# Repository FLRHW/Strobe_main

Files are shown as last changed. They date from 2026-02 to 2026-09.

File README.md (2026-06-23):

<h1 align="center">Main board</h1>

<p align="center" width="100%">
  <a href="https://github.com/FLRHW/Strobe_main/actions/workflows/ci.yaml">
    
  </a>
</p>

<p align="center" width="100%">
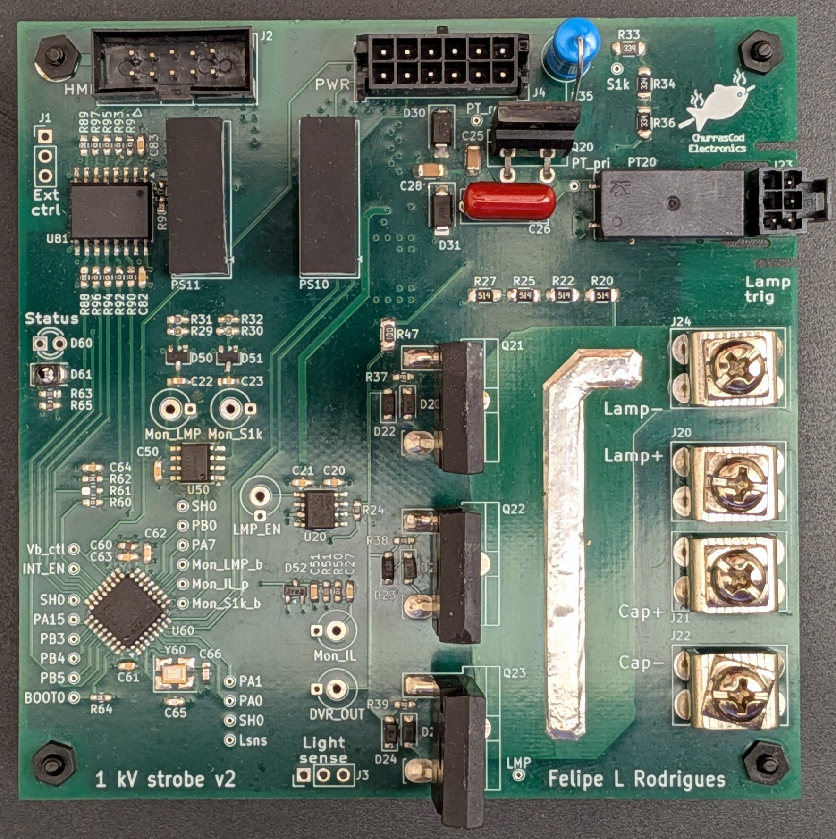
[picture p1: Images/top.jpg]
    
</p>

***

<p align="center">
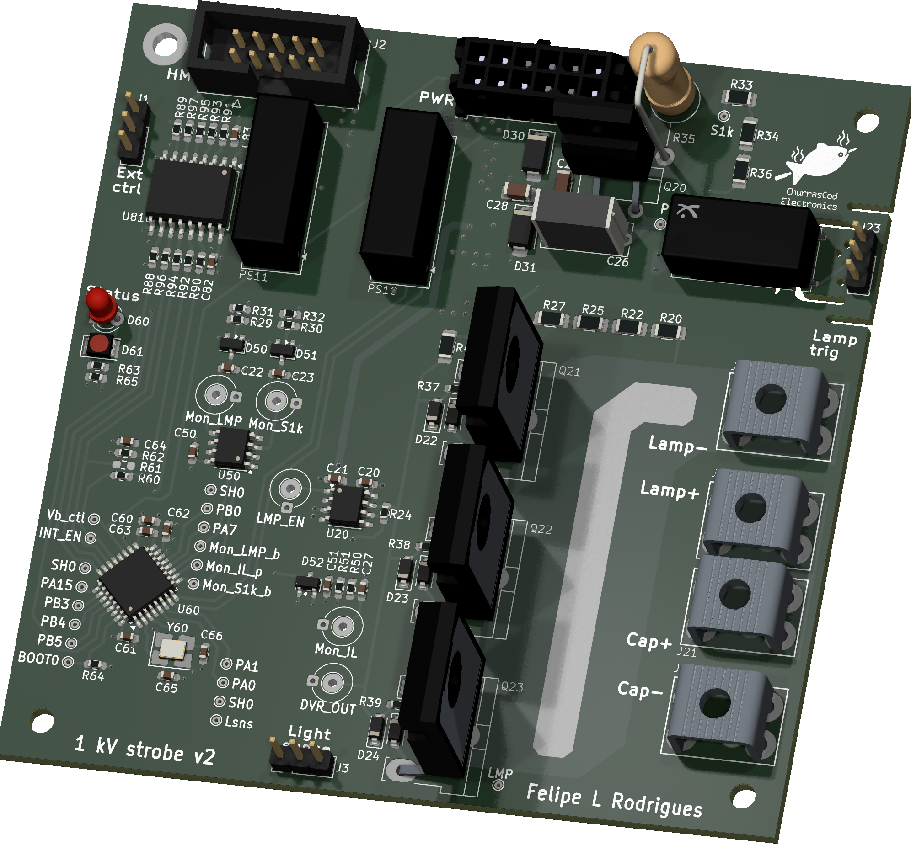
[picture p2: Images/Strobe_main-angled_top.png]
3D Top Angled
  
&nbsp; &nbsp; &nbsp; &nbsp;
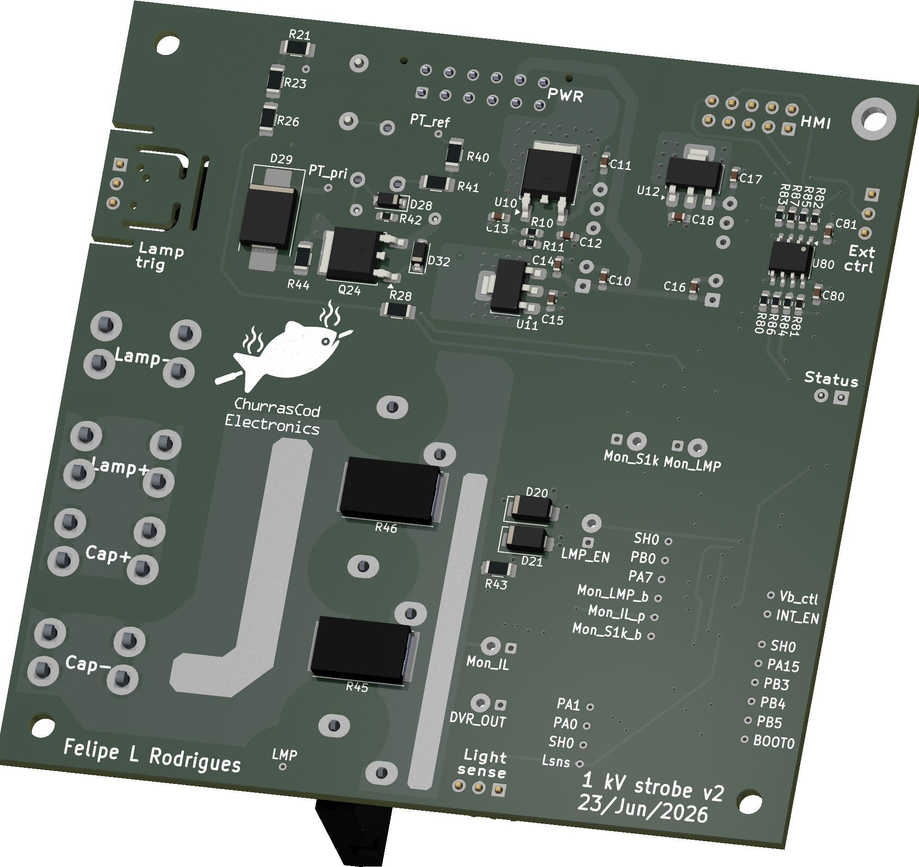
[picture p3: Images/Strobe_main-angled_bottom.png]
3D Bottom Angled
  
</p>

***

# **1 kV strobe - Intro**
Since my teenage years I spend a great chunk of my spare time on hobby electronics. Back then, much of that time was to build FM transmitters, audio amplifiers and strobe lights. I was always pushing my builds as much as I could, (i.e., extracting pressurised smoke from capacitors!) as an attempt to make the flashes ever brighter. It was somewhat challenging given the limited experience and resources I had at the time, but a lot of fun nonetheless.
Life went on, priorities changed and for a long time I did not "play" with strobe lights... until recently, after I saw a large XOP-15 bulb for sale and, well, nostalgy happened.

While defining the project scope, I had to decide if I'd use the good old Xenon bulb or move to LEDs, as these have greatly evolved and are ubiquitous nowadays, making their way to commercial strobes (https://www.martin.com/en/products/atomic-3000-led). I have decided to stick to vintage tech, as in my mind this would bring more interesting power electronics challenges due to high voltages and high peak currents required when the lamp is ionised.

So that's what this repo contains: a Xenon-based strobe light, aiming to drive a XOP-15 bulb with up to 1 kV, while controlling the duration and frequency of pulses.

## Project overview
This repository contains KiCad v9 design files for the main board of a Xenon-based strobe light system.
The system is divided into three separate modules:

- Main board. This board drives the Xenon bulb, generating the trigger pulse and actively interrupting the discharge according to the required pulse width. The latest STM32 source code is kept on a separate repository:  
https://github.com/FLRHW/Strobe_main_source  

- HMI board. This is the user interface, to capture desired operating conditions (bus voltage, pulse width and pulse frequency). That board is covered on a separate repository:  
https://github.com/FLRHW/Strobe_HMI  

- Power supply. This is to produce an adjustable DC supply and to realise that I intend to eventually design an AC-mains powered converter, including a PFC circuit. As an interim solution, off-the-shelf boost converter modules are used: two such modules are connected in series, each providing up to 450 V output while supplied by 12 V batteries. As a side project, the boost modules have been reverse engineered with the aim to modify them from non-isolated to isolated. This work is covered under the following repos:
https://github.com/FLRHW/StepUp_module_12to450V  
https://github.com/FLRHW/Isolated_12to450V.

## Design targets
DC bus voltage: 400 V to 1000 V  
Flash rate: 0.1 Hz to 200 Hz  
Pulse duration: 20 μs to 10 ms  

Please note that the above parameters are only the limits encoded in the software. This design relies on storing energy on a capacitor bank to then discharge it into the bulb, so, even though the limit in software for the pulse duration is 50 % of the period, long durations might be unachievable. The duration strongly depends on the lamp, capacitor bank and bus voltage. As an example, with the XOP-15 and a 400 uF bank charged to 700 V, the discharge current reaches 450 A and the bank voltage collapses in less than 1 ms. Additionally, the HV power supply will determine how fast the capacitor bank is recharged, limiting the flash rate and/or pulse duration.

## Intended use
This repository is intended for:
* Educational use and study of the circuit;
* Integration into hobby or research projects.

## License
The design files and documentation in this repository are released under the CERN Open Hardware Licence v2 – Permissive (CERN‑OHL‑P‑2.0). SPDX identifier: CERN-OHL-P-2.0 See the LICENSE file for the full legal text and conditions.
In short and non‑legal terms, you are free to use, modify, manufacture, and distribute hardware based on these files, provided you respect attribution requirements and the terms in the license.

## Trademarks and third‑party rights
All product names, logos, and brands eventually mentioned are the property of their respective owners and are not included or licensed here.
Any reference to third‑party marks is purely descriptive and does not imply endorsement or affiliation.

## Safety and disclaimer
* The author takes no responsibility for any injury, death or damage arising from the use, direct or indirect, of the design or otherwise any information from this repository
* You shall not build this or any prototype based on this design unless you are absolutely sure of your abilities dealing with this type of circuit
* High voltage can cause injury, death, or damage to equipment. Ensure appropriate protections and testing procedures are followed
* The design is provided as is, with no warranty of any kind
* Users are responsible for checking any patent, copyright, or regulatory constraints that may apply to their own use

## Known issues / improvement potentials
- To be updated once prototype is tested

***

## DIRECTORY STRUCTURE
    │
    ├─ Computations       # Misc calculations
    ├─ HTML               # HTML files for generated webpage
    ├─ Images             # Pictures and renders
    │
    ├─ kibot_resources    # External resources for KiBot
    │  ├─ colors          # Color theme for KiCad
    │  ├─ fonts           # Fonts used in the project
    │  ├─ scripts         # External scripts used with KiBot
    │  └─ templates       # Templates for KiBot generated reports
    │
    ├─ kibot_yaml         # KiBot YAML config files
    ├─ KiRI               # KiRI (PCB diff viewer) files
    │
    ├─ lib                # KiCad footprint and symbol libraries
    │  ├─ 3d_models       # Component 3D models
    │  ├─ lib_fp          # Footprint libraries
    │  └─ lib_sym         # Symbol libraries
    │
    ├─ Logos              # Logos
    │
    ├─ Manufacturing      # Assembly and fabrication documents
    │  ├─ Assembly        # Assembly documents (BoM, pos, notes)
    │  │
    │  └─ Fabrication     # Fabrication documents (ZIP, notes)
    │     ├─ Drill Tables # CSV drill tables
    │     └─ Gerbers      # Gerbers
    │
    ├─ Report             # Reports for ERC/DRC
    ├─ Schematic          # PDF of schematic
    ├─ Templates          # Title block templates
    ├─ Testing
    │  └─ Testpoints      # Testpoints tables      
    │
    └─ Variants           # Outputs for assembly variants

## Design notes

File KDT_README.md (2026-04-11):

<h1 align="center">KiCad 8/9 Template for CI/CD with KiBot</h1>

<p align="center">
  <a href=https://www.kicad.org/>
    Light
  </a>
&nbsp; &nbsp; &nbsp; &nbsp;
  <a href=https://kibot.readthedocs.io/en/latest/>
    Dark
  </a>
</p>

A **KiCad 8/9** template for **automated**, professional documentation generation with **Continuous Integration and Continuous Development** (CI/CD) using [KiBot](https://github.com/INTI-CMNB/KiBot/tree/master).

A video tutorial for setting up this template is available [here](https://www.youtube.com/watch?v=63R6Wnx44uY).

An example project using this template can be found [here](https://github.com/nguyen-v/amulet_controller_kibot/tree/master).

> [!NOTE]
> This file will be overridden by a KiBot run.

## TABLE OF CONTENTS

- [TABLE OF CONTENTS](#table-of-contents)
- [FEATURES](#features)
- [GETTING STARTED](#getting-started)
- [USAGE](#usage)
  - [CI/CD Workflow and Semantic Versioning](#cicd-workflow-and-semantic-versioning)
  - [Running Locally](#running-locally)
  - [Calculating Board Costs (KiCost)](#calculating-board-costs-kicost)
  - [Visualizing Outputs in a Webpage](#visualizing-outputs-in-a-webpage)
- [PROJECT CONVERSION GUIDE](#project-conversion-guide)
  - [Folders](#folders)
  - [Schematic](#schematic)
  - [PCB](#pcb)
  - [Summary in table format](#summary-in-table-format)
- [DIRECTORY STRUCTURE](#directory-structure)
- [CREDITS](#credits)
- [RESOURCES](#resources)
- [CONTRIBUTING](#contributing)

## FEATURES

- **Automated fabrication document**: [Example](https://github.com/nguyen-v/amulet_controller_kibot/blob/master/Manufacturing/Fabrication/amulet_controller-fabrication.pdf). The stackup table, fabrication notes, drill drawings/tables, testpoint tables/highlighting are all automated.
  
- **Automated assembly document**: [Example](https://github.com/nguyen-v/amulet_controller_kibot/blob/master/Manufacturing/Assembly/amulet_controller-assembly.pdf). The images, tables, DNP crosses, texts are all automated.

- **Automated table of contents** in schematic

- **Automated 3D images** of the PCB in various documents

- **Synchronised `CHANGELOG.md`** with Revision History page of the schematic

- **Automated README.md**: images and other board information

- **Various outputs** such as gerbers, 3D renders, ERC/DRC reports, BoM, Diff visualizer

- **Modern webpage** for visualizing the generated files and documents

- **Robust workflow** with two branches and semantic versioning

- **Releases with changelog** and assets

- **Can be run locally** with Docker

## GETTING STARTED

1. Go to your KiCad templates folder
   
    **Windows**:

    ```
    cd "C:\Program Files\KiCad\8.0\share\kicad\template"
    ```

    **Linux**:
    ```
    cd /usr/share/kicad/template
    sudo chmod 777 ./
    ```

2. Clone the repository

    ```
    git clone git@github.com:nguyen-v/KDT_Hierarchical_KiBot.git
    ```

3. Install the fonts inside of [`kibot_resources/fonts`](kibot_resources/fonts) if not already installed on the system.

4. A custom color theme ([`Altium_Theme.json`](kibot_resources/colors/Altium_Theme.json)) is also provided in [`kibot_resources/colors`](kibot_resources/colors).
You should move this file to your KiCad Themes folder.

    **Windows**:

    `C:\Users\<USER_NAME>\AppData\Roaming\kicad\8.0\colors`

    **Linux**:

    `~/.config/kicad/8.0/colors`

> [!NOTE]
> In the steps above, replace ```8.0``` with ```9.0``` for KiCad 9

5. Create a new project with:

    **File → New Project From Template** and select `KDT_Hierarchical_KiBot`

> [!CAUTION]
> Under Linux, the ```.github``` folder from the template needs to be copied at the root of the project directory, as it is not copied when creating a project from a template in KiCad.

6. Create a new `dev` branch. This will be the working branch. 
   
   ```
   git checkout -b dev
   ```
   
7. Modify the following fields in [`kibot_main.yaml`](kibot_yaml/kibot_main.yaml#L556) according to your project:
    ```
      # Metadata ===================================================================

      PROJECT_NAME: Project Name
      BOARD_NAME: Board Name

      COMPANY: Company Name
      DESIGNER: Author

      LOGO: 'Logos/dummy_logo.png'
      GIT_URL: 'https://github.com/nguyen-v/KDT_Hierarchical_KiBot'

      # Preflight ==================================================================

      CHECK_ZONE_FILLS: false
      STACKUP_TABLE_NOTE: external layer thicknesses are specified after plating

      # BoM ========================================================================

      MPN_FIELD: 'Manufacturer Part Number'
      MAN_FIELD: 'Manufacturer'

      # Drill table and drill map parameters =======================================

      GROUP_ROUND_SLOTS: true  # whether or not to group round holes and slots
      GROUP_PTH_NPTH: 'no'  # for drill tables (CSV, PCB Print)
      GROUP_PTH_NPTH_DRL: false  # for .drl files

      # Gerber parameters ==========================================================

      PLOT_REFS: true # reference designators

      # Schematic parameters =======================================================

      COLOR_THEME: Altium_Theme
      SHEET_WKS: ${KIPRJMOD}/Templates/KDT_Template_PCB_GIT_A4.kicad_wks
      FAB_SCALING: 1
      ASSEMBLY_SCALING: 1

      # References to exclude from testpoint highlighting ==========================
      
      EXCLUDE_REFS: '[MB*]' # for components on the PCB but not on the schematic

      # 3D Viewer rotations (in steps) =============================================

      3D_VIEWER_ROT_X: 2
      3D_VIEWER_ROT_Y: -1
      3D_VIEWER_ROT_Z: 1
      3D_VIEWER_ZOOM: -1
      KEY_COLOR: '#00FF00' # background color to remove
    ```

8. The files inside of [`kibot_resources/templates`](kibot_resources/templates) should also be modified according to your project. These include Assembly and Fabrication notes, Impedance table and README file templates.

9. Edit the [`*.kicad_dru`](KDT_Hierarchical_KiBot.kicad_dru) if necessary according to your design rules. Right now, it has been set for PCBWay 6-layer PCBs with 2oz outer 1oz inner, focusing on lowest cost.

10.  Edit the [`kibot_out_csv_bom.yaml`](kibot_yaml/kibot_out_csv_bom.yaml), [`kibot_out_html_bom.yaml`](kibot_yaml/kibot_out_html_bom.yaml) and [`kibot_out_xlsx_bom.yaml`](kibot_yaml/kibot_out_xlsx_bom.yaml) files according to the component fields that you use. You can refer to the [KiCost Documentation](https://hildogjr.github.io/KiCost/docs/_build/singlehtml/index.html) for the field names.

## USAGE

### CI/CD Workflow and Semantic Versioning

This template is meant to be used in a CI/CD environment on GitHub. The workflow is as follows:

- Any custom font used in the project must be added to the [`kibot_resources/fonts`](kibot_resources/fonts) folder.

> [!NOTE]
> KiCad 9 allows for fonts to be embedded in the schematic. However, it is still good practice to add the fonts in the folder mentioned.

- There are two branches, a `main` and a `dev` branch. The `dev` branch is the working branch. The `main` should only be used for pull requests and releases.

- Changes should be recorded in the [`CHANGELOG.md`](CHANGELOG.md) file, and should respect [semantic versioning guidelines](https://semver.org/) for [hardware](https://www.maskset.net/blog/2023/02/26/semantic-versioning-for-hardware/). The changes of the current version should be added under the `[Unreleased]` section.

- The `variant` variable in [.github/workflows/ci.yaml](.github/workflows/ci.yaml#L21) should be selected according to the project progress.

  ```
    # Used variant. We assume:
    # DRAFT: only schematic in progress, will only generate schematic PDF, netlist and BoM
    # PRELIMINARY: will generate both schematic and PCB documents, but no ERC/DRC
    # CHECKED: will generate both schematic and PCB documents, with ERC/DRC
    # RELEASED: similar to CHECKED, automatically selected when pushing a tag to master

    kibot_variant: CHECKED  
  ```

- The `kicad_version` variable in [.github/workflows/ci.yaml](.github/workflows/ci.yaml#L24) should be selected according to the desired KiCad version. Supported versions are 8 and 9.

- You should work locally on the `dev` branch. When a change is made, the changes should be pushed to GitHub which will trigger the KiBot workflow. The generated files will be committed and pushed back to the repository.

- After a successful KiBot run on the remote repository, you should pull back the changes into your local repository.

- To avoid conflicts, you should avoid modifying the `.kicad_pro` file locally before pulling from the remote (after the completion of a KiBot run). Otherwise, you will need to solve merge conflicts when pulling the file.

- To synchronise the Revision History of the schematic with the `CHANGELOG.md` file, you should create new text variables in [kibot_pre_set_text_variables.yaml](kibot_yaml/kibot_pre_set_text_variables.yaml#L39). The text variables should then be added in the text boxes of the Revision History sheet.

  ```
  - variable: '@RELEASE_TITLE_VAR@x.x.x'
    command: '@GET_TITLE_CMD@ x.x.x'
  - variable: '@RELEASE_BODY_VAR@x.x.x'
    command: '@GET_BODY_CMD@ x.x.x'
  ```

- When ready for a release, you should open a pull request and merge the changes into main. Currently the workflow is set **not to trigger on pull requests**, as we assume the changes coming from `dev` are up-to-date.

- To create a release, push a tag on the `main` branch with the version number (for example `x.x.x = 1.1.1`):

  ```
  git checkout main
  git pull
  git tag x.x.x
  git push origin x.x.x
  ```

  This will start a KiBot run with the variant set as `RELEASED`. When the run completes, it also creates a release with assets and updates the `CHANGELOG.md` file (renames the `[Unreleased]` section with the pushed tag and creates a new `[Unreleased]` section).

- After a release, you will need to update your `main` branch to be up-to-date with the remote:

  ```
  git pull
  ```

  And you will also need to rebase your `dev` branch to the `main` branch:

  ```
  git checkout dev
  git rebase main
  ```

> [!NOTE]
> You are free to modify the [.github/workflows/ci.yaml](.github/workflows/ci.yaml) file to suit your workflow needs.

***

### Running Locally

KiBot can be installed if you want to run some of the scripts locally. If you only plan to use it in a CI/CD workflow, this step can be skipped.
Installation steps can be found on the [official documentation](https://kibot.readthedocs.io/en/master/installation.html). 
The easiest way to install KiBot if custom development is not required is with dockers.

1.  Install **and run** [Docker Desktop](https://docs.docker.com/desktop/)
  
2.  Run the script `docker_kibot_windows.bat` or `docker_kibot_linux.sh` depending on your platform in [`kibot_resources/scripts`](kibot_resources/scripts). Currently tested on Windows and WSL2. This should pull and start a docker running the `dev` branch of KiBot. You should have access to your local files.

***
**KiCad 8**

  Windows:

  ```
  .\docker_kibot_windows.bat
  ```

  Linux:

  ```
  ./docker_kibot_linux.sh
  ```

***
**KiCad 9**

  Windows:

  ```
  .\docker_kibot_windows.bat -v 9
  ```

  Linux:

  ```
  ./docker_kibot_linux.sh -v 9
  ```
  ***

Once in the docker, you can use the [`kibot_launch.sh`](kibot_launch.sh) script to generate and visualize outputs.

```
./kibot_launch.sh
```

You can get more information about the usage with

```
./kibot_launch.sh --help
```

When running the script with no arguments, it will default to the `CHECKED` variant and generate all outputs. A variant can be set with the `-v` flag. If a custom variant is used (i.e. other than the default variants `DRAFT`, `PRELIMINARY`, `CHECKED`, `RELEASED`), the outputs will be generated in the `Variants` folder.

Each default variant will have different KiBot flags, which is useful for different phases of the project:

1. **DRAFT**
  
   Only schematic in progress, will only generate schematic PDF, netlist and BoM

2. **PRELIMINARY**
   
   Will generate both schematic and PCB documents, but no ERC/DRC

3. **CHECKED**
   
   Will generate both schematic and PCB documents, with ERC/DRC

4. **RELEASED**
   
   Similar to CHECKED, automatically selected when pushing a tag to main (CI/CD)

> [!WARNING]
> When generating outputs locally, it could conflict with the outputs generated by the remote CI/CD workflow. In this case, you should decide how to resolve the conflicts.

***

### Calculating Board Costs (KiCost)

[KiCost](https://github.com/hildogjr/KiCost) is used to estimate costs and get a nice XLSX spreadsheet with part specs. In this project, we run KiCost locally to avoid too many API calls. Also, DigiKey's API [doesn't seem to work](https://github.com/set-soft/kicost_ci_test) in a CI/CD environment.
To run KiCost, you will need to create a file `kicost_config_local.yaml` in [`kicost_yaml`](kicost_yaml). You can use the [`kicost_config_local_template.yaml`](kicost_yaml/kicost_config_local.yaml) file as a base. Once you have filled in the API keys for the desired manufacturers, KiCost can be run with:

```
./kibot_launch.sh --costs
```
This will create a spreadsheet in [`Manufacturing/Assembly`](Manufacturing/Assembly/) folder.

You can also specify a variant if desired:

```
./kibot_launch.sh -v <VARIANT> --costs
```

For more information, please have a look at the official [documentation](https://hildogjr.github.io/KiCost/docs/_build/singlehtml/index.html)

> [!CAUTION]
> KiCost expects the **MPN (Manufacturer Part Number)** and **Manufacturer** fields to be named in a certain way. To cater for different naming conventions, we rename user-defined fields to KiCost-compatible fields in the KiBot run. You can set your user-defined field for **MPN** and **Manufacturer** in the [`kibot_yaml/kibot_main.yaml`](kibot_yaml/kibot_main.yaml#L576) by editing the `MPN_FIELD` and `MAN_FIELD` definitions.

<p align="center">
  XLSX BoM
</p>

<p align="center">
  XLSX Costs
</p>

<p align="center">
  XLSX Specs
</p>

***

### Visualizing Outputs in a Webpage

The outputs of KiBot can be visualized in a webpage (excepted for the `DRAFT` variant). This can be done by running:

```
./kibot_launch.sh --server
```
And opening `http://localhost:8000` in your favorite browser. The server can be shut down with:
```
./kibot_launch.sh --stop-server
```

> [!TIP]
> You can also give the port as an argument if you want to use another port.

<p align="center">
  Web Page
</p>

## PROJECT CONVERSION GUIDE

This section will describe the necessary steps to convert an existing project to work with this template. This will also give more insights into how the template works in general. For more information, you should refer to the template.

***

### Folders

You should keep the folder structure as defined in [DIRECTORY STRUCTURE](#directory-structure). The folders marked as optional are not mandatory for the project to work, as long as the relevant file paths are correct (e.g. logos). You should then go through the same steps as in [GETTING STARTED](#getting-started) and [USAGE](#usage).

### Schematic

You should select [`Templates/KDT_Template_GIT.kicad_wks`](Templates/KDT_Template_GIT.kicad_wks) as your Drawing Sheet in:

**File → Page Settings → Drawing Sheet**

On the same page, The `Revision` and `Company` fields should be set to `${REVISION}` and `${COMPANY}` and exported to all sheets.

<p align="center">
  Drawing Sheet
</p>

For an automated table of contents, you should copy the root page of the template into your project, or use the `${SHEET_NAME_X}` text variables. These variables will be replaced by the sheet name (page `X`) when running KiBot. Currently the maximum number of pages is set to 40. You are free to add new text variables in [`kibot_yaml/kibot_pre_set_text_variables`](kibot_yaml/kibot_pre_set_text_variables.yaml#L160).

The `${VARIANT}` text variable is replaced by the current variant name (e.g. DRAFT or RELEASED). 

The `${RELEASE_DATE}` and `${RELEASE_DATE_NUM}` will be replaced by the tag release date and are just the same date in different formats (for example, `${RELEASE_DATE} = 17-Dec-2024` and `${RELEASE_DATE_NUM} = 2024-12-17`).

To get 3D pictures of the PCB in the schematic, you can create text boxes with the desired size, with the following names: `kibot_image_png_3d_viewer_angled_top` and `kibot_image_png_3d_viewer_angled_bottom`.

<p align="center">
  kibot_image_png_3d_viewer_angled_top, kibot_image_png_3d_viewer_angled_bottom
</p>

> You can add any image generated by a KiBot output using by changing the name to `kibot_image_<output_name>`.

To synchronise the Revision History of the schematic with the `CHANGELOG.md` file, you should create new text variables in [kibot_pre_set_text_variables.yaml](kibot_yaml/kibot_pre_set_text_variables.yaml#L39). The text variables (`${RELEASE_TITLE_VAR<VERSION>}` and `${RELEASE_BODY_VAR<VERSION>`) should then be added in the text boxes of the Revision History sheet.

  ```
  - variable: '@RELEASE_TITLE_VAR@x.x.x'
    command: '@GET_TITLE_CMD@ x.x.x'
  - variable: '@RELEASE_BODY_VAR@x.x.x'
    command: '@GET_BODY_CMD@ x.x.x'
  ```

***

### PCB

The layer names of the PCB should follow the ones defined in [kibot_main.yaml](kibot_yaml/kibot_main.yaml#L631). 

```
  LAYER_TITLE_PAGE: TitlePage
  LAYER_DNP_TOP: F.DNP
  LAYER_DNP_BOTTOM: B.DNP
  LAYER_DRILL_MAP: DrillMap
  LAYER_TP_LIST_TOP: F.TestPointList
  LAYER_TP_LIST_BOTTOM: B.TestPointList
  LAYER_ASSEMBLY_TEXT_TOP: F.AssemblyText
  LAYER_ASSEMBLY_TEXT_BOTTOM: B.AssemblyText
  LAYER_DNP_CROSS_TOP: F.DNP
  LAYER_DNP_CROSS_BOTTOM: B.DNP
```

<p align="center">
  PCB Layer Names
</p>

The layer names can be set in 

**File → Board Setup → Board Stackup → Board Editor Layers**

Each layer has a specific function, and must be setup in a particular way.

In the following explanation, when a group must be created, this can be done using KiCad's **Draw Rectangle** tool, and then a group can be created with:

**Right-Click → Grouping → Group Items**

Pressing **E** then allows you to rename the group. The size and position of the group usually determines the size and location of the element to be drawn. To change the font inside a group, you can create a textbox with the desired font in the group. You can set the border width to 0.

<p align="center">
  Textbox Group
</p>

***

**TitlePage**

This is used for the first page of the assembly document. Here, you should add **Top View** and **Bottom View** texts and under these text, you can create two named groups with the location and size that you desire. The groups should be named `kibot_image_png_3d_viewer_angled_top` and `kibot_image_png_3d_viewer_angled_bottom`.

> [!TIP]
> You can add any image generated by a KiBot output using by changing the name to `kibot_image_<output_name>`.

<p align="center">
  TitlePage
</p>

<p align="center">
  kibot_image_png_3d_viewer_angled_top
&nbsp; &nbsp; &nbsp; &nbsp;
  kibot_image_png_3d_viewer_angled_bottom
</p>

***

**User.Comments**

Currently not used, you can use it for your project.

***

**F.DNP** and **B.DNP**

These are used to hold the red crosses for components marked as *Do Not Populate*. The layers for those should be kept empty.

***

**DrillMap**

This layer is used to draw drill map drawings and drill tables in the fabrication document. You should create a named group called `kibot_table_csv_drill_table` and place it where the drill tables should be drawn for each drill layer pair. The drill drawing is by default aligned with the PCB.

<p align="center">
  DrillMap
  kibot_table_csv_drill_table
</p>

***

**F.TestPoint** and **B.TestPoint**

These layers are used to highlight testpoint locations in the fabrication document. They should be left as empty.

***

**F.AssemblyText**

This layer is used to hold information about the number of components, assembly notes, assembly drawing and 3D render of the top of the PCB. For the number of components, you should create a group named `kibot_table_csv_comp_count`. Assembly notes should be added using the text variable `${ASSEMBLY_NOTES}`. The 3D render can be added by creating a group named `kibot_image_png_3d_viewer_top`.

<p align="center">
  F.AssemblyText
  kibot_image_png_3d_viewer_top
</p>

<p align="center">
  kibot_table_csv_comp_count
&nbsp; &nbsp; &nbsp; &nbsp;
  ${ASSEMBLY_NOTES}
</p>

**B.AssemblyText**

This layer hold the assembly drawing and 3D render for the backside of the PCB. For the 3D render, you should add a group named `kibot_image_png_3d_viewer_bottom`.

***

**F.Dimensions**

This layer holds information about the PCB stackup and dimensions, impedance table and fabrication notes. The PCB stackup can be added by creating a group named `kibot_fancy_stackup`. The impedance table with a group named `kibot_table_csv_impedance_table` and the fabrication notes are included with the text variable `${FABRICATION_NOTES}`.

> [!NOTE]
> The text variable ${FABRICATION_NOTE} is dependent on the [`kibot_resources/templates/fabrication_notes.txt`](kibot_resources/templates/fabrication_notes.txt) file. Modify it to your needs.

<p align="center">
  F.Dimensions
  kibot_fancy_stackup
</p>

<p align="center">
  kibot_table_csv_impedance_table
  ${FABRICATION_NOTES}
</p>

**B.Dimensions**

This layer contains information about the dimensions of the PCB, seen from the backside. Similarly to the front side, you can use KiCad's **Dimensions** tool to add some dimensions.

<p align="center">
  B.Dimensions
</p>

***

**F.TestPointList**

This layer is used to hold information about the testpoints locations and nets. You can add testpoint tables by creating a group named `kibot_table_csv_testpoints_top`. It is also possible to use python slicing to separate the table into multiple tables, by using slice operators in the name. For example: `kibot_table_csv_testpoints_top[:32]` and `kibot_table_csv_testpoints_top[32:]` in two different groups would create two tables with the first one including the first 32 testpoints and the second one every testpoint after that.

Test point locations are computed from the drill origin, which can be set with:

**Place → Drill/Place File Origin**.

> [!TIP]
> It is usually good practice to set the origin at the bottom left of the board.

<p align="center">
  F.TestPointList
</p>

<p align="center">
  kibot_table_csv_testpoints_top[:32]
&nbsp; &nbsp; &nbsp; &nbsp;
  kibot_table_csv_testpoints_top[32:]
</p>

**B.TestPointList**

Similar to the front testpoint layer. The group should be named `kibot_table_csv_testpoints_bottom`. Note that because PCB is inverted for this layer during print, if the group is placed on the left side it will be printed on the right side.

<p align="center">
  B.TestPointList
</p>

<p align="center">
  kibot_table_csv_testpoints_bottom
</p>

***

### Summary in table format

| **Layer** | **Description** | **Changes/Included Items** |
|---|---|---|
| **TitlePage** | First page of the assembly document. | Add groups: `kibot_image_png_3d_viewer_angled_top` and `kibot_image_png_3d_viewer_angled_bottom`. |
| **User.Comments** | Reserved for project-specific comments. | Not used by default; customize as needed. |
| **F.DNP / B.DNP** | Holds red crosses for components marked as *Do Not Populate*. | Keep these layers empty. |
| **DrillMap** | Draws drill map drawings and tables in the fabrication document, aligned by default with the PCB.  | Add group: `kibot_table_csv_drill_table`. |
| **F.TestPoint / B.TestPoint** | Highlights testpoint locations in the fabrication document. | Keep these layers empty. |
| **F.AssemblyText** | Contains component count, assembly notes, drawings, and 3D renders for the top side of the PCB. | Add group: `kibot_table_csv_comp_count` (table) and `kibot_image_png_3d_viewer_top` (image). Include `${ASSEMBLY_NOTES}` text.|
| **B.AssemblyText** | Holds assembly drawings and 3D render for the bottom side of the PCB. | Add group: `kibot_image_png_3d_viewer_bottom` for the 3D render. |
| **F.Dimensions** | Holds PCB stackup, dimensions, impedance table, and fabrication notes. | Add groups: `kibot_fancy_stackup` (stackup), `kibot_table_csv_impedance_table` (impedance table), and `${FABRICATION_NOTES}`. |
| **B.Dimensions** | Holds dimensions of the PCB, seen from the backside. | Use KiCad **Dimensions** tool to add details. |
| **F.TestPointList** | Lists testpoint locations and nets for the top layer. | Add group: `kibot_table_csv_testpoints_top`. Use slicing (e.g., `[:32]`) for multiple tables. |
| **B.TestPointList** | Lists testpoint locations and nets for the bottom layer. | Add group: `kibot_table_csv_testpoints_bottom`. Adjust left-side placements for inverted print alignment. |

## DIRECTORY STRUCTURE
The following directory structure is used in the template. Folders marked as 'optional' are not crucial for KiBot to work. Other folders will be generated automatically during a KiBot run.

```
├─ Computations       # Misc calculations (optional)
├─ HTML               # HTML files for generated webpage
├─ Images             # Pictures and renders
│
├─ kibot_resources
│  ├─ colors          # Color theme for KiCad
│  ├─ fonts           # Fonts used in the project
│  ├─ scripts         # External scripts used with KiBot
│  └─ templates       # Templates for KiBot generated reports
│
├─ kibot_yaml         # KiBot YAML config files
├─ KiRI               # KiRI (PCB diff viewer) files
│
├─ lib                # Footprint and symbol libraries (optional)
│  ├─ 3d_models       # Component 3D models
│  ├─ lib_fp          # Footprint libraries
│  └─ lib_sym         # Symbol libraries
│
├─ Logos              # Logos (optional)
│
├─ Manufacturing
│  ├─ Assembly        # Assembly documents (BoM, pos, notes)
│  │
│  └─ Fabrication     # Fabrication documents (ZIP, notes)
│     ├─ Drill Tables # CSV drill tables
│     └─ Gerbers      # Gerbers
│
├─ Report             # Reports for ERC/DRC
├─ Schematic          # PDF of schematic
├─ Templates          # Title block templates
├─ Testing
│  └─ Testpoints      # Testpoints tables      
│
└─ Variants           # Outputs for assembly variants (optional)
```

## CREDITS

[@set-soft](https://github.com/set-soft) for his amazing work on [KiBot](https://github.com/INTI-CMNB/KiBot/tree/master). Check out the [documentation](https://kibot.readthedocs.io/en/latest/) for more!

## RESOURCES

- [Video Tutorial for this template](https://www.youtube.com/watch?v=63R6Wnx44uY)

- [Example project (from the video tutorial)](https://github.com/nguyen-v/KiBot_Project_Test)

- [Example project (Amulet)](https://github.com/nguyen-v/amulet_controller_kibot/tree/master)

- [(Outdated) Best practices and tips for good schematics](https://www.youtube.com/watch?v=_ZjyeltLMAg)

- [GitHub Actions Documentation](https://docs.github.com/en/actions)

- [KiBot Documentation](https://kibot.readthedocs.io/en/latest/)

- [KiBot Repository](https://github.com/INTI-CMNB/KiBot)

- [KiCost Documentation](https://hildogjr.github.io/KiCost/docs/_build/singlehtml/index.html)

- [KiCost Repository](https://github.com/hildogjr/KiCost)

- [KiRI Repository](https://github.com/leoheck/kiri)

## CONTRIBUTING

Feel free to open a pull request if you have any cool features to add!

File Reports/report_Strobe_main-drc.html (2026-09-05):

Logo

(https://github.com/INTI-CMNB/KiBot/) | DRC report for Strobe_main
| PCB: Strobe_main Revision: 2.0.1 Date: 2026-09-05T13:06:58+0000 KiCad Version: 9.0.7 | Errors: 0 Warnings: 23 Total: 23

Violations

Type | Description | Details
lib_footprint_issues | The current configuration does not include the footprint library 'Personal'. | @(180.77 mm, 100.0 mm): Footprint TP22
lib_footprint_issues | The current configuration does not include the footprint library 'Personal'. | @(199.5 mm, 136.0 mm): Footprint TP20
lib_footprint_issues | The current configuration does not include the footprint library 'Personal'. | @(251.0 mm, 135.5 mm): Footprint J22
lib_footprint_issues | The current configuration does not include the footprint library 'Personal'. | @(199.5 mm, 128.5 mm): Footprint TP28
lib_footprint_issues | The current configuration does not include the footprint library 'Personal'. | @(254.5 mm, 72.73 mm): Footprint H22
lib_footprint_issues | The current configuration does not include the footprint library 'Personal'. | @(251.0 mm, 121.0 mm): Footprint J21
lib_footprint_issues | The current configuration does not include the footprint library 'Personal'. | @(255.5 mm, 71.5 mm): Footprint H20
lib_footprint_issues | The current configuration does not include the footprint library 'Personal'. | @(243.0 mm, 74.0 mm): Footprint PT20
lib_footprint_issues | The current configuration does not include the footprint library 'Personal'. | @(251.0 mm, 109.5 mm): Footprint J20
lib_footprint_issues | The current configuration does not include the footprint library 'Personal'. | @(191.0 mm, 112.5 mm): Footprint TP21
lib_footprint_issues | The current configuration does not include the footprint library 'Personal'. | @(251.0 mm, 95.0 mm): Footprint J24
lib_footprint_issues | The current configuration does not include the footprint library 'Personal'. | @(218.5 mm, 99.0 mm): Footprint Q21
lib_footprint_issues | The current configuration does not include the footprint library 'Personal'. | @(200.04 mm, 73.04 mm): Footprint PS10
lib_footprint_issues | The current configuration does not include the footprint library 'Personal'. | @(225.5 mm, 66.5 mm): Footprint Q20
lib_footprint_issues | The current configuration does not include the footprint library 'Personal'. | @(183.54 mm, 73.04 mm): Footprint PS11
lib_footprint_issues | The current configuration does not include the footprint library 'Personal'. | @(188.5 mm, 100.0 mm): Footprint TP23
lib_footprint_issues | The current configuration does not include the footprint library 'Personal'. | @(255.5 mm, 76.5 mm): Footprint H21
lib_footprint_issues | The current configuration does not include the footprint library 'Personal'. | @(218.5 mm, 141.0 mm): Footprint Q23
lib_footprint_issues | The current configuration does not include the footprint library 'Personal'. | @(218.5 mm, 120.0 mm): Footprint Q22
lib_footprint_issues | The current configuration does not include the footprint library 'Personal'. | @(216.5 mm, 131.0 mm): Footprint R45
lib_footprint_issues | The current configuration does not include the footprint library 'Personal'. | @(216.5 mm, 110.0 mm): Footprint R46

Schematic parity

Type | Description | Details
footprint_symbol_mismatch | Value (C22) doesn't match symbol value (100n). | @(180.5 mm, 96.5 mm): Footprint C22
footprint_symbol_mismatch | Value (C23) doesn't match symbol value (100n). | @(187.0 mm, 96.5 mm): Footprint C23

Generated by KiBot (https://github.com/INTI-CMNB/KiBot/) v1.9.2

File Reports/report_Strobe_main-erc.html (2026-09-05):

Logo

(https://github.com/INTI-CMNB/KiBot/) | ERC report for Strobe_main
| Schematic: Strobe_main Revision: 2.0.1 Date: 2026-09-05T13:06:51+0000 KiCad Version: 9.0.7 | Errors: 0 Warnings: 239 Total: 239

Sheet / (Strobe_main.kicad_sch)

Type | Description | Details
lib_symbol_issues | The current configuration does not include the symbol library 'personal' | @(0.4826 mm, 0.9144 mm): Symbol P1 [Cosmetic_PWR]
lib_symbol_issues | The current configuration does not include the symbol library 'personal' | @(0.4826 mm, 0.9906 mm): Symbol P10 [Cosmetic_PWR_SRC]
lib_symbol_issues | The current configuration does not include the symbol library 'personal' | @(0.4826 mm, 1.1049 mm): Symbol P15 [Cosmetic_GND2]
lib_symbol_issues | The current configuration does not include the symbol library 'personal' | @(0.9144 mm, 0.9144 mm): Symbol P2 [Cosmetic_PWR_SRC]
lib_symbol_issues | The current configuration does not include the symbol library 'personal' | @(0.9144 mm, 0.9906 mm): Symbol P11 [Cosmetic_PWR_SRC]
lib_symbol_issues | The current configuration does not include the symbol library 'personal' | @(0.9144 mm, 1.1049 mm): Symbol P16 [Cosmetic_GND]
lib_symbol_issues | The current configuration does not include the symbol library 'personal' | @(1.1176 mm, 0.9144 mm): Symbol P4 [Cosmetic_PWR]
lib_symbol_issues | The current configuration does not include the symbol library 'personal' | @(1.1176 mm, 0.9906 mm): Symbol P12 [Cosmetic_PWR]
lib_symbol_issues | The current configuration does not include the symbol library 'personal' | @(1.1176 mm, 1.2573 mm): Symbol P18 [Cosmetic_GND]
lib_symbol_issues | The current configuration does not include the symbol library 'personal' | @(1.6256 mm, 1.0668 mm): Symbol P14 [Cosmetic_PWR]
lib_symbol_issues | The current configuration does not include the symbol library 'personal' | @(1.6256 mm, 1.2573 mm): Symbol P19 [Cosmetic_GND]
lib_symbol_issues | The current configuration does not include the symbol library 'personal' | @(1.3589 mm, 1.8796 mm): Symbol P28 [Cosmetic_GND]
lib_symbol_issues | The current configuration does not include the symbol library 'personal' | @(2.1336 mm, 0.9144 mm): Symbol P5 [Cosmetic_PWR]
lib_symbol_issues | The current configuration does not include the symbol library 'personal' | @(1.6891 mm, 1.6637 mm): Symbol P23 [Cosmetic_IN]
lib_symbol_issues | The current configuration does not include the symbol library 'personal' | @(1.7272 mm, 1.778 mm): Symbol P25 [Cosmetic_PWR_SRC]
lib_symbol_issues | The current configuration does not include the symbol library 'personal' | @(1.7272 mm, 1.8796 mm): Symbol P29 [Cosmetic_GND]
lib_symbol_issues | The current configuration does not include the symbol library 'personal' | @(1.8796 mm, 1.8796 mm): Symbol P31 [Cosmetic_PWR_SRC]
lib_symbol_issues | The current configuration does not include the symbol library 'personal' | @(2.6416 mm, 0.9144 mm): Symbol P6 [Cosmetic_PWR]
lib_symbol_issues | The current configuration does not include the symbol library 'personal' | @(2.1336 mm, 1.905 mm): Symbol P30 [Cosmetic_GND]
lib_symbol_issues | The current configuration does not include the symbol library 'personal' | @(2.6416 mm, 1.5875 mm): Symbol P21 [Cosmetic_GND]
lib_symbol_issues | The current configuration does not include the symbol library 'personal' | @(3.0734 mm, 0.9144 mm): Symbol P7 [Cosmetic_PWR]
lib_symbol_issues | The current configuration does not include the symbol library 'personal' | @(3.2766 mm, 0.9652 mm): Symbol P9 [Cosmetic_OUT]
lib_symbol_issues | The current configuration does not include the symbol library 'personal' | @(3.0734 mm, 1.5875 mm): Symbol P22 [Cosmetic_GND2]
lib_symbol_issues | The current configuration does not include the symbol library 'personal' | @(3.3401 mm, 1.2192 mm): Symbol P17 [Cosmetic_PWR]
lib_symbol_issues | The current configuration does not include the symbol library 'personal' | @(3.4544 mm, 0.9271 mm): Symbol P8 [Cosmetic_PWR]
lib_symbol_issues | The current configuration does not include the symbol library 'personal' | @(3.4544 mm, 1.016 mm): Symbol P13 [Cosmetic_GND2]
lib_symbol_issues | The current configuration does not include the symbol library 'personal' | @(3.3401 mm, 1.5367 mm): Symbol P20 [Cosmetic_GND2]
lib_symbol_issues | The current configuration does not include the symbol library 'personal' | @(3.2512 mm, 1.778 mm): Symbol P26 [Cosmetic_OUT]
lib_symbol_issues | The current configuration does not include the symbol library 'personal' | @(3.4544 mm, 1.7399 mm): Symbol P24 [Cosmetic_PWR]
lib_symbol_issues | The current configuration does not include the symbol library 'personal' | @(3.4544 mm, 1.8288 mm): Symbol P27 [Cosmetic_GND]
lib_symbol_issues | The current configuration does not include the symbol library 'personal' | @(0.3302 mm, 0.2413 mm): Symbol P32 [Cosmetic_PWR_SRC]
lib_symbol_issues | The current configuration does not include the symbol library 'personal' | @(0.3302 mm, 0.3175 mm): Symbol P33 [Cosmetic_PWR]
lib_symbol_issues | The current configuration does not include the symbol library 'personal' | @(0.3302 mm, 0.3937 mm): Symbol P37 [Cosmetic_PWR]
lib_symbol_issues | The current configuration does not include the symbol library 'personal' | @(0.3302 mm, 0.4572 mm): Symbol P38 [Cosmetic_GND]
lib_symbol_issues | The current configuration does not include the symbol library 'personal' | @(0.3302 mm, 0.5461 mm): Symbol P39 [Cosmetic_PWR]
lib_symbol_issues | The current configuration does not include the symbol library 'personal' | @(0.3302 mm, 0.6096 mm): Symbol P47 [Cosmetic_GND2]
lib_symbol_issues | The current configuration does not include the symbol library 'personal' | @(1.016 mm, 0.3683 mm): Symbol P34 [Cosmetic_PWR]
lib_symbol_issues | The current configuration does not include the symbol library 'personal' | @(1.0414 mm, 0.5969 mm): Symbol P40 [Cosmetic_GND]
lib_symbol_issues | The current configuration does not include the symbol library 'personal' | @(1.016 mm, 0.7493 mm): Symbol P48 [Cosmetic_PWR]
lib_symbol_issues | The current configuration does not include the symbol library 'personal' | @(1.1684 mm, 0.5969 mm): Symbol P41 [Cosmetic_GND]
lib_symbol_issues | The current configuration does not include the symbol library 'personal' | @(1.2827 mm, 0.4064 mm): Symbol PS10 [B0524S-2W]
lib_symbol_issues | The current configuration does not include the symbol library 'personal' | @(1.0414 mm, 0.889 mm): Symbol P50 [Cosmetic_GND]
lib_symbol_issues | The current configuration does not include the symbol library 'personal' | @(1.1938 mm, 0.889 mm): Symbol P51 [Cosmetic_GND]
lib_symbol_issues | The current configuration does not include the symbol library 'personal' | @(1.016 mm, 1.1303 mm): Symbol P53 [Cosmetic_PWR]
lib_symbol_issues | The current configuration does not include the symbol library 'personal' | @(1.4097 mm, 0.5969 mm): Symbol P42 [Cosmetic_GND]
lib_symbol_issues | The current configuration does not include the symbol library 'personal' | @(1.4986 mm, 0.3683 mm): Symbol P35 [Cosmetic_PWR_SRC]
lib_symbol_issues | The current configuration does not include the symbol library 'personal' | @(1.3589 mm, 0.7493 mm): Symbol P49 [Cosmetic_PWR_SRC]
lib_symbol_issues | The current configuration does not include the symbol library 'personal' | @(1.3081 mm, 0.889 mm): Symbol P52 [Cosmetic_GND]
lib_symbol_issues | The current configuration does not include the symbol library 'personal' | @(1.524 mm, 0.5969 mm): Symbol P43 [Cosmetic_GND]
lib_symbol_issues | The current configuration does not include the symbol library 'personal' | @(1.0414 mm, 1.27 mm): Symbol P56 [Cosmetic_GND]
lib_symbol_issues | The current configuration does not include the symbol library 'personal' | @(1.1684 mm, 1.27 mm): Symbol P57 [Cosmetic_GND]
lib_symbol_issues | The current configuration does not include the symbol library 'personal' | @(1.2827 mm, 1.1684 mm): Symbol PS11 [B0505S-2W]
lib_symbol_issues | The current configuration does not include the symbol library 'personal' | @(1.6637 mm, 0.5969 mm): Symbol P44 [Cosmetic_GND]
lib_symbol_issues | The current configuration does not include the symbol library 'personal' | @(1.4986 mm, 1.1303 mm): Symbol P54 [Cosmetic_PWR_SRC]
lib_symbol_issues | The current configuration does not include the symbol library 'personal' | @(1.4097 mm, 1.27 mm): Symbol P58 [Cosmetic_GND2]
lib_symbol_issues | The current configuration does not include the symbol library 'personal' | @(1.524 mm, 1.27 mm): Symbol P59 [Cosmetic_GND2]
lib_symbol_issues | The current configuration does not include the symbol library 'personal' | @(1.8923 mm, 0.5969 mm): Symbol P45 [Cosmetic_GND]
lib_symbol_issues | The current configuration does not include the symbol library 'personal' | @(2.0574 mm, 0.3683 mm): Symbol P36 [Cosmetic_PWR_SRC]
lib_symbol_issues | The current configuration does not include the symbol library 'personal' | @(2.0066 mm, 0.5969 mm): Symbol P46 [Cosmetic_GND]
lib_symbol_issues | The current configuration does not include the symbol library 'personal' | @(1.6764 mm, 1.27 mm): Symbol P60 [Cosmetic_GND2]
lib_symbol_issues | The current configuration does not include the symbol library 'personal' | @(1.8415 mm, 1.1303 mm): Symbol P55 [Cosmetic_PWR_SRC]
lib_symbol_issues | The current configuration does not include the symbol library 'personal' | @(1.7907 mm, 1.27 mm): Symbol P61 [Cosmetic_GND2]
lib_symbol_issues | The current configuration does not include the symbol library 'personal' | @(0.3302 mm, 0.2413 mm): Symbol P62 [Cosmetic_PWR_SRC]
lib_symbol_issues | The current configuration does not include the symbol library 'personal' | @(0.3302 mm, 0.3175 mm): Symbol P66 [Cosmetic_PWR_SRC]
lib_symbol_issues | The current configuration does not include the symbol library 'personal' | @(0.3302 mm, 0.4826 mm): Symbol P73 [Cosmetic_GND]
lib_symbol_issues | The current configuration does not include the symbol library 'personal' | @(0.4826 mm, 0.3556 mm): Symbol P67 [Cosmetic_OUT]
lib_symbol_issues | The current configuration does not include the symbol library 'personal' | @(0.4826 mm, 0.381 mm): Symbol P68 [Cosmetic_IN]
lib_symbol_issues | The current configuration does not include the symbol library 'personal' | @(0.4826 mm, 0.4064 mm): Symbol P69 [Cosmetic_IN]
lib_symbol_issues | The current configuration does not include the symbol library 'personal' | @(0.4826 mm, 0.4318 mm): Symbol P71 [Cosmetic_IN]
lib_symbol_issues | The current configuration does not include the symbol library 'personal' | @(0.7874 mm, 0.2667 mm): Symbol P64 [Cosmetic_PWR]
lib_symbol_issues | The current configuration does not include the symbol library 'personal' | @(0.8382 mm, 0.4699 mm): Symbol P72 [Cosmetic_IN]
lib_symbol_issues | The current configuration does not include the symbol library 'personal' | @(0.7874 mm, 0.635 mm): Symbol P75 [Cosmetic_GND]
lib_symbol_issues | The current configuration does not include the symbol library 'personal' | @(0.9652 mm, 0.5461 mm): Symbol TP21 [OscTestpoint]
lib_symbol_issues | The current configuration does not include the symbol library 'personal' | @(0.9652 mm, 0.635 mm): Symbol P76 [Cosmetic_GND]
lib_symbol_issues | The current configuration does not include the symbol library 'personal' | @(1.1176 mm, 0.635 mm): Symbol P77 [Cosmetic_GND]
lib_symbol_issues | The current configuration does not include the symbol library 'personal' | @(0.889 mm, 1.0414 mm): Symbol P88 [Cosmetic_PWR]
lib_symbol_issues | The current configuration does not include the symbol library 'personal' | @(1.2827 mm, 0.635 mm): Symbol P78 [Cosmetic_GND]
lib_symbol_issues | The current configuration does not include the symbol library 'personal' | @(1.4859 mm, 0.4699 mm): Symbol TP20 [OscTestpoint]
lib_symbol_issues | The current configuration does not include the symbol library 'personal' | @(1.4859 mm, 0.635 mm): Symbol P79 [Cosmetic_GND]
lib_symbol_issues | The current configuration does not include the symbol library 'personal' | @(0.2286 mm, 1.6383 mm): Symbol P93 [Cosmetic_IN]
lib_symbol_issues | The current configuration does not include the symbol library 'personal' | @(1.6002 mm, 0.5207 mm): Symbol P74 [Cosmetic_OUT]
lib_symbol_issues | The current configuration does not include the symbol library 'personal' | @(0.889 mm, 1.4478 mm): Symbol P91 [Cosmetic_GND]
lib_symbol_issues | The current configuration does not include the symbol library 'personal' | @(1.143 mm, 1.3589 mm): Symbol P90 [Cosmetic_IN]
lib_symbol_issues | The current configuration does not include the symbol library 'personal' | @(0.2286 mm, 1.9177 mm): Symbol P96 [Cosmetic_IN]
lib_symbol_issues | The current configuration does not include the symbol library 'personal' | @(2.0701 mm, 0.2667 mm): Symbol P65 [Cosmetic_IN]
lib_symbol_issues | The current configuration does not include the symbol library 'personal' | @(1.6637 mm, 1.651 mm): Symbol P94 [Cosmetic_OUT]
lib_symbol_issues | The current configuration does not include the symbol library 'personal' | @(1.016 mm, 2.1209 mm): Symbol P99 [Cosmetic_GND]
lib_symbol_issues | The current configuration does not include the symbol library 'personal' | @(1.9431 mm, 1.3335 mm): Symbol P89 [Cosmetic_PWR]
lib_symbol_issues | The current configuration does not include the symbol library 'personal' | @(2.159 mm, 0.9652 mm): Symbol P82 [Cosmetic_GND]
lib_symbol_issues | The current configuration does not include the symbol library 'personal' | @(1.2065 mm, 2.1209 mm): Symbol P100 [Cosmetic_GND]
lib_symbol_issues | The current configuration does not include the symbol library 'personal' | @(1.3843 mm, 2.0447 mm): Symbol TP28 [OscTestpoint]
lib_symbol_issues | The current configuration does not include the symbol library 'personal' | @(2.286 mm, 0.9652 mm): Symbol P83 [Cosmetic_GND]
lib_symbol_issues | The current configuration does not include the symbol library 'personal' | @(1.3843 mm, 2.1209 mm): Symbol P101 [Cosmetic_GND]
lib_symbol_issues | The current configuration does not include the symbol library 'personal' | @(2.413 mm, 0.8763 mm): Symbol TP22 [OscTestpoint]
lib_symbol_issues | The current configuration does not include the symbol library 'personal' | @(1.6637 mm, 1.9685 mm): Symbol P97 [Cosmetic_OUT]
lib_symbol_issues | The current configuration does not include the symbol library 'personal' | @(2.413 mm, 0.9652 mm): Symbol P84 [Cosmetic_GND]
lib_symbol_issues | The current configuration does not include the symbol library 'personal' | @(2.4892 mm, 0.7493 mm): Symbol P80 [Cosmetic_OUT]
lib_symbol_issues | The current configuration does not include the symbol library 'personal' | @(1.5494 mm, 2.1209 mm): Symbol P102 [Cosmetic_GND]
lib_symbol_issues | The current configuration does not include the symbol library 'personal' | @(2.794 mm, 0.254 mm): Symbol P63 [Cosmetic_PWR]
lib_symbol_issues | The current configuration does not include the symbol library 'personal' | @(1.9431 mm, 2.1717 mm): Symbol P103 [Cosmetic_GND]
lib_symbol_issues | The current configuration does not include the symbol library 'personal' | @(2.794 mm, 0.9652 mm): Symbol P85 [Cosmetic_GND]
lib_symbol_issues | The current configuration does not include the symbol library 'personal' | @(2.6416 mm, 1.5367 mm): Symbol P92 [Cosmetic_PWR]
lib_symbol_issues | The current configuration does not include the symbol library 'personal' | @(2.1717 mm, 2.1717 mm): Symbol P104 [Cosmetic_GND]
lib_symbol_issues | The current configuration does not include the symbol library 'personal' | @(2.921 mm, 0.9652 mm): Symbol P86 [Cosmetic_GND]
lib_symbol_issues | The current configuration does not include the symbol library 'personal' | @(3.048 mm, 0.8763 mm): Symbol TP23 [OscTestpoint]
lib_symbol_issues | The current configuration does not include the symbol library 'personal' | @(3.048 mm, 0.9652 mm): Symbol P87 [Cosmetic_GND]
lib_symbol_issues | The current configuration does not include the symbol library 'personal' | @(3.1369 mm, 0.7493 mm): Symbol P81 [Cosmetic_OUT]
lib_symbol_issues | The current configuration does not include the symbol library 'personal' | @(2.6416 mm, 2.1717 mm): Symbol P105 [Cosmetic_GND]
lib_symbol_issues | The current configuration does not include the symbol library 'personal' | @(2.7432 mm, 2.0574 mm): Symbol P98 [Cosmetic_IN]
lib_symbol_issues | The current configuration does not include the symbol library 'personal' | @(3.2512 mm, 1.8669 mm): Symbol PT20 [ZS1052-S_HT]
lib_symbol_issues | The current configuration does not include the symbol library 'personal' | @(3.0607 mm, 2.1717 mm): Symbol P106 [Cosmetic_GND]
lib_symbol_issues | The current configuration does not include the symbol library 'personal' | @(3.429 mm, 1.8288 mm): Symbol P95 [Cosmetic_OUT]
lib_symbol_issues | The current configuration does not include the symbol library 'personal' | @(3.2512 mm, 2.1717 mm): Symbol P107 [Cosmetic_GND]
lib_symbol_issues | The current configuration does not include the symbol library 'personal' | @(0.3302 mm, 0.2413 mm): Symbol P109 [Cosmetic_PWR_SRC]
lib_symbol_issues | The current configuration does not include the symbol library 'personal' | @(0.4826 mm, 0.2794 mm): Symbol P112 [Cosmetic_OUT]
lib_symbol_issues | The current configuration does not include the symbol library 'personal' | @(0.3302 mm, 0.4572 mm): Symbol P122 [Cosmetic_GND]
lib_symbol_issues | The current configuration does not include the symbol library 'personal' | @(0.4826 mm, 0.3048 mm): Symbol P113 [Cosmetic_OUT]
lib_symbol_issues | The current configuration does not include the symbol library 'personal' | @(0.4826 mm, 0.3302 mm): Symbol P114 [Cosmetic_OUT]
lib_symbol_issues | The current configuration does not include the symbol library 'personal' | @(0.4826 mm, 0.3556 mm): Symbol P117 [Cosmetic_IN]
lib_symbol_issues | The current configuration does not include the symbol library 'personal' | @(0.4826 mm, 0.381 mm): Symbol P120 [Cosmetic_IN]
lib_symbol_issues | The current configuration does not include the symbol library 'personal' | @(0.4826 mm, 0.4064 mm): Symbol P121 [Cosmetic_IN]
lib_symbol_issues | The current configuration does not include the symbol library 'personal' | @(0.6477 mm, 0.3429 mm): Symbol P115 [Cosmetic_IN]
lib_symbol_issues | The current configuration does not include the symbol library 'personal' | @(0.7874 mm, 0.254 mm): Symbol P110 [Cosmetic_PWR]
lib_symbol_issues | The current configuration does not include the symbol library 'personal' | @(0.7874 mm, 0.4572 mm): Symbol P123 [Cosmetic_GND]
lib_symbol_issues | The current configuration does not include the symbol library 'personal' | @(0.7874 mm, 0.5715 mm): Symbol P125 [Cosmetic_PWR]
lib_symbol_issues | The current configuration does not include the symbol library 'personal' | @(0.7874 mm, 0.7874 mm): Symbol P129 [Cosmetic_GND]
lib_symbol_issues | The current configuration does not include the symbol library 'personal' | @(1.1811 mm, 0.3683 mm): Symbol P118 [Cosmetic_OUT]
lib_symbol_issues | The current configuration does not include the symbol library 'personal' | @(1.3081 mm, 0.3429 mm): Symbol P116 [Cosmetic_IN]
lib_symbol_issues | The current configuration does not include the symbol library 'personal' | @(1.2192 mm, 0.6731 mm): Symbol P127 [Cosmetic_IN]
lib_symbol_issues | The current configuration does not include the symbol library 'personal' | @(1.4478 mm, 0.254 mm): Symbol P111 [Cosmetic_PWR]
lib_symbol_issues | The current configuration does not include the symbol library 'personal' | @(1.4478 mm, 0.4572 mm): Symbol P124 [Cosmetic_GND]
lib_symbol_issues | The current configuration does not include the symbol library 'personal' | @(1.4097 mm, 0.7874 mm): Symbol P130 [Cosmetic_GND]
lib_symbol_issues | The current configuration does not include the symbol library 'personal' | @(1.5113 mm, 0.7874 mm): Symbol P137 [Cosmetic_GND]
lib_symbol_issues | The current configuration does not include the symbol library 'personal' | @(1.6256 mm, 0.5842 mm): Symbol P126 [Cosmetic_PWR]
lib_symbol_issues | The current configuration does not include the symbol library 'personal' | @(1.6256 mm, 0.7874 mm): Symbol P138 [Cosmetic_GND]
lib_symbol_issues | The current configuration does not include the symbol library 'personal' | @(1.8415 mm, 0.3683 mm): Symbol P119 [Cosmetic_OUT]
lib_symbol_issues | The current configuration does not include the symbol library 'personal' | @(1.8288 mm, 0.6731 mm): Symbol P128 [Cosmetic_OUT]
lib_symbol_issues | The current configuration does not include the symbol library 'personal' | @(0.3556 mm, 0.2413 mm): Symbol P108 [Cosmetic_PWR_SRC]
lib_symbol_issues | The current configuration does not include the symbol library 'personal' | @(0.508 mm, 0.2794 mm): Symbol P133 [Cosmetic_OUT]
lib_symbol_issues | The current configuration does not include the symbol library 'personal' | @(0.508 mm, 0.3048 mm): Symbol P134 [Cosmetic_IN]
lib_symbol_issues | The current configuration does not include the symbol library 'personal' | @(0.508 mm, 0.3302 mm): Symbol P136 [Cosmetic_OUT]
lib_symbol_issues | The current configuration does not include the symbol library 'personal' | @(0.508 mm, 0.3556 mm): Symbol P139 [Cosmetic_IO]
lib_symbol_issues | The current configuration does not include the symbol library 'personal' | @(0.508 mm, 0.381 mm): Symbol P140 [Cosmetic_OUT]
lib_symbol_issues | The current configuration does not include the symbol library 'personal' | @(0.508 mm, 0.4064 mm): Symbol P141 [Cosmetic_OUT]
lib_symbol_issues | The current configuration does not include the symbol library 'personal' | @(0.508 mm, 0.4318 mm): Symbol P142 [Cosmetic_OUT]
lib_symbol_issues | The current configuration does not include the symbol library 'personal' | @(0.508 mm, 0.4572 mm): Symbol P143 [Cosmetic_OUT]
lib_symbol_issues | The current configuration does not include the symbol library 'personal' | @(0.508 mm, 0.4826 mm): Symbol P144 [Cosmetic_OUT]
lib_symbol_issues | The current configuration does not include the symbol library 'personal' | @(0.508 mm, 0.508 mm): Symbol P145 [Cosmetic_IN]
lib_symbol_issues | The current configuration does not include the symbol library 'personal' | @(0.6731 mm, 0.2667 mm): Symbol P131 [Cosmetic_IN]
lib_symbol_issues | The current configuration does not include the symbol library 'personal' | @(0.508 mm, 0.5334 mm): Symbol P146 [Cosmetic_OUT]
lib_symbol_issues | The current configuration does not include the symbol library 'personal' | @(0.6731 mm, 0.3048 mm): Symbol P135 [Cosmetic_IN]
lib_symbol_issues | The current configuration does not include the symbol library 'personal' | @(0.3556 mm, 0.6604 mm): Symbol P151 [Cosmetic_GND]
lib_symbol_issues | The current configuration does not include the symbol library 'personal' | @(0.508 mm, 0.5588 mm): Symbol P147 [Cosmetic_IN]
lib_symbol_issues | The current configuration does not include the symbol library 'personal' | @(0.508 mm, 0.5842 mm): Symbol P148 [Cosmetic_OUT]
lib_symbol_issues | The current configuration does not include the symbol library 'personal' | @(0.508 mm, 0.6096 mm): Symbol P149 [Cosmetic_IN]
lib_symbol_issues | The current configuration does not include the symbol library 'personal' | @(0.6985 mm, 0.6223 mm): Symbol P150 [Cosmetic_PWR]
lib_symbol_issues | The current configuration does not include the symbol library 'personal' | @(0.7239 mm, 0.7493 mm): Symbol P152 [Cosmetic_GND]
lib_symbol_issues | The current configuration does not include the symbol library 'personal' | @(0.8509 mm, 0.7493 mm): Symbol P153 [Cosmetic_GND]
lib_symbol_issues | The current configuration does not include the symbol library 'personal' | @(1.1049 mm, 0.2667 mm): Symbol P132 [Cosmetic_OUT]
lib_symbol_issues | The current configuration does not include the symbol library 'personal' | @(0.9779 mm, 0.7493 mm): Symbol P154 [Cosmetic_GND]
lib_symbol_issues | The current configuration does not include the symbol library 'personal' | @(0.9398 mm, 0.8255 mm): Symbol P156 [Cosmetic_IN]
lib_symbol_issues | The current configuration does not include the symbol library 'personal' | @(1.1049 mm, 0.7493 mm): Symbol P155 [Cosmetic_GND]
lib_symbol_issues | The current configuration does not include the symbol library 'personal' | @(0.6731 mm, 1.2319 mm): Symbol P169 [Cosmetic_GND]
lib_symbol_issues | The current configuration does not include the symbol library 'personal' | @(1.1049 mm, 0.9398 mm): Symbol P157 [Cosmetic_GND]
lib_symbol_issues | The current configuration does not include the symbol library 'personal' | @(0.7874 mm, 1.2319 mm): Symbol P170 [Cosmetic_GND]
lib_symbol_issues | The current configuration does not include the symbol library 'personal' | @(0.9017 mm, 1.2319 mm): Symbol P171 [Cosmetic_GND]
lib_symbol_issues | The current configuration does not include the symbol library 'personal' | @(1.0541 mm, 1.1938 mm): Symbol P165 [Cosmetic_OUT]
lib_symbol_issues | The current configuration does not include the symbol library 'personal' | @(1.0541 mm, 1.2192 mm): Symbol P167 [Cosmetic_IN]
lib_symbol_issues | The current configuration does not include the symbol library 'personal' | @(1.1938 mm, 1.3716 mm): Symbol P177 [Cosmetic_GND]
lib_symbol_issues | The current configuration does not include the symbol library 'personal' | @(1.4097 mm, 1.4732 mm): Symbol P179 [Cosmetic_GND]
lib_symbol_issues | The current configuration does not include the symbol library 'personal' | @(1.8415 mm, 1.016 mm): Symbol P158 [Cosmetic_IN]
lib_symbol_issues | The current configuration does not include the symbol library 'personal' | @(1.8415 mm, 1.0414 mm): Symbol P159 [Cosmetic_IN]
lib_symbol_issues | The current configuration does not include the symbol library 'personal' | @(1.8415 mm, 1.0668 mm): Symbol P160 [Cosmetic_IN]
lib_symbol_issues | The current configuration does not include the symbol library 'personal' | @(1.8415 mm, 1.0922 mm): Symbol P162 [Cosmetic_IN]
lib_symbol_issues | The current configuration does not include the symbol library 'personal' | @(1.8415 mm, 1.1176 mm): Symbol P163 [Cosmetic_IN]
lib_symbol_issues | The current configuration does not include the symbol library 'personal' | @(1.8415 mm, 1.1684 mm): Symbol P164 [Cosmetic_OUT]
lib_symbol_issues | The current configuration does not include the symbol library 'personal' | @(1.6129 mm, 1.4732 mm): Symbol P180 [Cosmetic_GND]
lib_symbol_issues | The current configuration does not include the symbol library 'personal' | @(1.8415 mm, 1.1938 mm): Symbol P166 [Cosmetic_OUT]
lib_symbol_issues | The current configuration does not include the symbol library 'personal' | @(1.8415 mm, 1.2192 mm): Symbol P168 [Cosmetic_IN]
lib_symbol_issues | The current configuration does not include the symbol library 'personal' | @(1.8415 mm, 1.2446 mm): Symbol P172 [Cosmetic_OUT]
lib_symbol_issues | The current configuration does not include the symbol library 'personal' | @(1.8415 mm, 1.27 mm): Symbol P173 [Cosmetic_IN]
lib_symbol_issues | The current configuration does not include the symbol library 'personal' | @(1.7018 mm, 1.4732 mm): Symbol P181 [Cosmetic_GND]
lib_symbol_issues | The current configuration does not include the symbol library 'personal' | @(1.8415 mm, 1.2954 mm): Symbol P174 [Cosmetic_IO]
lib_symbol_issues | The current configuration does not include the symbol library 'personal' | @(1.8415 mm, 1.3208 mm): Symbol P176 [Cosmetic_IN]
lib_symbol_issues | The current configuration does not include the symbol library 'personal' | @(1.7907 mm, 1.4732 mm): Symbol P182 [Cosmetic_GND]
lib_symbol_issues | The current configuration does not include the symbol library 'personal' | @(2.0828 mm, 1.3081 mm): Symbol P175 [Cosmetic_IN]
lib_symbol_issues | The current configuration does not include the symbol library 'personal' | @(2.2225 mm, 1.0668 mm): Symbol P161 [Cosmetic_PWR]
lib_symbol_issues | The current configuration does not include the symbol library 'personal' | @(2.2225 mm, 1.4224 mm): Symbol P178 [Cosmetic_GND]
lib_symbol_issues | The current configuration does not include the symbol library 'personal' | @(0.3556 mm, 0.2413 mm): Symbol P183 [Cosmetic_PWR_SRC]
lib_symbol_issues | The current configuration does not include the symbol library 'personal' | @(0.3556 mm, 0.3175 mm): Symbol P186 [Cosmetic_PWR_SRC]
lib_symbol_issues | The current configuration does not include the symbol library 'personal' | @(0.508 mm, 0.3556 mm): Symbol P187 [Cosmetic_IO]
lib_symbol_issues | The current configuration does not include the symbol library 'personal' | @(0.508 mm, 0.381 mm): Symbol P194 [Cosmetic_IN]
lib_symbol_issues | The current configuration does not include the symbol library 'personal' | @(0.508 mm, 0.4064 mm): Symbol P195 [Cosmetic_IN]
lib_symbol_issues | The current configuration does not include the symbol library 'personal' | @(0.508 mm, 0.4318 mm): Symbol P198 [Cosmetic_OUT]
lib_symbol_issues | The current configuration does not include the symbol library 'personal' | @(0.508 mm, 0.4572 mm): Symbol P199 [Cosmetic_IN]
lib_symbol_issues | The current configuration does not include the symbol library 'personal' | @(0.508 mm, 0.4826 mm): Symbol P200 [Cosmetic_OUT]
lib_symbol_issues | The current configuration does not include the symbol library 'personal' | @(0.508 mm, 0.508 mm): Symbol P203 [Cosmetic_IO]
lib_symbol_issues | The current configuration does not include the symbol library 'personal' | @(0.6731 mm, 0.2921 mm): Symbol P184 [Cosmetic_PWR]
lib_symbol_issues | The current configuration does not include the symbol library 'personal' | @(0.508 mm, 0.5334 mm): Symbol P206 [Cosmetic_OUT]
lib_symbol_issues | The current configuration does not include the symbol library 'personal' | @(0.508 mm, 0.5588 mm): Symbol P207 [Cosmetic_OUT]
lib_symbol_issues | The current configuration does not include the symbol library 'personal' | @(0.3556 mm, 0.6858 mm): Symbol P213 [Cosmetic_GND2]
lib_symbol_issues | The current configuration does not include the symbol library 'personal' | @(0.508 mm, 0.5842 mm): Symbol P210 [Cosmetic_IN]
lib_symbol_issues | The current configuration does not include the symbol library 'personal' | @(0.6731 mm, 0.4064 mm): Symbol P196 [Cosmetic_GND]
lib_symbol_issues | The current configuration does not include the symbol library 'personal' | @(0.508 mm, 0.6096 mm): Symbol P211 [Cosmetic_OUT]
lib_symbol_issues | The current configuration does not include the symbol library 'personal' | @(0.6477 mm, 0.4826 mm): Symbol P201 [Cosmetic_IO]
lib_symbol_issues | The current configuration does not include the symbol library 'personal' | @(0.508 mm, 0.635 mm): Symbol P212 [Cosmetic_IN]
lib_symbol_issues | The current configuration does not include the symbol library 'personal' | @(0.6477 mm, 0.508 mm): Symbol P204 [Cosmetic_OUT]
lib_symbol_issues | The current configuration does not include the symbol library 'personal' | @(0.3556 mm, 0.762 mm): Symbol P214 [Cosmetic_GND]
lib_symbol_issues | The current configuration does not include the symbol library 'personal' | @(0.9398 mm, 0.3556 mm): Symbol P188 [Cosmetic_PWR]
lib_symbol_issues | The current configuration does not include the symbol library 'personal' | @(0.6731 mm, 0.8255 mm): Symbol P215 [Cosmetic_PWR]
lib_symbol_issues | The current configuration does not include the symbol library 'personal' | @(1.0414 mm, 0.3556 mm): Symbol P189 [Cosmetic_PWR]
lib_symbol_issues | The current configuration does not include the symbol library 'personal' | @(0.6731 mm, 0.9398 mm): Symbol P221 [Cosmetic_GND]
lib_symbol_issues | The current configuration does not include the symbol library 'personal' | @(1.1176 mm, 0.3556 mm): Symbol P190 [Cosmetic_PWR]
lib_symbol_issues | The current configuration does not include the symbol library 'personal' | @(0.6477 mm, 1.0287 mm): Symbol P223 [Cosmetic_OUT]
lib_symbol_issues | The current configuration does not include the symbol library 'personal' | @(0.6477 mm, 1.0541 mm): Symbol P225 [Cosmetic_OUT]
lib_symbol_issues | The current configuration does not include the symbol library 'personal' | @(1.1176 mm, 0.5588 mm): Symbol P208 [Cosmetic_GND]
lib_symbol_issues | The current configuration does not include the symbol library 'personal' | @(0.6477 mm, 1.0795 mm): Symbol P227 [Cosmetic_OUT]
lib_symbol_issues | The current configuration does not include the symbol library 'personal' | @(0.6477 mm, 1.1049 mm): Symbol P229 [Cosmetic_IN]
lib_symbol_issues | The current configuration does not include the symbol library 'personal' | @(1.3462 mm, 0.3556 mm): Symbol P191 [Cosmetic_PWR]
lib_symbol_issues | The current configuration does not include the symbol library 'personal' | @(1.0668 mm, 0.9144 mm): Symbol P217 [Cosmetic_PWR]
lib_symbol_issues | The current configuration does not include the symbol library 'personal' | @(1.4097 mm, 0.3556 mm): Symbol P192 [Cosmetic_PWR]
lib_symbol_issues | The current configuration does not include the symbol library 'personal' | @(1.3462 mm, 0.5588 mm): Symbol P209 [Cosmetic_GND2]
lib_symbol_issues | The current configuration does not include the symbol library 'personal' | @(1.1811 mm, 0.9144 mm): Symbol P218 [Cosmetic_PWR]
lib_symbol_issues | The current configuration does not include the symbol library 'personal' | @(1.5113 mm, 0.3556 mm): Symbol P193 [Cosmetic_PWR]
lib_symbol_issues | The current configuration does not include the symbol library 'personal' | @(1.2827 mm, 0.9144 mm): Symbol P219 [Cosmetic_PWR]
lib_symbol_issues | The current configuration does not include the symbol library 'personal' | @(1.3843 mm, 0.9144 mm): Symbol P220 [Cosmetic_PWR]
lib_symbol_issues | The current configuration does not include the symbol library 'personal' | @(1.1811 mm, 1.2954 mm): Symbol P231 [Cosmetic_GND]
lib_symbol_issues | The current configuration does not include the symbol library 'personal' | @(1.7653 mm, 0.2921 mm): Symbol P185 [Cosmetic_PWR]
lib_symbol_issues | The current configuration does not include the symbol library 'personal' | @(1.7653 mm, 0.4064 mm): Symbol P197 [Cosmetic_GND2]
lib_symbol_issues | The current configuration does not include the symbol library 'personal' | @(1.2827 mm, 1.2954 mm): Symbol P232 [Cosmetic_GND2]
lib_symbol_issues | The current configuration does not include the symbol library 'personal' | @(1.8161 mm, 0.4826 mm): Symbol P202 [Cosmetic_IO]
lib_symbol_issues | The current configuration does not include the symbol library 'personal' | @(1.8161 mm, 0.508 mm): Symbol P205 [Cosmetic_IN]
lib_symbol_issues | The current configuration does not include the symbol library 'personal' | @(1.4478 mm, 1.2954 mm): Symbol P233 [Cosmetic_GND2]
lib_symbol_issues | The current configuration does not include the symbol library 'personal' | @(1.7653 mm, 0.8255 mm): Symbol P216 [Cosmetic_PWR]
lib_symbol_issues | The current configuration does not include the symbol library 'personal' | @(1.7653 mm, 0.9398 mm): Symbol P222 [Cosmetic_GND2]
lib_symbol_issues | The current configuration does not include the symbol library 'personal' | @(1.8161 mm, 1.0287 mm): Symbol P224 [Cosmetic_IN]
lib_symbol_issues | The current configuration does not include the symbol library 'personal' | @(1.8161 mm, 1.0541 mm): Symbol P226 [Cosmetic_IN]
lib_symbol_issues | The current configuration does not include the symbol library 'personal' | @(1.8161 mm, 1.0795 mm): Symbol P228 [Cosmetic_IN]
lib_symbol_issues | The current configuration does not include the symbol library 'personal' | @(1.8161 mm, 1.1049 mm): Symbol P230 [Cosmetic_OUT]

Generated by KiBot (https://github.com/INTI-CMNB/KiBot/) v1.9.2

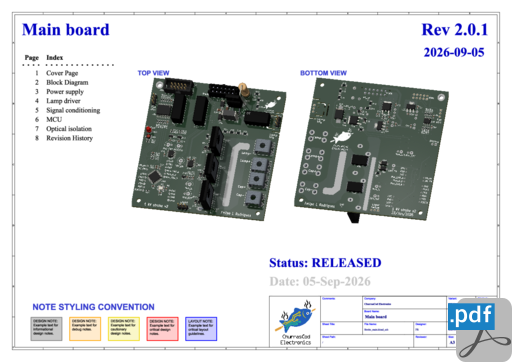
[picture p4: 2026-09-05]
HTML/images/cat_pdf_schematic_Strobe_main-schematic.png

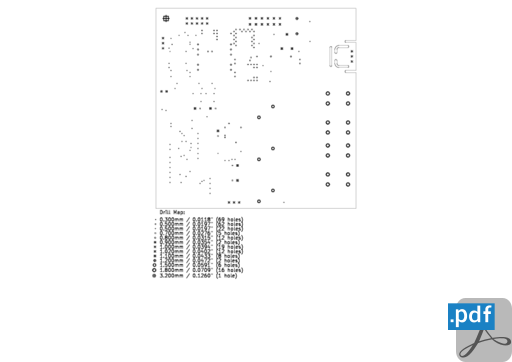
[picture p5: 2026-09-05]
HTML/images/cat_pdf_drill_map_Strobe_main-PTH_drill_map.png

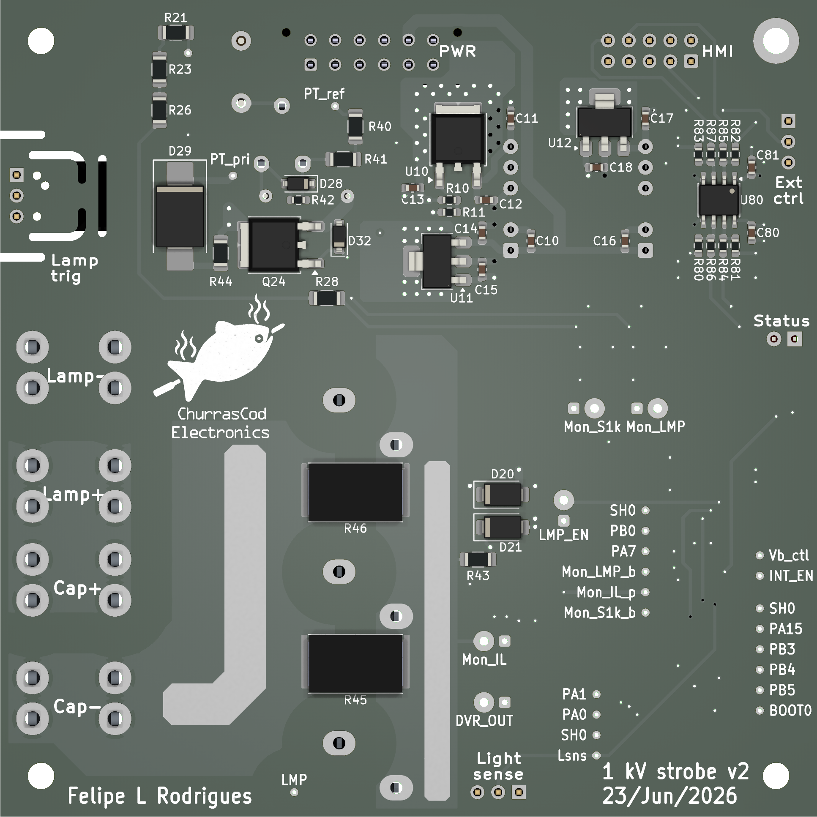
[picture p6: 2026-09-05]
Images/Strobe_main-bottom.png

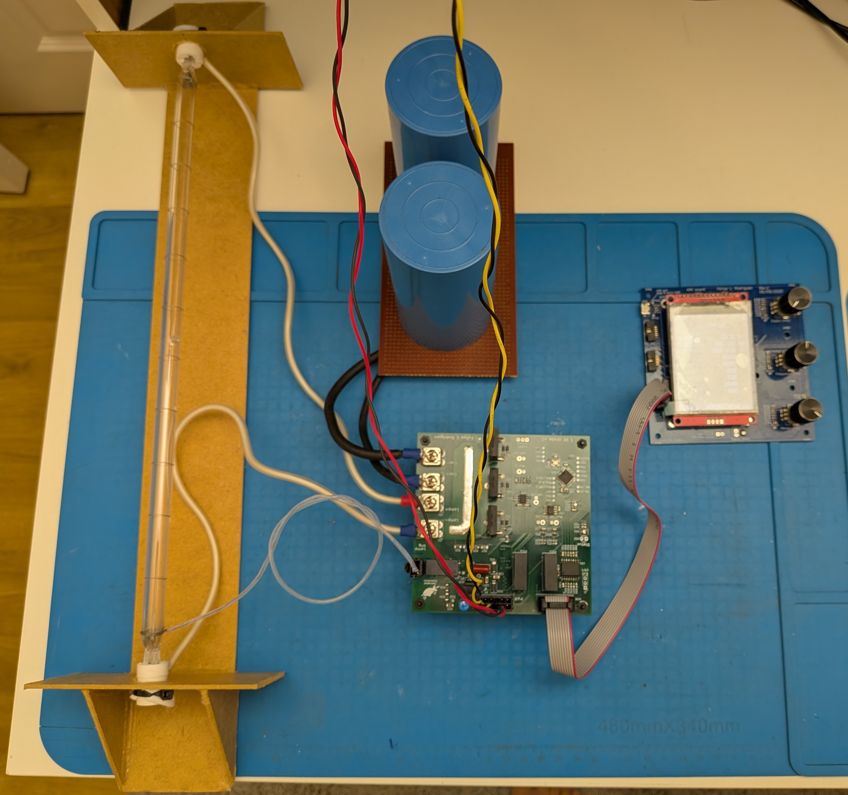
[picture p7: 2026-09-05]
Images/system.jpg

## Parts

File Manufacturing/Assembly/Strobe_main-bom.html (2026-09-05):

 | Bill of Materials
 | Schematic: Strobe_main Variant: RELEASED Revision: 2.0.1 Date: 2025-07-04 KiCad Version: 9.0.7+1 | Component Groups: 49 Component Count: 133 (per PCB) Fitted Components: 130 (per PCB) Number of PCBs: 1 Total Components: 130 (for 1 PCBs)
Row | Quantity Per PCB | References | Value | Datasheet | Footprint | Description | Manufacturer | Manufacturer Part Number | Supplier Part Number
1 | 2 | C65 C66 | 22p | ~ | C_0603_1608Metric_Pad1.08x0.95mm_HandSolder | Unpolarized capacitor | Generic
2 | 2 | C22 C23 | 1n | ~ | C_0603_1608Metric_Pad1.08x0.95mm_HandSolder | Unpolarized capacitor | Generic
3 | 1 | C51 | 4n7 | ~ | C_0603_1608Metric_Pad1.08x0.95mm_HandSolder | Unpolarized capacitor | Generic
4 | 1 | C26 | 47n | ~ | C_Rect_L11.0mm_W4.2mm_P10.00mm_MKT | Unpolarized capacitor | Generic
5 | 17 | C12 C15 C18 C20 C21 C25 C27 C28 C50 C61 C62 C63 C64 C80 C81 C82 C83 | 100n | ~ | C_0603_1608Metric_Pad1.08x0.95mm_HandSolder | Unpolarized capacitor | Generic
6 | 7 | C10 C11 C13 C14 C16 C17 C60 | 1u | ~ | C_0603_1608Metric_Pad1.08x0.95mm_HandSolder | Unpolarized capacitor | Generic
7 | 3 | D22 D23 D24 | 1N4148 | ~ | D_SOD-123 | Diode | DIODES | 1N4148W-7-F
8 | 2 | D30 D31 | 1SMA5953B | https://diotec.com/tl_files/diotec/files/pdf/datasheets/z1sma1.pdf | D_SMA | 1000mW Zener Diode, SMA(DO-214AC) | Jingdao Microelectronics | 1SMA5953B
9 | 5 | D25 D26 D27 D28 D32 | 20 V | ~ | D_SOD-123 | Zener diode | HXY MOSFET | BZT52C20
10 | 2 | D20 D21 | B360 | ~ | D_SMA | Schottky diode | DIODES | B360A-13-F
11 | 3 | D50 D51 D52 | BAV199 | https://assets.nexperia.com/documents/data-sheet/BAV99_SER.pdf | SOT-23 | BAV99 High-speed switching diodes, SOT-23 | onsemi | BAV199LT1G
12 | 2 | D60 D61 | LED | ~ | LED_D3.0mm | Light emitting diode | Generic
13 | 1 | D29 | S15M | ~ | D_SMC_Handsoldering | Diode | LGE | S15M
14 | 9 | J1 J2 J3 J4 J20 J21 J22 J23 J24 | Header | ~ | PinHeader_1x03_P2.54mm_Vertical | Generic connector, single row, 01x03, script generated Generic connector, double row, 02x05, odd/even pin numbering scheme (row 1 odd numbers, row 2 even numbers), script generated (kicad-library-utils/schlib/autogen/connector/) Generic connector, double row, 02x06, top/bottom pin numbering scheme (row 1: 1...pins_per_row, row2: pins_per_row+1 ... num_pins), script generated (kicad-library-utils/schlib/autogen/connector/) Generic screw terminal, single row, 01x01, script generated (kicad-library-utils/schlib/autogen/connector/) | Generic ZHOURI Molex XFCN | DC3-2.54-10PAS 430451227 T44007
15 | 1 | PS11 | B0505S-2W | https://www.lcsc.com/datasheet/C5198437.pdf | DCDC_converter_THT_BxxxxS-2W |  | Evisun | B0505S-2W
16 | 1 | PS10 | B0524S-2W | https://www.lcsc.com/datasheet/C5198437.pdf | DCDC_converter_THT_BxxxxS-2W |  | Evisun | B0524S-2W
17 | 1 | PT20 | ZS1052-S_HT |  | ZS1052-S_HT |  | Excelitas Technologies | ZS1052-S_HT
18 | 3 | Q21 Q22 Q23 | IXYH55N120 | ~ | TO-247_mixed_pads_vert | N-IGBT transistor, gate/collector/emitter | IXYS | IXYH55N120
19 | 1 | Q24 | MDT7N65 |  | TO-252-2 |  | Minos | MDT7N65
20 | 1 | Q20 | MPF3N150 | https://media.digikey.com/pdf/Data%20Sheets/Fairchild%20PDFs/BUZ11.pdf | To-220_staggered_3 | 30A Id, 50V Vds, N-Channel Power MOSFET, TO-220 | Minos | MPF3N150
21 | 13 | R60 R84 R85 R86 R87 R90 R91 R92 R93 R94 R95 R96 R97 | 0R | ~ | R_0603_1608Metric_Pad0.98x0.95mm_HandSolder | Resistor | Generic
22 | 2 | R45 R46 | 20m | ~ | R_Shunt_Vishay_WSR2_WSR3_KelvinConnection | Resistor | Vishay Intertech | WSR3R0200FEA
23 | 1 | R44 | 1R | ~ | R_1206_3216Metric_Pad1.30x1.75mm_HandSolder | Resistor | Generic
24 | 1 | R47 | 10R | ~ | R_1206_3216Metric_Pad1.30x1.75mm_HandSolder | Resistor | Generic
25 | 1 | R43 | 22R | ~ | R_1206_3216Metric_Pad1.30x1.75mm_HandSolder | Resistor | Generic
26 | 3 | R37 R38 R39 | 91R | ~ | R_0603_1608Metric_Pad0.98x0.95mm_HandSolder | Resistor | Generic
27 | 2 | R50 R51 | 220 | ~ | R_0603_1608Metric_Pad0.98x0.95mm_HandSolder | Resistor | Generic
28 | 1 | R10 | 470 | ~ | R_0603_1608Metric_Pad0.98x0.95mm_HandSolder | Resistor | Generic
29 | 1 | R63 | 1k | ~ | R_0603_1608Metric_Pad0.98x0.95mm_HandSolder | Resistor | Generic
30 | 4 | R29 R30 R31 R32 | 3k3 | ~ | R_0603_1608Metric_Pad0.98x0.95mm_HandSolder | Resistor | Generic
31 | 4 | R80 R81 R82 R83 | 4k7 | ~ | R_0603_1608Metric_Pad0.98x0.95mm_HandSolder | Resistor | Generic
32 | 1 | R11 | 6k8 | ~ | R_0603_1608Metric_Pad0.98x0.95mm_HandSolder | Resistor | Generic
33 | 6 | R62 R64 R65 R88 R89 R98 | 10k | ~ | R_0603_1608Metric_Pad0.98x0.95mm_HandSolder | Resistor | Generic
34 | 1 | R24 | 15k | ~ | R_0603_1608Metric_Pad0.98x0.95mm_HandSolder | Resistor | Generic
35 | 2 | R35 R42 | 100k | ~ | R_Axial_DIN0617_L17.0mm_D6.0mm_P7.62mm_Vertical | Resistor | Generic
36 | 2 | R40 R41 | 110k | ~ | R_1206_3216Metric_Pad1.30x1.75mm_HandSolder | Resistor | Generic
37 | 3 | R33 R34 R36 | 330k | ~ | R_1206_3216Metric_Pad1.30x1.75mm_HandSolder | Resistor | Generic
38 | 8 | R20 R21 R22 R23 R25 R26 R27 R28 | 510k | ~ | R_1206_3216Metric_Pad1.30x1.75mm_HandSolder | Resistor | Generic
39 | 1 | U20 | IRS2184 | https://www.infineon.com/dgdl/irs2184.pdf?fileId=5546d462533600a401535676d8da27db | SOIC-8_3.9x4.9mm_P1.27mm | Half-Bridge Driver, 600V, 1.4/1.8A, PDIP-8/SOIC-8 | Infineon | IRS2184
40 | 1 | U80 | ISO1541 | http://www.ti.com/lit/ds/symlink/iso1541.pdf | SOIC-8_3.9x4.9mm_P1.27mm | I2C Isolator, 2.5 kVrms, Unidirectional Clock, Bidirectional data, SOIC-8 | Texas Instruments | ISO1541DR
41 | 1 | U81 | ISO6741 | https://www.ti.com/lit/ds/symlink/iso6741.pdf | SOIC-16W_7.5x10.3mm_P1.27mm | General-purpose, quad-channel, 3/1 digital isolator | Texas Instruments | ISO6741DWR
42 | 1 | U10 | LM217MDT | http://www.ti.com/lit/ds/snvs774n/snvs774n.pdf | TO-252-2 | 1.5A 35V Adjustable Linear Regulator, TO-252 | ST | LM217MDT
43 | 2 | U11 U12 | NCP1117IST33T3G | https://www.lcsc.com/datasheet/C114733.pdf | SOT-223-3_TabPin2 | 1A Low Dropout regulator, positive, 3.3V fixed output, SOT-223 | Onsemi | NCP1117IST33T3G
44 | 1 | U60 | STM32G431K8Tx | https://www.st.com/resource/en/datasheet/stm32g431k8.pdf | LQFP-32_7x7mm_P0.8mm | STMicroelectronics Arm Cortex-M4 MCU, 64KB flash, 32KB RAM, 170 MHz, 1.71-3.6V, 26 GPIO, LQFP32 | STMicroelectronics | STM32G431K8T6
45 | 1 | U50 | TSV912IDT | www.st.com/resource/en/datasheet/tsv911.pdf | SOIC-8_3.9x4.9mm_P1.27mm | Dual rail-to-rail input/output 8 MHz operational amplifiers, SOIC-8 | ST | TSV912IDT
46 | 1 | Y60 | 20 MHz | ~ | Crystal_SMD_3225-4Pin_3.2x2.5mm_HandSoldering | Four pin crystal, GND on pins 2 and 4, small symbol | Generic
Row | Quantity Per PCB | References | Value | Datasheet | Footprint | Description | Manufacturer | Manufacturer Part Number | Supplier Part Number
1 | 1 | C24 | 200u | ~ | C_EPCOS_B32320l | Unpolarized capacitor
2 | 1 | LA20 | XOP15 | ~ |  | Flash lamp tube
3 | 1 | R61 | 0R | ~ | R_0603_1608Metric_Pad0.98x0.95mm_HandSolder | Resistor
Color reference for columns:
KiCad Fields (default)
Generated Fields
User Fields
Empty Fields

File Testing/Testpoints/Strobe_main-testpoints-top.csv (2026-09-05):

Ref. | Net | X [mm] | Y [mm]
TP20 | DRV_OUT | 44.50 | 19.00
TP21 | LMP_EN | 36.00 | 42.50
TP22 | SH0 | 25.77 | 55.00
TP23 | SH0 | 33.50 | 55.00
TP24 | S1k | 82.00 | 98.50
TP25 | LMP | 69.00 | 8.00
TP26 | TP_REF | 64.00 | 92.00
TP27 | TP_PRI | 76.50 | 83.50
TP28 | Mon_IL | 44.50 | 26.50
TP60 | Net-(U60-PA0) | 32.00 | 17.50
TP61 | Net-(U60-PA1) | 32.00 | 20.00
TP62 | Mon_S1k_buf | 26.00 | 30.00
TP63 | Net-(U60-PB0) | 26.00 | 40.00
TP64 | Mon_IL_prot | 26.00 | 32.50
TP65 | Net-(U60-PB3) | 12.00 | 25.50
TP66 | Mon_LMP_buf | 26.00 | 35.00
TP67 | Net-(U60-PB4) | 12.00 | 23.00
TP68 | Net-(U60-PA7) | 26.00 | 37.50
TP69 | Net-(U60-PB5) | 12.00 | 20.50
TP70 | Vbus_ctrl | 12.00 | 37.00
TP71 | Light_sns | 32.00 | 12.50
TP72 | INT_EN | 12.00 | 34.50
TP73 | BOOT0 | 12.00 | 18.00
TP74 | Net-(U60-PA15) | 12.00 | 28.00
TP75 | SH0 | 12.00 | 30.50
TP76 | SH0 | 32.00 | 15.00
TP77 | SH0 | 26.00 | 42.50

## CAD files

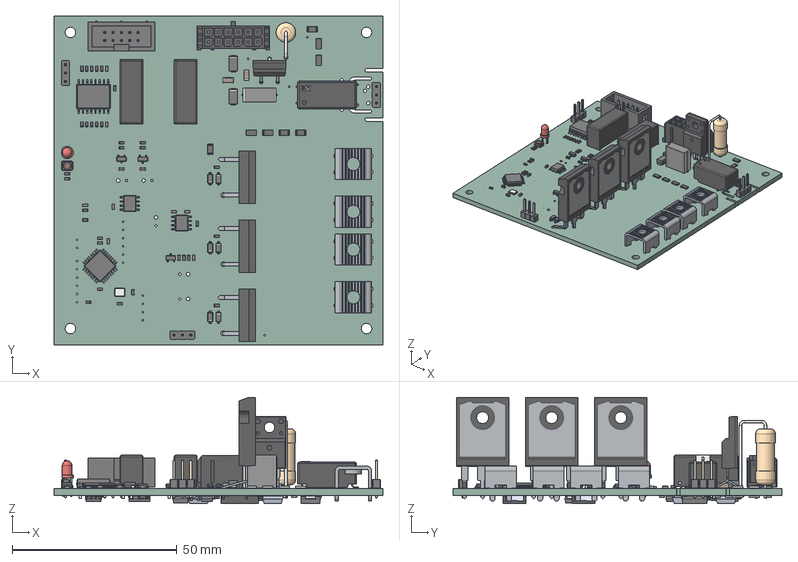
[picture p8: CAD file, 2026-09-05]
3D/Strobe_main.step
100.0 x 100.0 x 32.3 mm
R_1206_3216Metric x 16
R_0603_1608Metric x 37
D_SOD-123 x 8
PinHeader_1x03_P2.54mm_Vertical x 3
T44007_base x 4
C_1206_3216Metric x 2
C_0603_1608Metric x 27
SOT-23 x 3
SOIC-8_3.9x4.9mm_P1.27mm x 3
Crystal_SMD_3225-4Pin_3.2x2.5mm
ZS1052_SHT
LQFP-32_7x7mm_P0.8mm
Document
Document001
Document002
Document003
D_SMA x 4
SOIC-16W_7.5x10.3mm_P1.27mm
TO-247-3_mixed_vert x 3
IDC-Header_2x05_P2.54mm_Vertical
DCDC_module_B0505S-2W x 2
R_Axial_DIN0617_L17.0mm_D6.0mm_P7.62mm_Vertical
TO-220-3-Vert_staggered_3
C_Rect_L11.0mm_W4.2mm_P10.00mm_MKT
LED_D3.0mm
SOT-223 x 2
Strobe_main 1.100.1 x 2
Vishay_WSR3_union x 2
D_SMC
kibot_6cz_5_ph_PCB

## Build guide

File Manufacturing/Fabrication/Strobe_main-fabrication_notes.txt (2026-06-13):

FABRICATION NOTES (UNLESS OTHERWISE SPECIFIED)

1)	FABRICATE PER IPC-6012A CLASS 2.

2)	OUTLINE DEFINED IN SEPARATE GERBER FILE WITH
	"Edge_Cuts.GBR" SUFFIX.

	DIMENSIONS OF CIRCUMSIZED RECTANGLE SHOWN ON THIS
	DRAWING ARE FOR REFERENCE ONLY.

3)	SEE SEPARATE DRILL FILES WITH ".DRL" SUFFIX 
	FOR HOLE LOCATIONS.

	SELECTED HOLE LOCATIONS SHOWN ON THIS DRAWING 
	ARE FOR REFERENCE ONLY.

4)	SURFACE FINISH: HAL SNPB

5)	SOLDERMASK ON BOTH SIDES OF THE BOARD SHALL 
	BE LPI, COLOR GREEN.

6)	SILK SCREEN LEGEND TO BE APPLIED PER LAYER 
	STACKUP USING WHITE NON-CONDUCTIVE EPOXY INK.

7)	ALL VIAS ARE TENTED ON BOTH SIDES UNLESS 
	SOLDERMASK OPENED IN GERBER.

8)	VENDOR SHOULD FOLLOW ROHS COMPLIANT PROCESS 
	AND Pb FREE FOR MANUFACTURING

9)	PCB MATERIAL REQUIREMENTS:

	A.	FLAMMABILITY RATING MUST MEET OR EXCEED 
		UL94V-0 REQUIREMENTS.
	B.	Tg 170 C OR EQUIVALENT.
	C.	EQUIVALENT MATERIAL SHALL BE RoHS COMPLIANT, 
		HALOGEN FREE AND APPROVED BY CHURRASCOD ELECTRONICS.

10)	DESIGN GEOMETRY MINIMUM FEATURE SIZES:

	BOARD SIZE				100.000 × 100.000 mm
	BOARD THICKNESS		2.278 mm
	TRACE WIDTH			0.200 mm
	TRACE TO TRACE		-0.000 mm
	MIN. HOLE (PTH)			0.300 mm
	MIN. HOLE (NPTH)		1.000 mm
	ANNULAR RING			0.150 mm
	COPPER TO HOLE		0.300 mm
	COPPER TO EDGE		0.500 mm
	HOLE TO HOLE			0.250 mm

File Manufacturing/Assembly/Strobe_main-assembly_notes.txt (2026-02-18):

ASSEMBLY NOTES (UNLESS OTHERWISE SPECIFIED)

1)	DO NOT POPULATE PARTS MARKED WITH A RED CROSS.

2)	IF CONFLICTING INFORMATION IS FOUND BETWEEN THE ASSEMBLY
	FILE AND BOM, BOM SHOULD BE USED AS THE MAIN SOURCE.

3)	DOT IDENTIFIES PIN #1 LOCATION AND DEVICE ORIENTATION
	WHEN VIEWED FROM THE TOP.

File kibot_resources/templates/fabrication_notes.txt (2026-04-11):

FABRICATION NOTES (UNLESS OTHERWISE SPECIFIED)

1)	FABRICATE PER IPC-6012A CLASS 2.

2)	OUTLINE DEFINED IN SEPARATE GERBER FILE WITH
	"Edge_Cuts.GBR" SUFFIX.

	DIMENSIONS OF CIRCUMSIZED RECTANGLE SHOWN ON THIS
	DRAWING ARE FOR REFERENCE ONLY.

3)	SEE SEPARATE DRILL FILES WITH ".DRL" SUFFIX 
	FOR HOLE LOCATIONS.

	SELECTED HOLE LOCATIONS SHOWN ON THIS DRAWING 
	ARE FOR REFERENCE ONLY.

4)	SURFACE FINISH: ${pcb_finish_cap}

5)	SOLDERMASK ON BOTH SIDES OF THE BOARD SHALL 
	BE LPI, COLOR ${solder_mask_color_text_cap}.

6)	SILK SCREEN LEGEND TO BE APPLIED PER LAYER 
	STACKUP USING ${silk_screen_color_text_cap} NON-CONDUCTIVE EPOXY INK.

7)	ALL VIAS ARE TENTED ON BOTH SIDES UNLESS 
	SOLDERMASK OPENED IN GERBER.

8)	VENDOR SHOULD FOLLOW ROHS COMPLIANT PROCESS 
	AND Pb FREE FOR MANUFACTURING

9)	PCB MATERIAL REQUIREMENTS:

	A.	FLAMMABILITY RATING MUST MEET OR EXCEED 
		UL94V-0 REQUIREMENTS.
	B.	Tg 170 C OR EQUIVALENT.
	C.	EQUIVALENT MATERIAL SHALL BE RoHS COMPLIANT, 
		HALOGEN FREE AND APPROVED BY ${COMPANY_cap}.

10)	DESIGN GEOMETRY MINIMUM FEATURE SIZES:

	BOARD SIZE				${bb_w_mm} × ${bb_h_mm} mm
	BOARD THICKNESS		${thickness_mm} mm
	TRACE WIDTH			${track_mm} mm
	TRACE TO TRACE		${clearance_mm} mm
	MIN. HOLE (PTH)			${drill_pth_real_mm} mm
	MIN. HOLE (NPTH)		${drill_npth_real_mm} mm
	ANNULAR RING			${oar_mm} mm
	COPPER TO HOLE		${c2h_mm} mm
	COPPER TO EDGE		${c2e_mm} mm
	HOLE TO HOLE			${h2h_mm} mm
#?stackup and impedance_controlled

#?stackup and impedance_controlled
11)	REFER TO IMPEDANCE TABLE FOR IMPEDANCE CONTROL REQUIREMENTS.
#?stackup and impedance_controlled

#?stackup and impedance_controlled
12)	CONFIRM SPACE WIDTHS AND SPACINGS.

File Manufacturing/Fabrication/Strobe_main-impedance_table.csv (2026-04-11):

Transmission Line | Impedance [ohms] | Tolerance [ohms] | Layer | Trace Width [mm] | Gap [mm] | Ref. Layers
Edge-Coupled Coated Microstrip | 100 | ±10 % | L1 | 0.2032 | 0.28 | L2

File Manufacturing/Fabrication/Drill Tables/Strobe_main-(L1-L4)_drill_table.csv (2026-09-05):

Count | Hole Size | Plated | Hole Shape | Drill Layer Pair | Hole Type
69 | 0.30mm (11.81mils) | PTH | Round | F.Cu (Sig, PWR) - B.Cu (Sig, PWR) | Via
22 | 0.50mm (19.69mils) | PTH | Round | F.Cu (Sig, PWR) - B.Cu (Sig, PWR) | Pad
62 | 0.50mm (19.69mils) | PTH | Round | F.Cu (Sig, PWR) - B.Cu (Sig, PWR) | Via
5 | 0.70mm (27.56mils) | PTH | Round | F.Cu (Sig, PWR) - B.Cu (Sig, PWR) | Pad
12 | 0.80mm (31.50mils) | PTH | Round | F.Cu (Sig, PWR) - B.Cu (Sig, PWR) | Pad
2 | 0.90mm (35.43mils) | PTH | Round | F.Cu (Sig, PWR) - B.Cu (Sig, PWR) | Pad
19 | 1.00mm (39.37mils) | PTH | Round | F.Cu (Sig, PWR) - B.Cu (Sig, PWR) | Pad
12 | 1.02mm (40.16mils) | PTH | Round | F.Cu (Sig, PWR) - B.Cu (Sig, PWR) | Pad
8 | 1.10mm (43.31mils) | PTH | Round | F.Cu (Sig, PWR) - B.Cu (Sig, PWR) | Pad
2 | 1.20mm (47.24mils) | PTH | Round | F.Cu (Sig, PWR) - B.Cu (Sig, PWR) | Pad
6 | 1.50mm (59.06mils) | PTH | Round | F.Cu (Sig, PWR) - B.Cu (Sig, PWR) | Pad
16 | 1.80mm (70.87mils) | PTH | Round | F.Cu (Sig, PWR) - B.Cu (Sig, PWR) | Pad
1 | 3.20mm (125.98mils) | PTH | Round | F.Cu (Sig, PWR) - B.Cu (Sig, PWR) | Pad
Total 236

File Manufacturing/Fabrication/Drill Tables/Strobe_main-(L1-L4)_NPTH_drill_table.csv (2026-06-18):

Count | Hole Size | Plated | Hole Shape | Drill Layer Pair | Hole Type
3 | 1.00mm (39.37mils) | NPTH | Round | F.Cu (Sig, PWR) - B.Cu (Sig, PWR) | Mechanical
2 | 1.02mm (40.16mils) | NPTH | Round | F.Cu (Sig, PWR) - B.Cu (Sig, PWR) | Mechanical
3 | 3.20mm (125.98mils) | NPTH | Round | F.Cu (Sig, PWR) - B.Cu (Sig, PWR) | Mechanical
Total 8

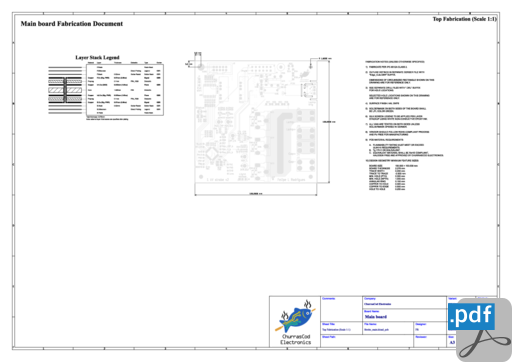
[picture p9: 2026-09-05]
HTML/images/cat_pdf_fabrication_Strobe_main-fabrication.png

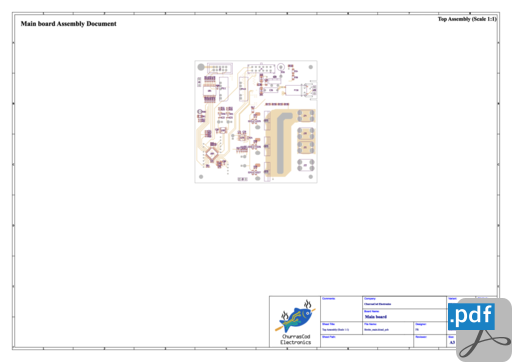
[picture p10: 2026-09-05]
HTML/images/cat_pdf_assembly_Strobe_main-assembly.png

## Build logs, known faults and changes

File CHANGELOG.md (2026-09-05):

# Changelog

## [Unreleased]

## [2.0.1] - 2026-09-05

-   Changed C22 and C23 to 1 nF

## [2.0.0] - 2026-06-23

-   decreased impedance of Ipeak measurement divider, removed buffer and fed signal directly to MCU
-   reworked gate drive resistors
-   reworked power input
-   modified some of the testpoints and added extra "GND testpoints"
-   reworked test pulse circuit to achive higher frequency
-   added mlcc to MCU rst line

## [1.0.0] - 2026-04-11

### Migrated existing project to template (KDT)

[Unreleased]: https://github.com/FLRHW/Strobe_main/compare/2.0.1...HEAD

[2.0.1]: https://github.com/FLRHW/Strobe_main/compare/2.0.0...2.0.1

[2.0.0]: https://github.com/FLRHW/Strobe_main/compare/1.0.0...2.0.0

[1.0.0]: https://github.com/FLRHW/Strobe_main/compare/7dbe69f50b9ce31433772c6b542f035e6a8d0f9c...1.0.0

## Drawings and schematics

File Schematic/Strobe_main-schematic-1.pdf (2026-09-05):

1

# Powersupply

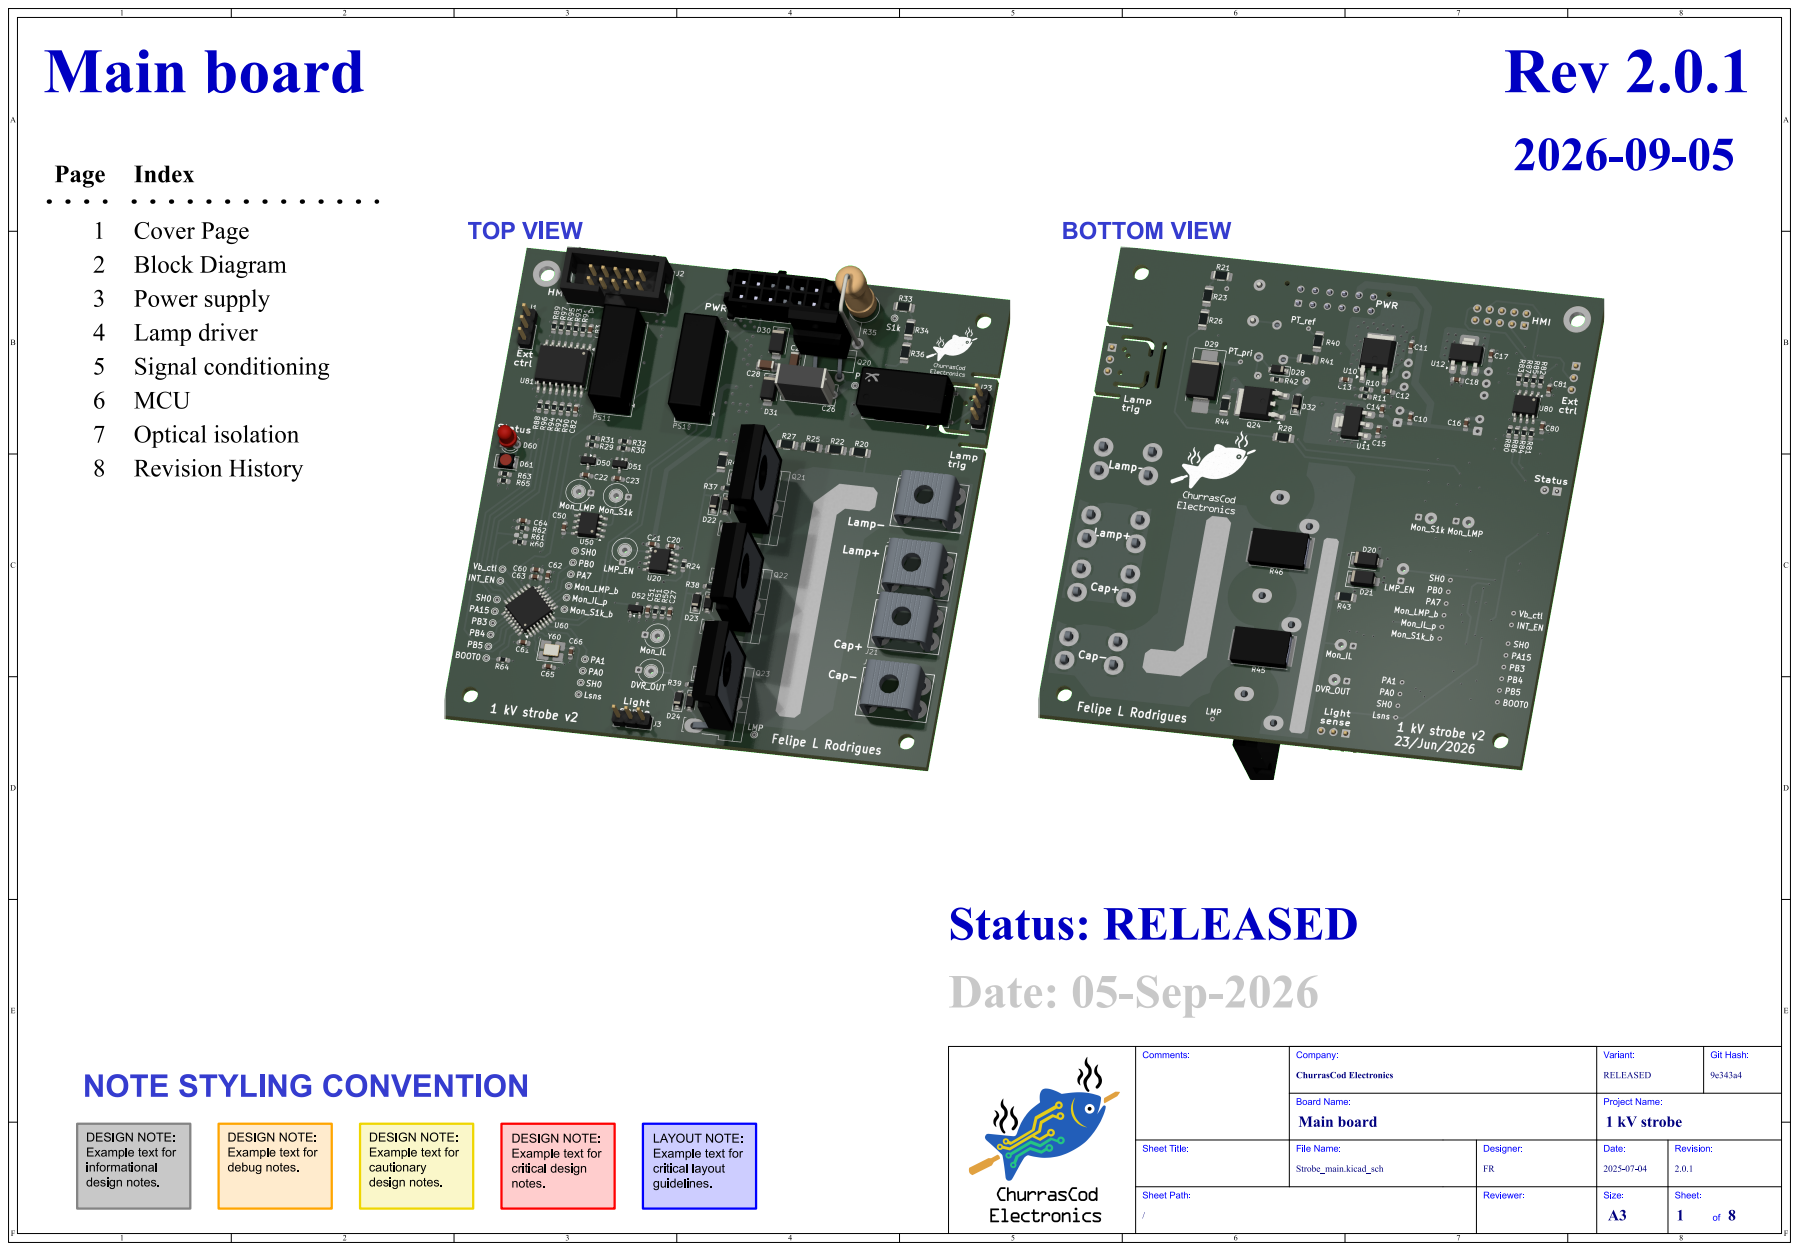
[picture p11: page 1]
Sheet: of 8; Size: A3; Strobe_main.kicad_sch; Board Name:; Variant: RELEASED; Company: ChurrasCodElectronics Main board; 1 kV strobe; Sheet Title:; File Name:; /Sheet Path: Comments:; Git Hash: 9e343a4 RevisionHistory; kibot_image_png_3d_viewer_angled_bottom DESIGN NOTE:; kibot_image_png_3d_viewer_angled_top Opticalisolation; RevisionHistory; MCU; Lampdriver; Date:05-Sep-2026; Status:RELEASED; Rev2.0.1; CoverPage; BOTTOM VIEW; Index; Main board; Page; Block Diagram; Signalconditioning; TOP VIEW

NOTE STYLING CONVENTION

Revision: 2.0.1 Date: Project Name: 2025-07-04 Reviewer: Designer:

DESIGN NOTE:
Example text for
informational
design notes.

cautionary

critical design
notes.

LAYOUT NOTE:
critical layout
guidelines.

debug notes.

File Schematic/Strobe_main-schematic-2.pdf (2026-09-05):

# Ext_EN BlockDiagram

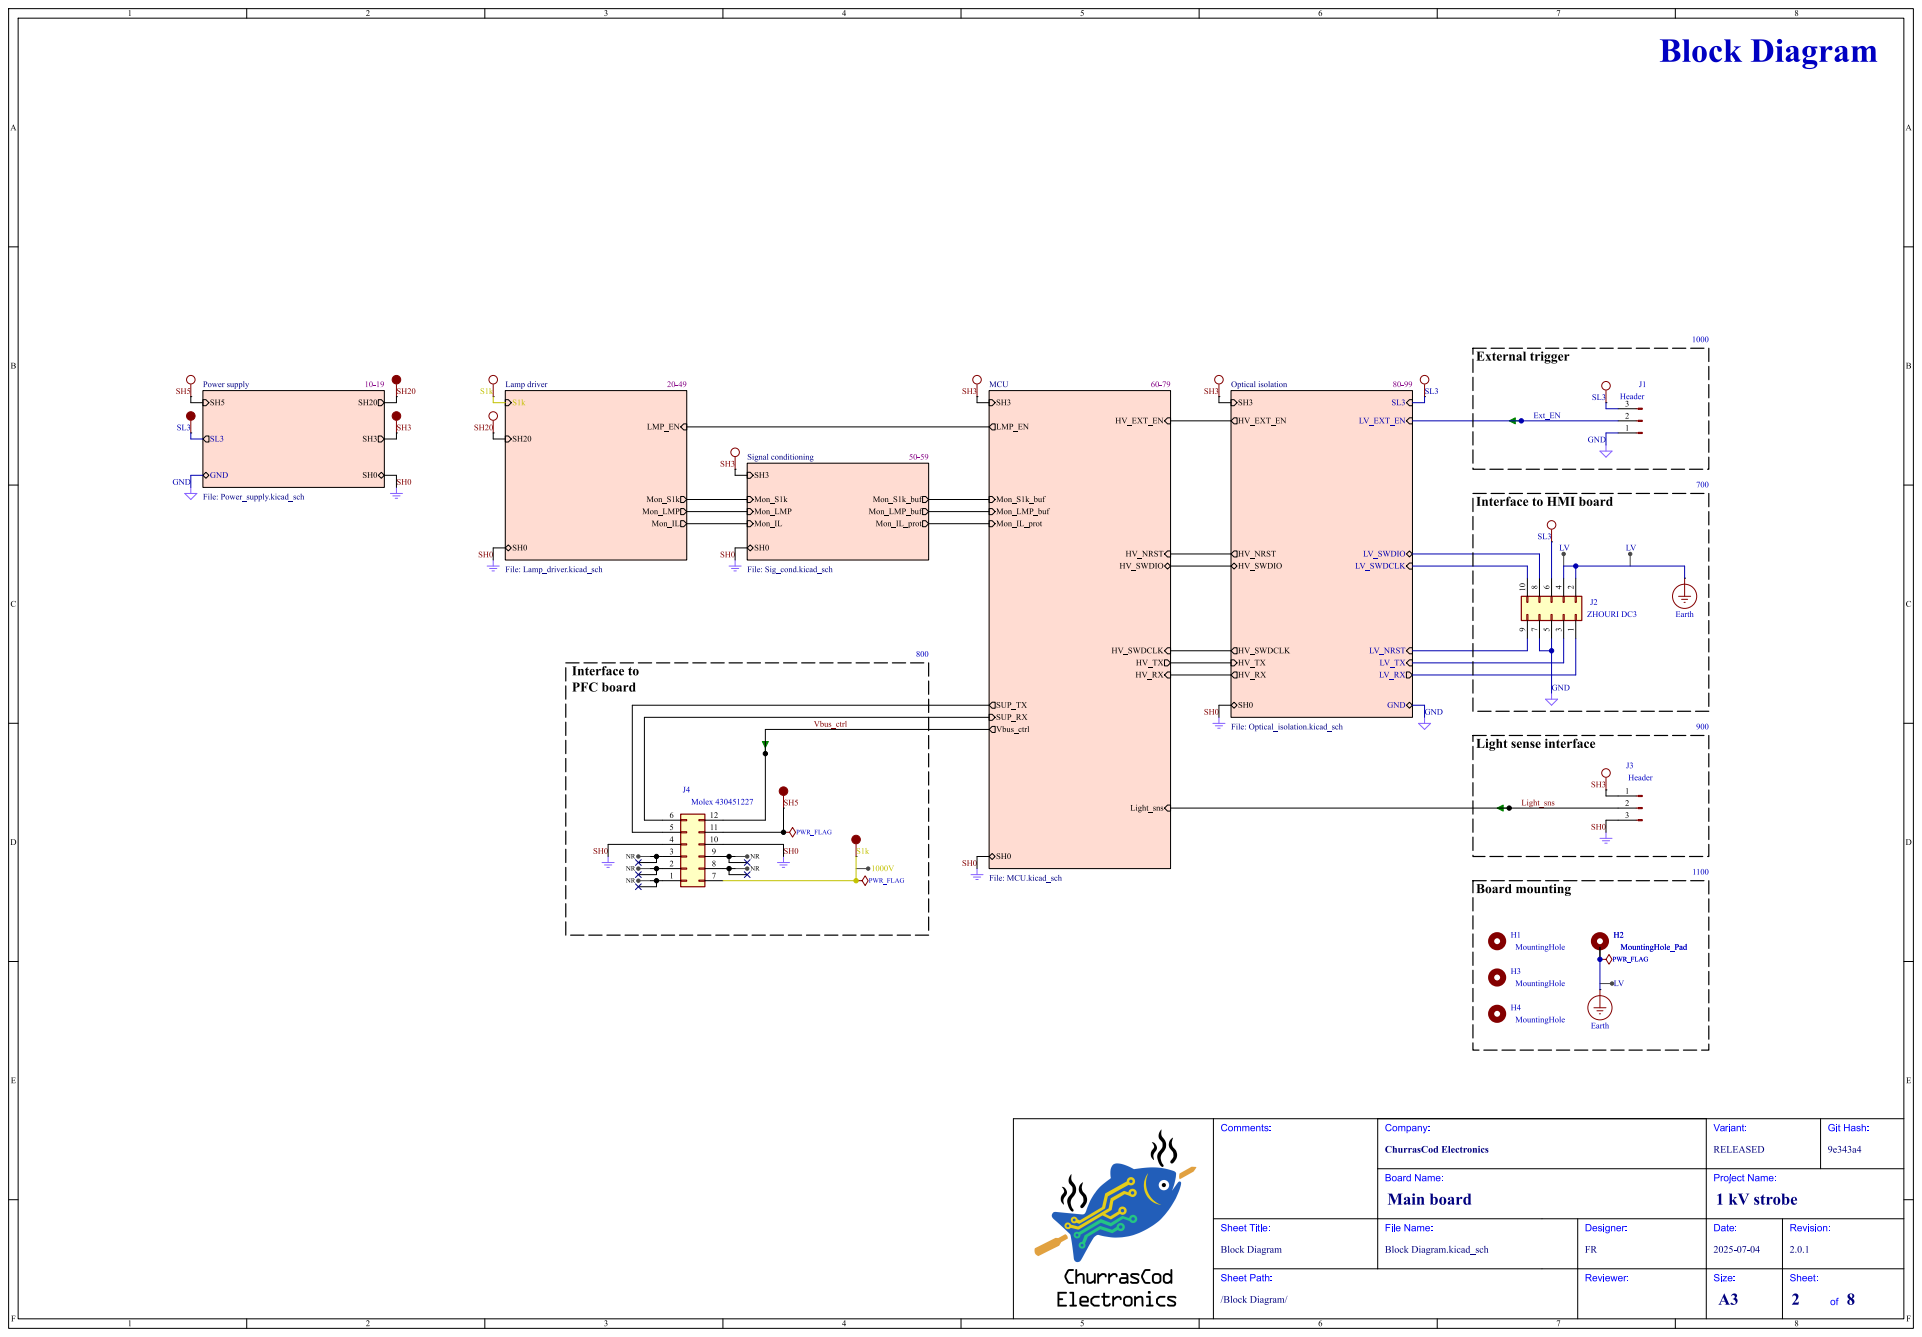
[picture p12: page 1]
Sheet: of 8; Size: A3; Revision: 2.0.1 Date: Project Name: 2025-07-04 Reviewer: Designer: Block Diagram.kicad_sch; Board Name:; Variant: RELEASED; Company: ChurrasCodElectronics Main board; 1 kV strobe; Sheet Title:; File Name:; Comments:; Git Hash: 9e343a4; LMP_EN Mon_LMP Mon_S1k Mon_IL; Lampdriver File: Lamp_driver.kicad_sch; SL3 GND; SH0 SH3 HV_RX HV_TX HV_SWDIO; HV_SWDCLK HV_NRST HV_EXT_EN; LV_EXT_EN; LV_SWDIO; LV_NRST; LV_SWDCLK Opticalisolation File: Optical_isolation.kicad_sch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

/Block Diagram/ Sheet Path: Block Diagram

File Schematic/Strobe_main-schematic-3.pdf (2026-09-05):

# SL3 SH0 SH20 SH3 GND

10-19

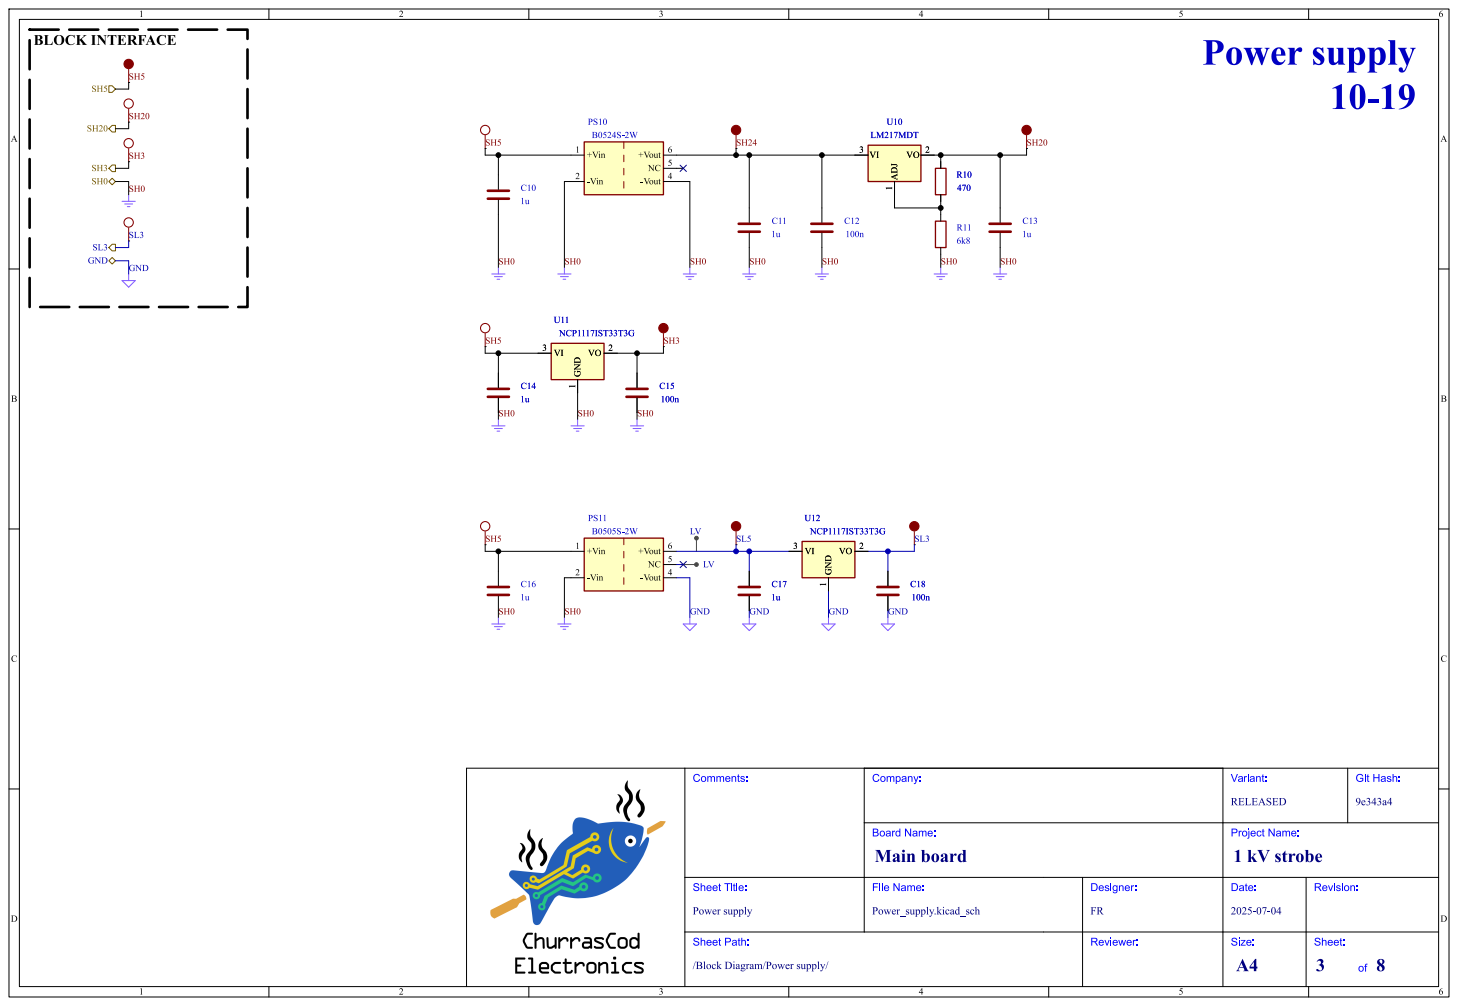
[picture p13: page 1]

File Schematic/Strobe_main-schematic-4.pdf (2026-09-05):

510k R25

510k R22

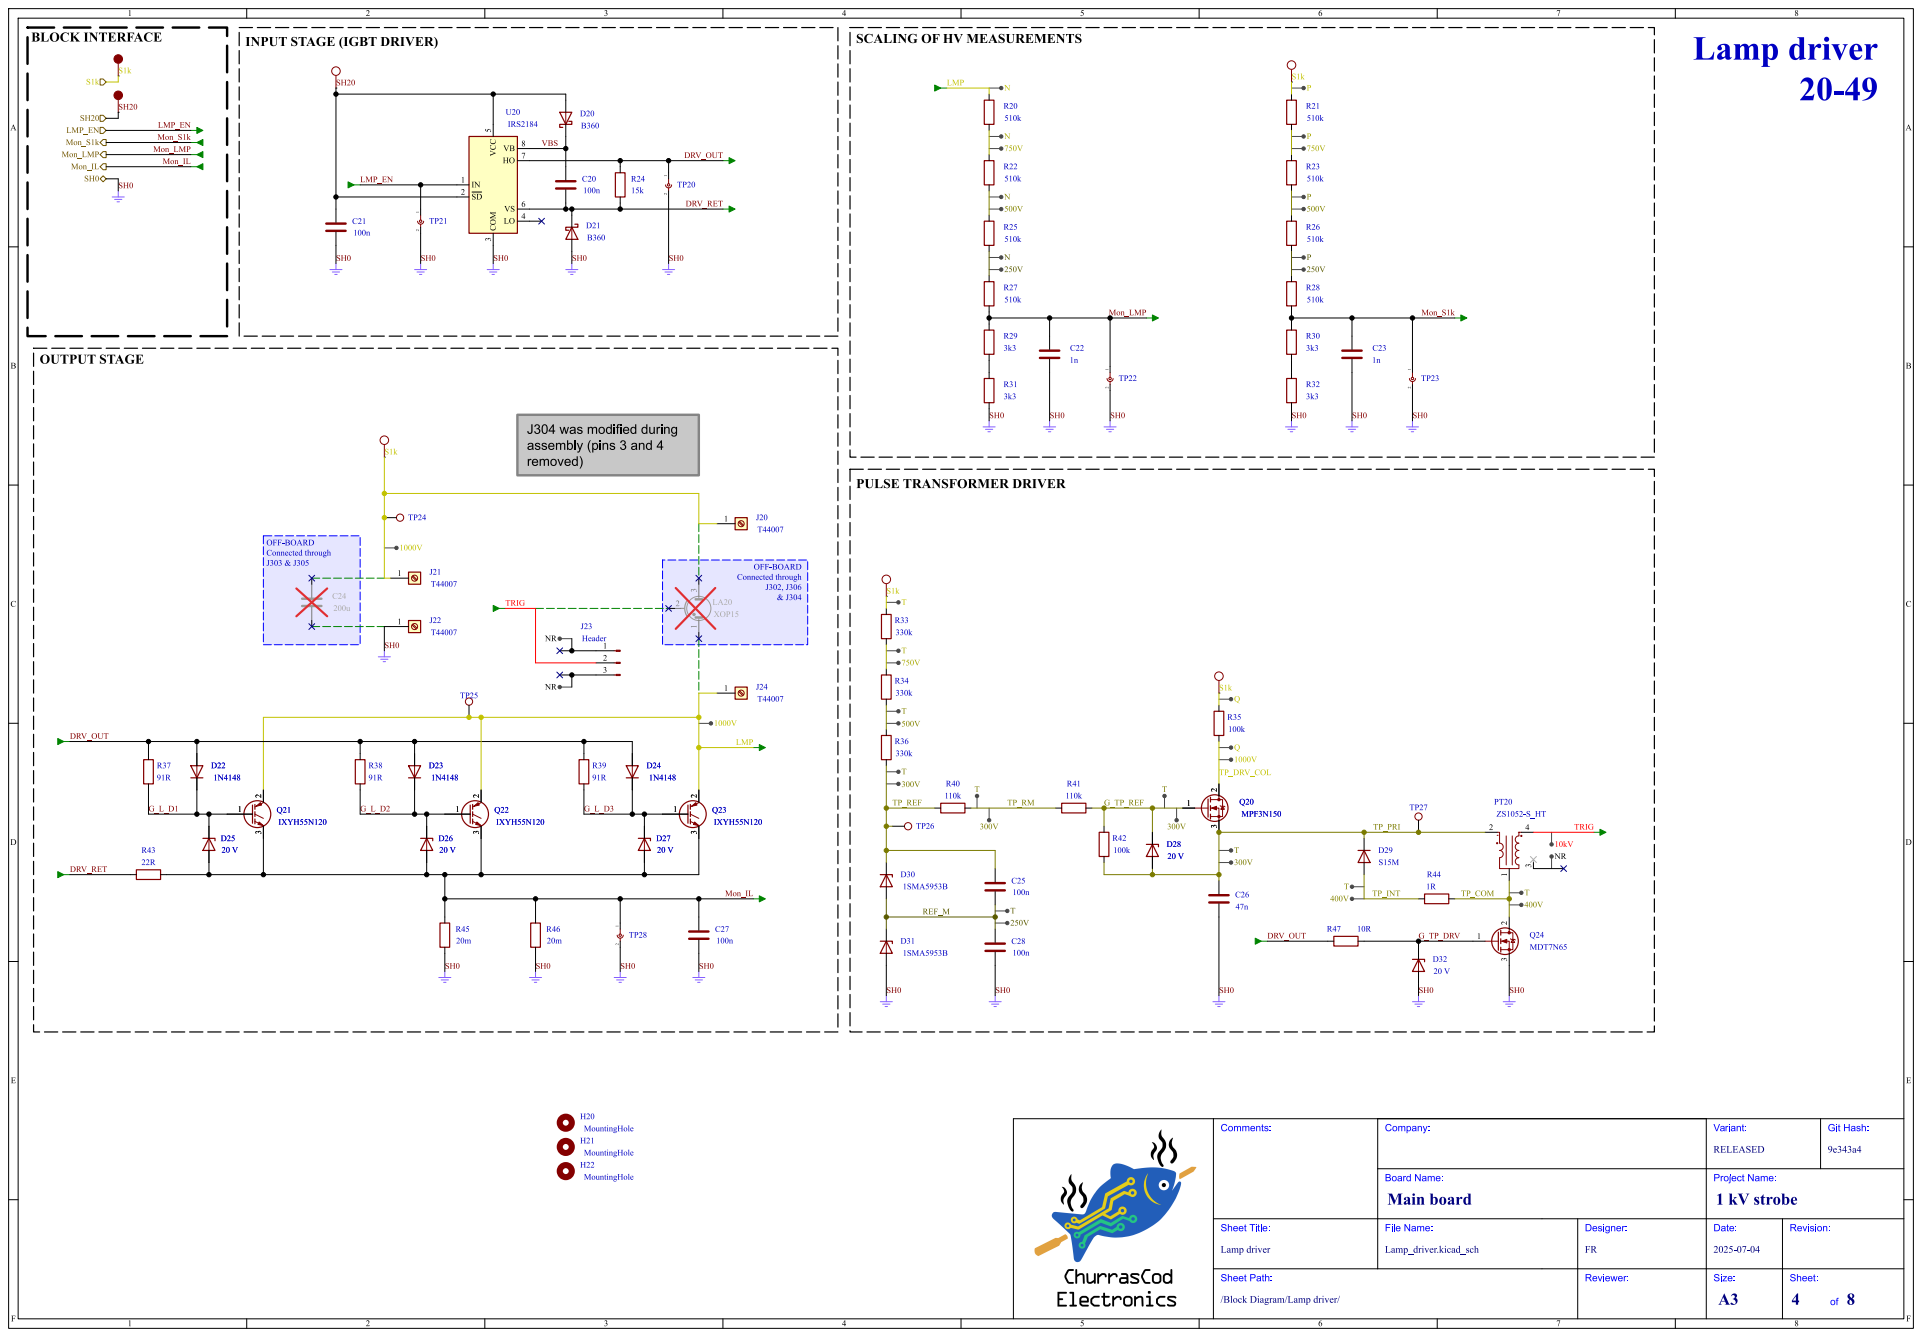
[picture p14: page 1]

INPUT STAGE(IGBT DRIVER)

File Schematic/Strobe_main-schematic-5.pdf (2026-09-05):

50-59

BLOCK INTERFACE | LAMP DRIVER VOLTAGES & CURRENT

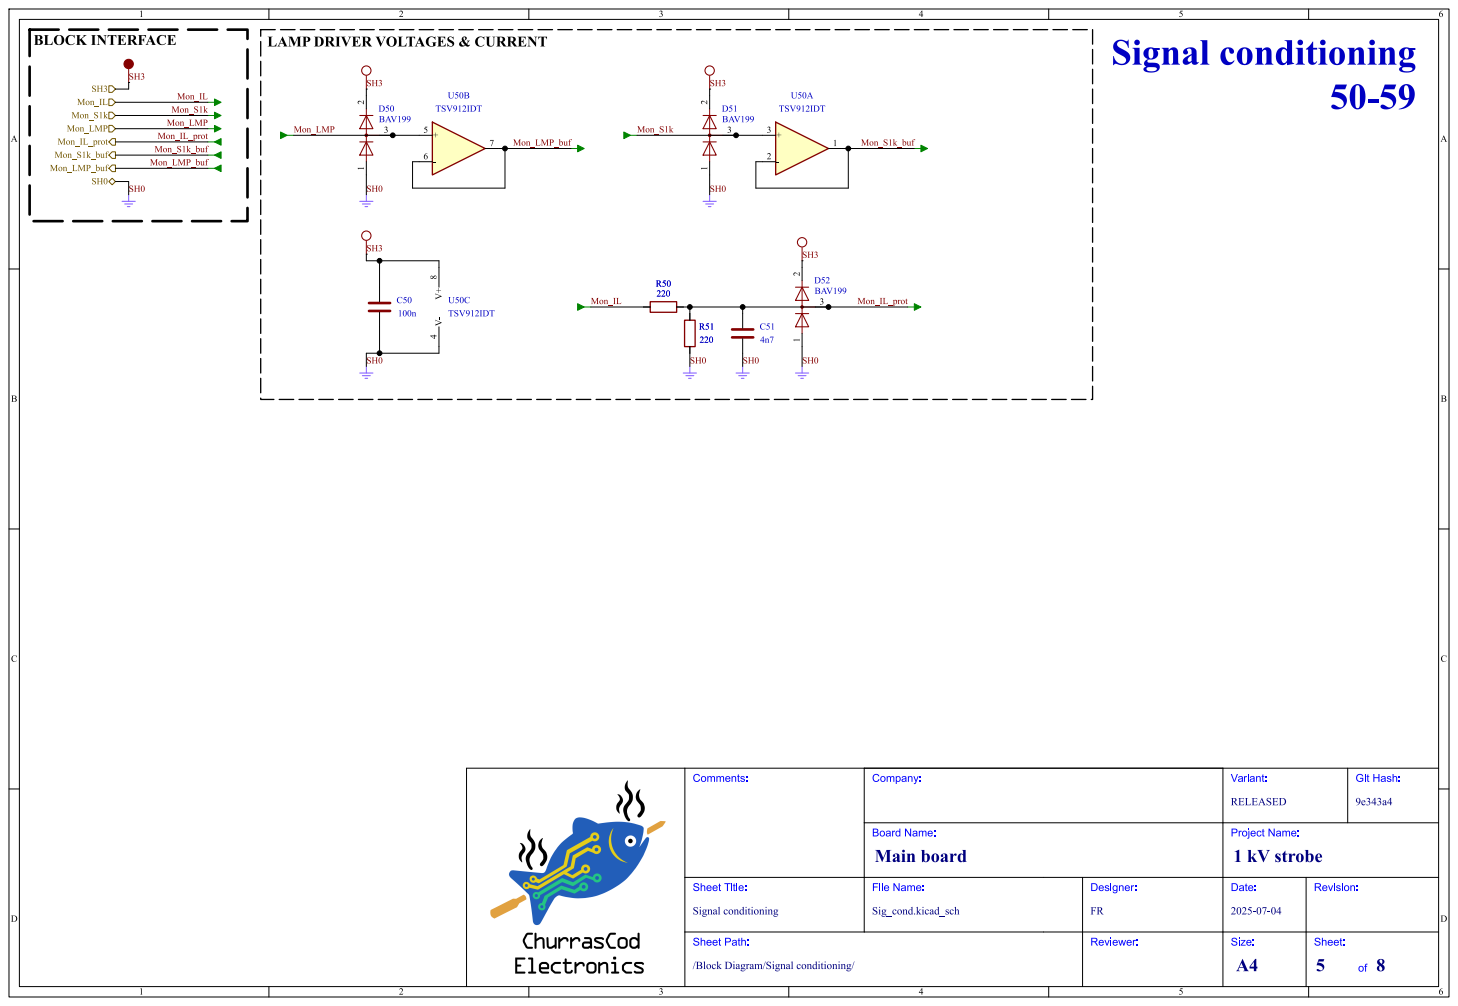
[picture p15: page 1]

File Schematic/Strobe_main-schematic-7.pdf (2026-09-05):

4k7 R98

# 4k7 R92 0R

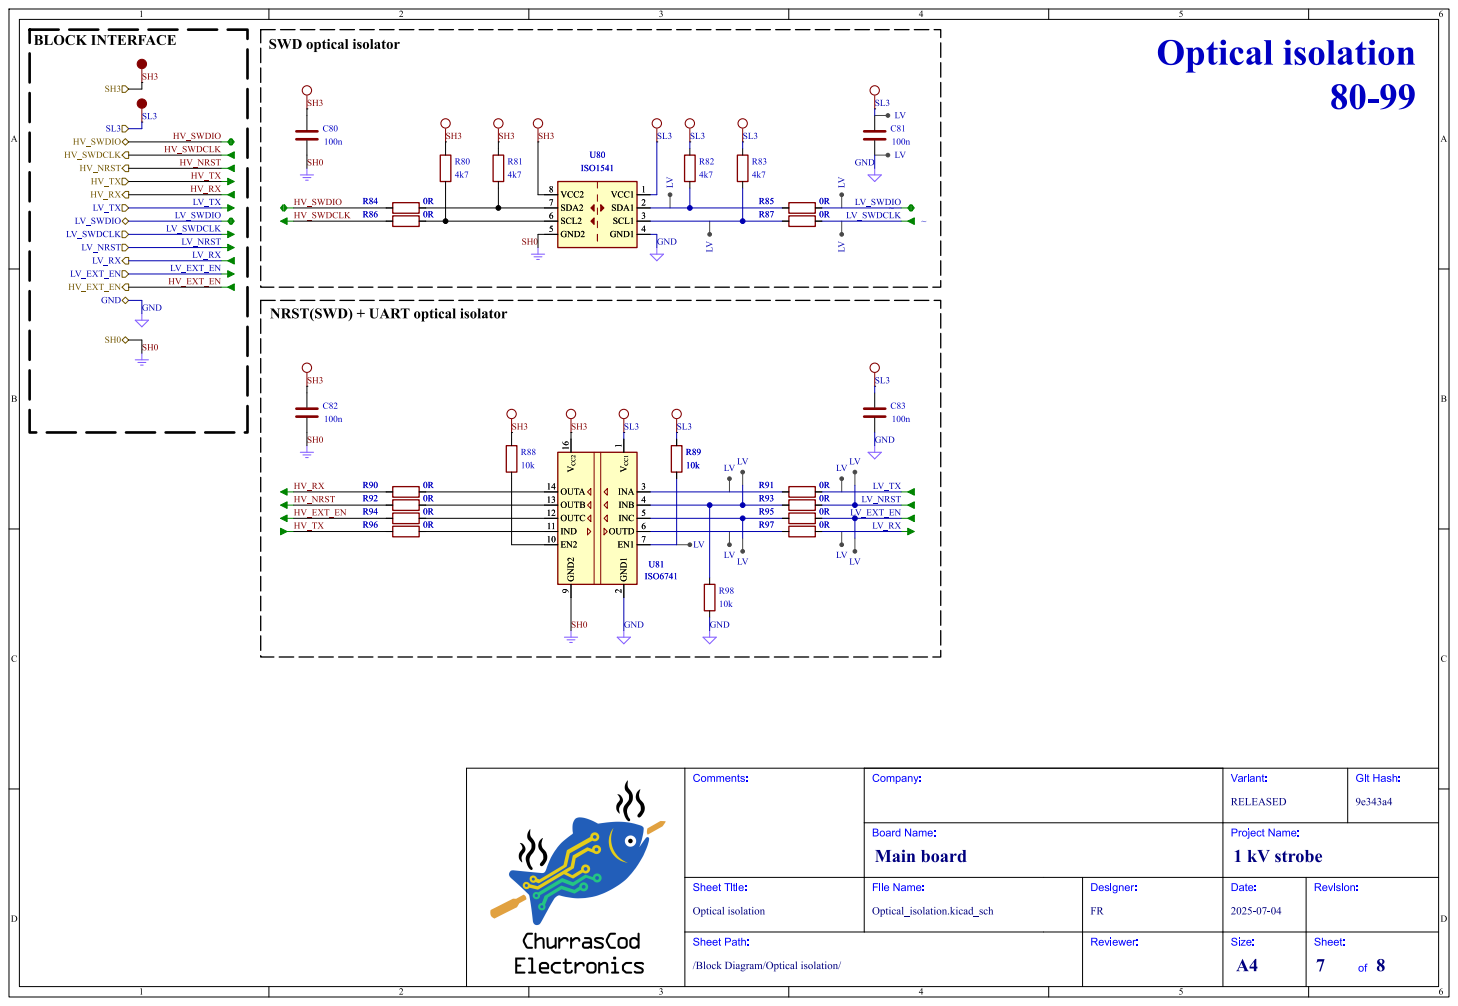
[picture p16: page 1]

NRST(SWD) + UART opticalisolator

INC 5 OUTD 6 EN1 7 V_{CC¹} 1 GND¹

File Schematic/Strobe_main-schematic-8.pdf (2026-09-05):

# RevisionHistory

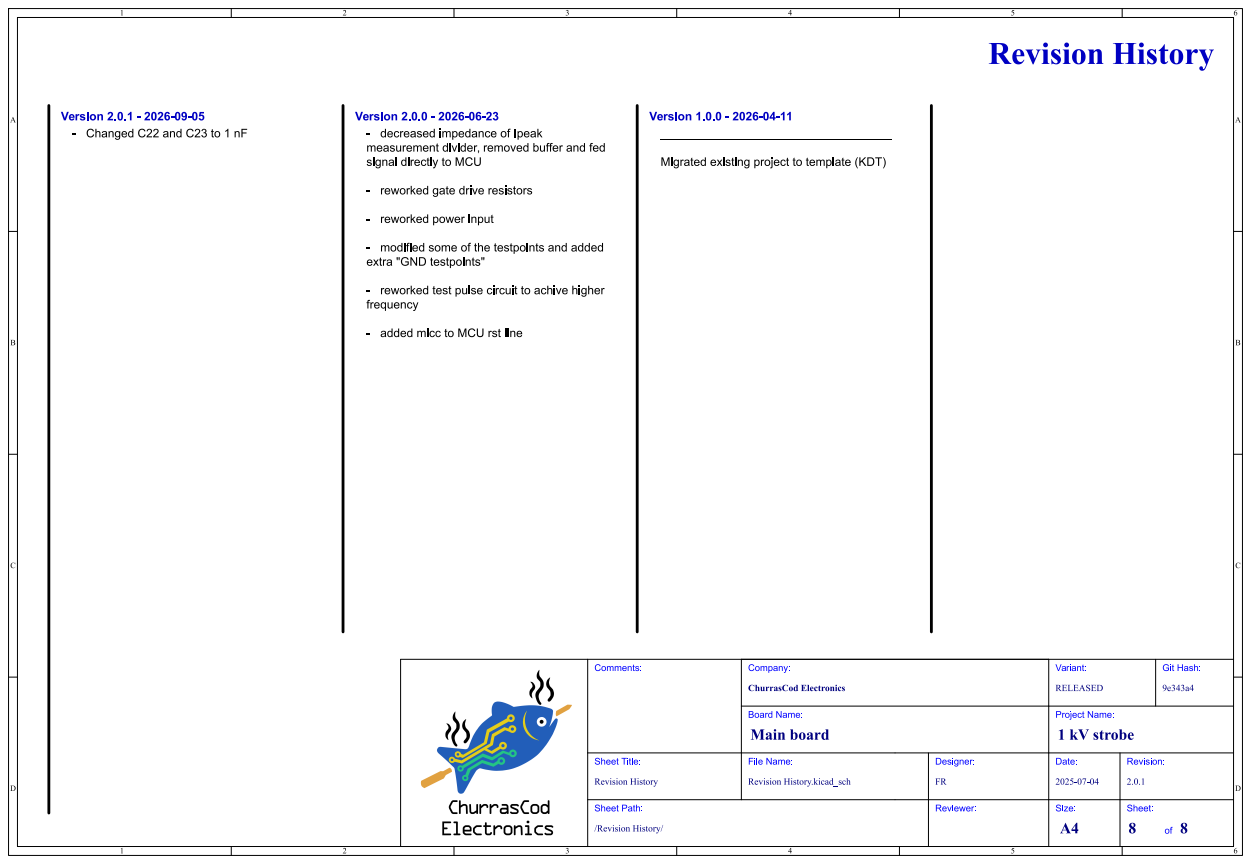
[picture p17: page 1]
Sheet: of 8; Size: A4; Revision: 2.0.1 Date: Project Name: 2025-07-04 Reviewer: Designer: RevisionHistory.kicad_sch; Board Name:; Variant: RELEASED; Company: ChurrasCodElectronics Main board; 1 kV strobe; Sheet Title:; File Name:; /RevisionHistory/ Sheet Path: RevisionHistory Comments:; Git Hash: 9e343a4; Version 2.0.1 - 2026-09-05; - Changed C22 and C23 to 1 nF; - decreased impedance of Ipeak; Version 2.0.0 - 2026-06-23

Version 1.0.0 - 2026-04-11
___________________________________ Migrated existing project to template (KDT)

measurement divider, removed buffer and fed
signal directly to MCU

- reworked gate drive resistors

- reworked power input - modified some of the testpoints and added

extra "GND testpoints"

- reworked test pulse circuit to achive higher
frequency

- added mlcc to MCU rst line

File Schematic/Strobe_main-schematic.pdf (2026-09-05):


Revision: 2.0.1 Date: Project Name: 2025-07-04 Reviewer: Designer:


/Block Diagram/ Sheet Path: Block Diagram



INPUT STAGE(IGBT DRIVER)


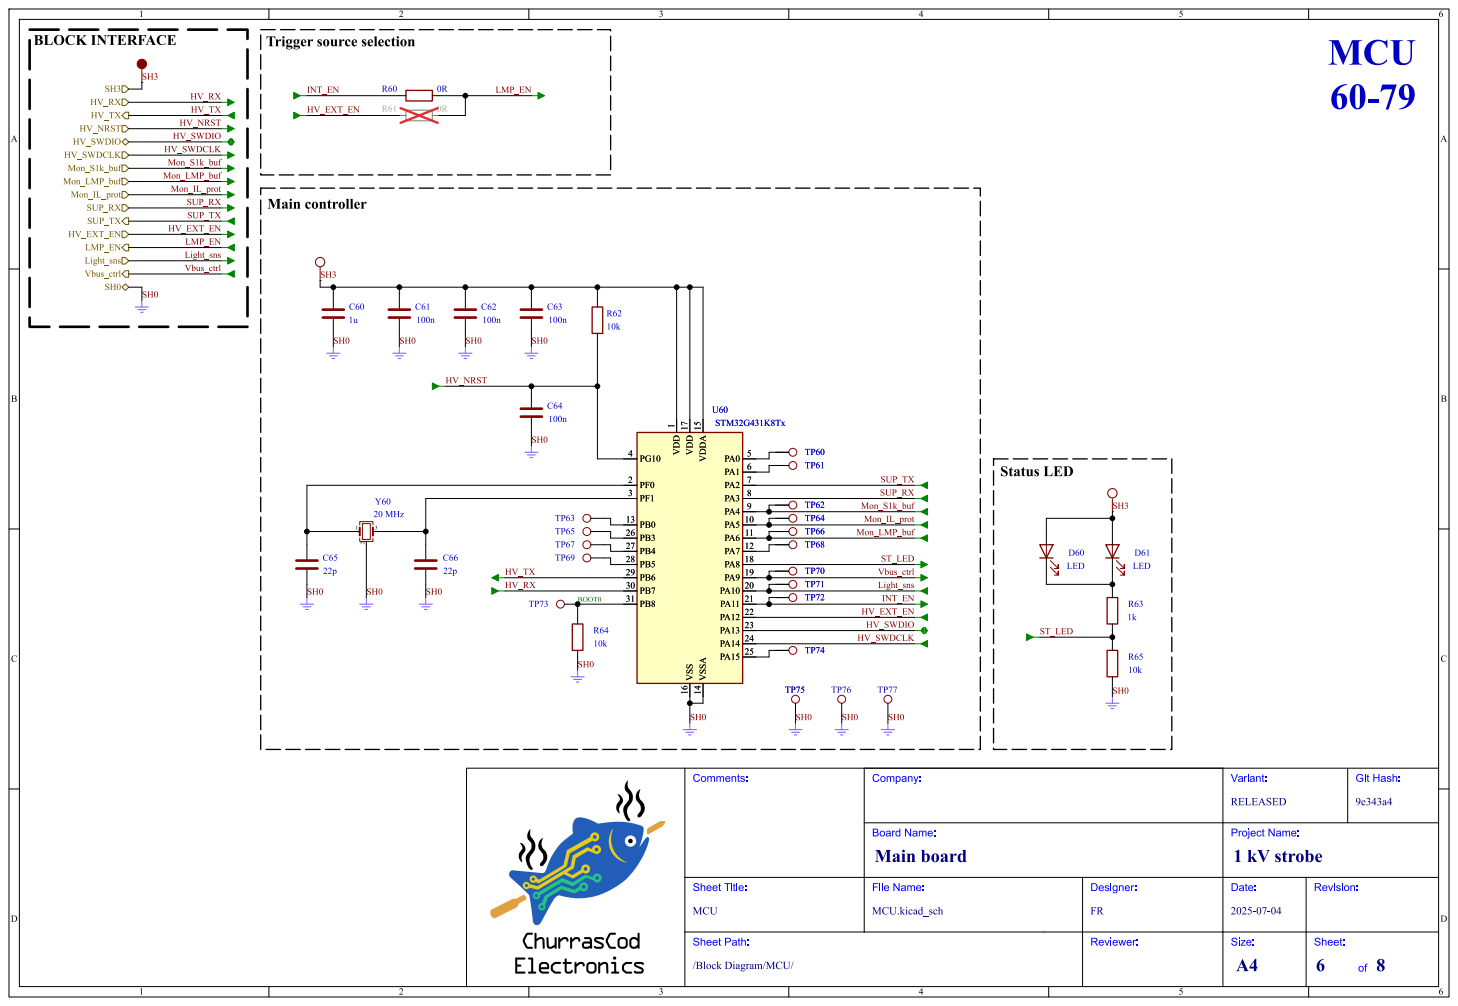
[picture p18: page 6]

1 VDD 17 VSS 16 VDDA 15 VSSA 14 PA0 5 PA1 6 PA2 7 PA3 8 PA4 9 PA5 10 PA6 11 PA7 12 PA8 18 PA9 19 PA10 20 PA11 21 PA12 22 PA13 23 PA14 24 PA15 25 U60 STM32G431K8Tx HV_SWDCLK HV_SWDIO

1 VDD 17 VSS 16 VDDA 15 VSSA 14 PA0 5 PA1 6 PA2 7 PA3 8 PA4 9 PA5 10 PA6 11 PA7 12 PA8 18 PA9 19 PA10 20 PA11 21 PA12 22 PA13 23 PA14 24 PA15 25 TP71 TP72 TP74 TP75

/Block Diagram/MCU/ Sheet Path: MCU


NRST(SWD) + UART opticalisolator


Version 1.0.0 - 2026-04-11
___________________________________ Migrated existing project to template (KDT)

measurement divider, removed buffer and fed
signal directly to MCU

- reworked gate drive resistors

- reworked power input - modified some of the testpoints and added

- reworked test pulse circuit to achive higher
frequency

- added mlcc to MCU rst line

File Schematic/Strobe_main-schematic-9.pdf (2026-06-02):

Version 1.0.1 not found.
Version 1.0.1 not found. | ___________________________________ Migrated existing project to template (KDT)

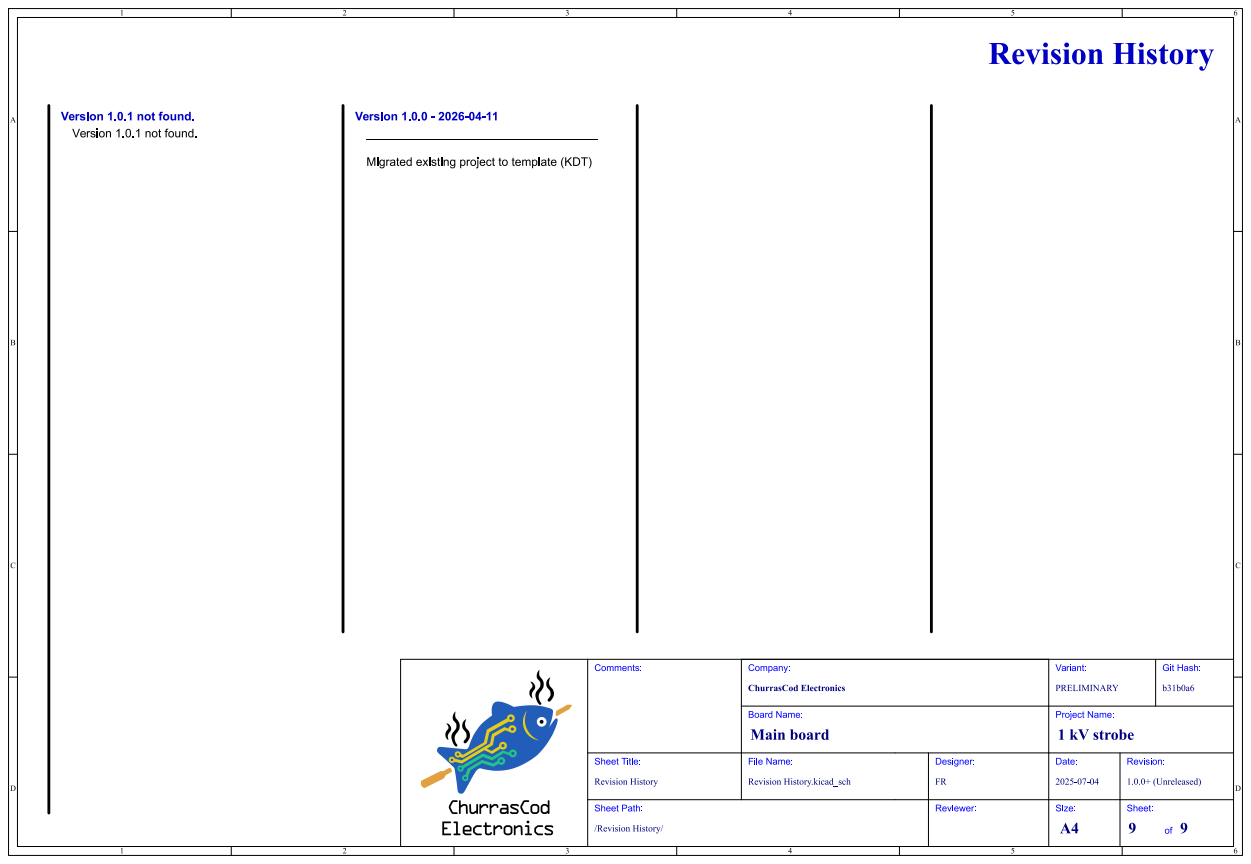
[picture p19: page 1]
Sheet: of 9; Size: A4; Revision: 1.0.0+(Unreleased) Date: Project Name: 2025-07-04 Reviewer: Designer: RevisionHistory.kicad_sch; Board Name:; Variant: PRELIMINARY Company: ChurrasCodElectronics Main board; 1 kV strobe; Sheet Title:; File Name:; /RevisionHistory/ Sheet Path: RevisionHistory Comments:; Git Hash: b31b0a6; Version 1.0.0 - 2026-04-11; RevisionHistory

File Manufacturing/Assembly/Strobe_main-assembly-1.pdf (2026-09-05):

# Top Assembly (Scale 1:1) Main board Assembly Document

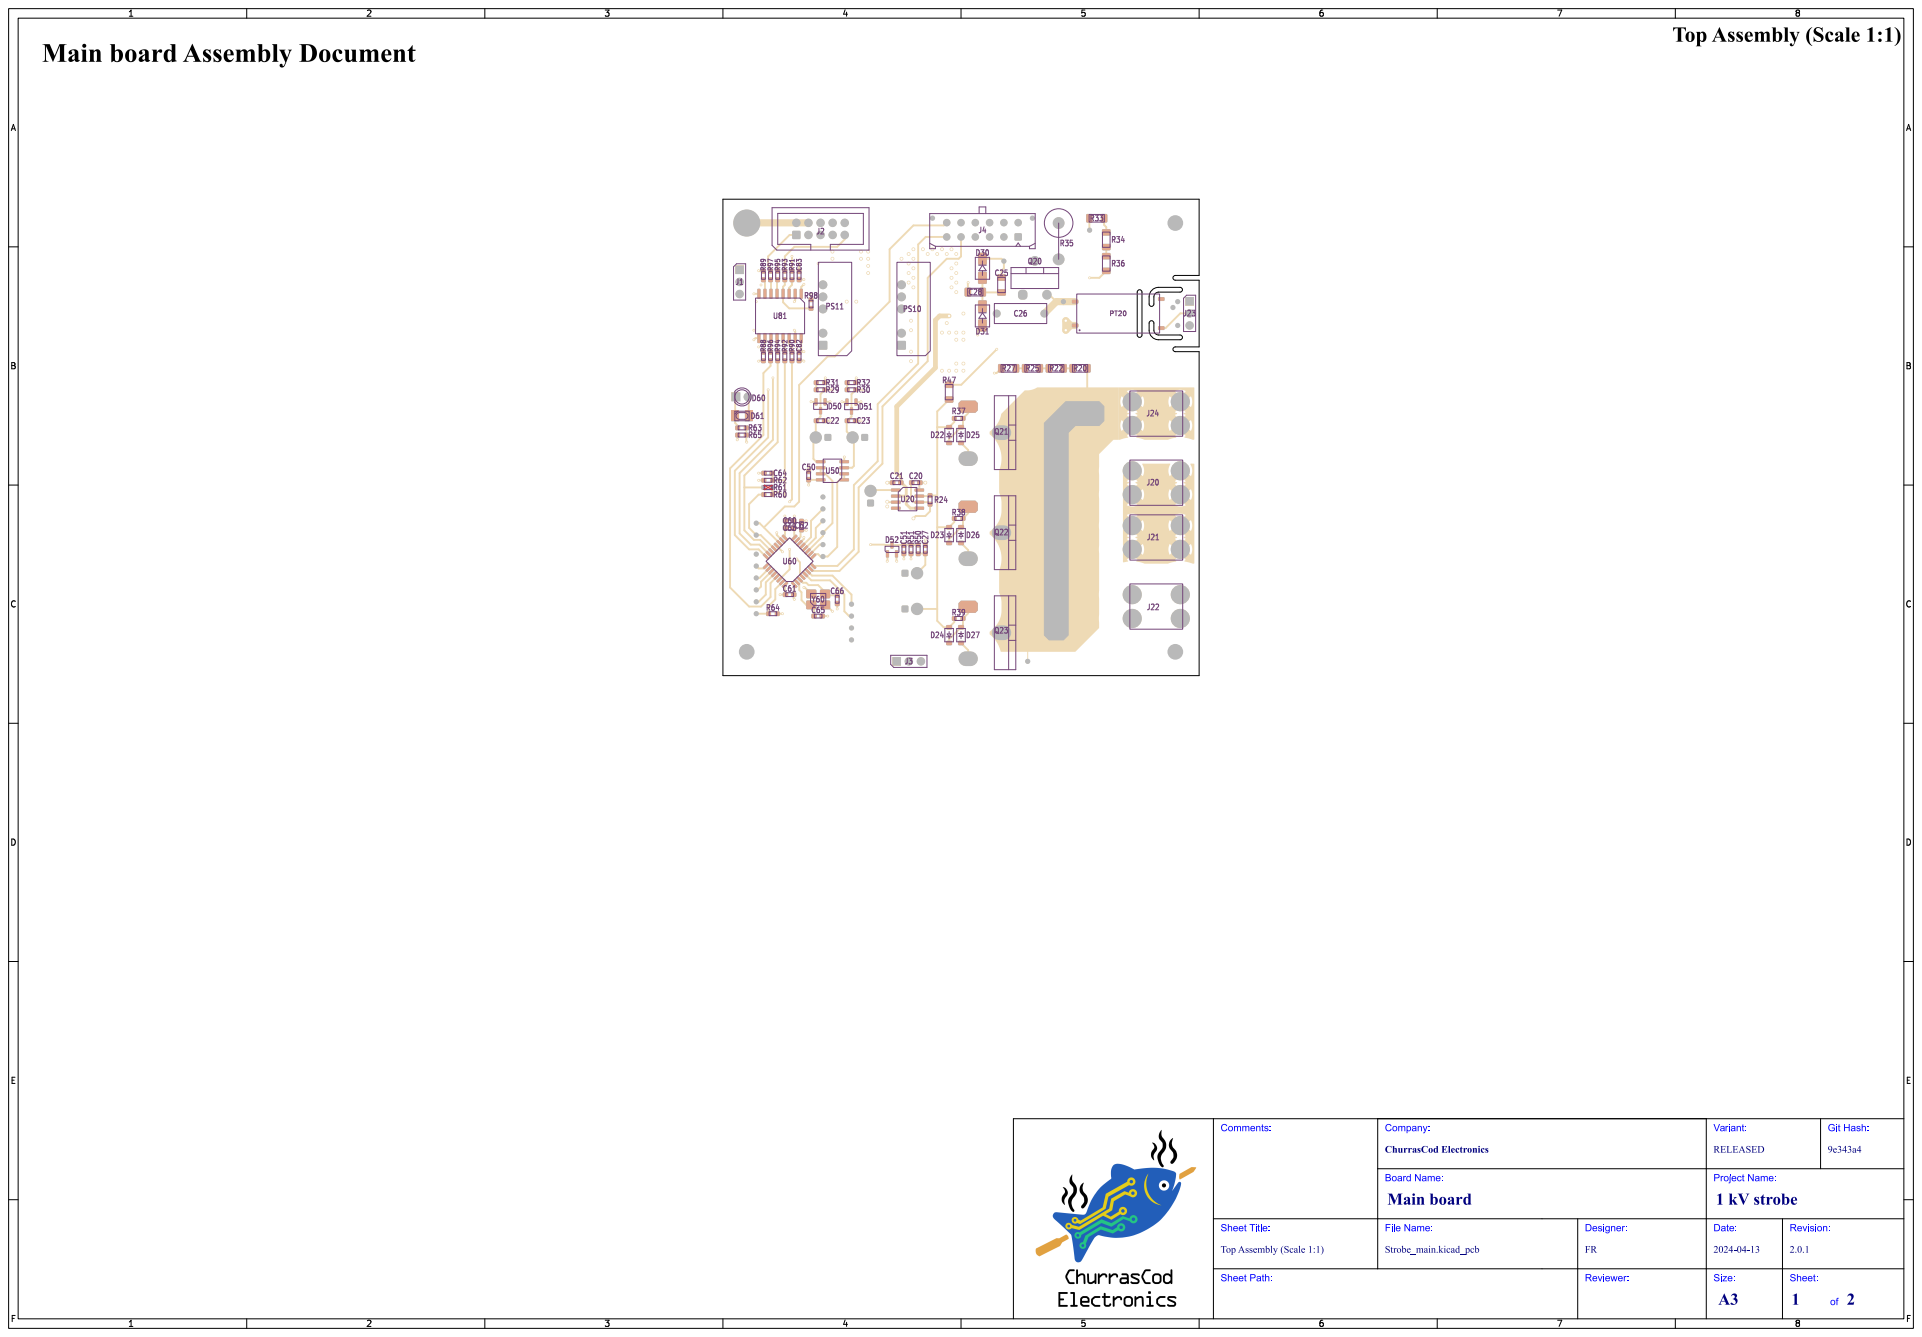
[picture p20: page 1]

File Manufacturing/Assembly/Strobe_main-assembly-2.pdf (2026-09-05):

# Bottom Assembly (Scale 1:1) Main board Assembly Document

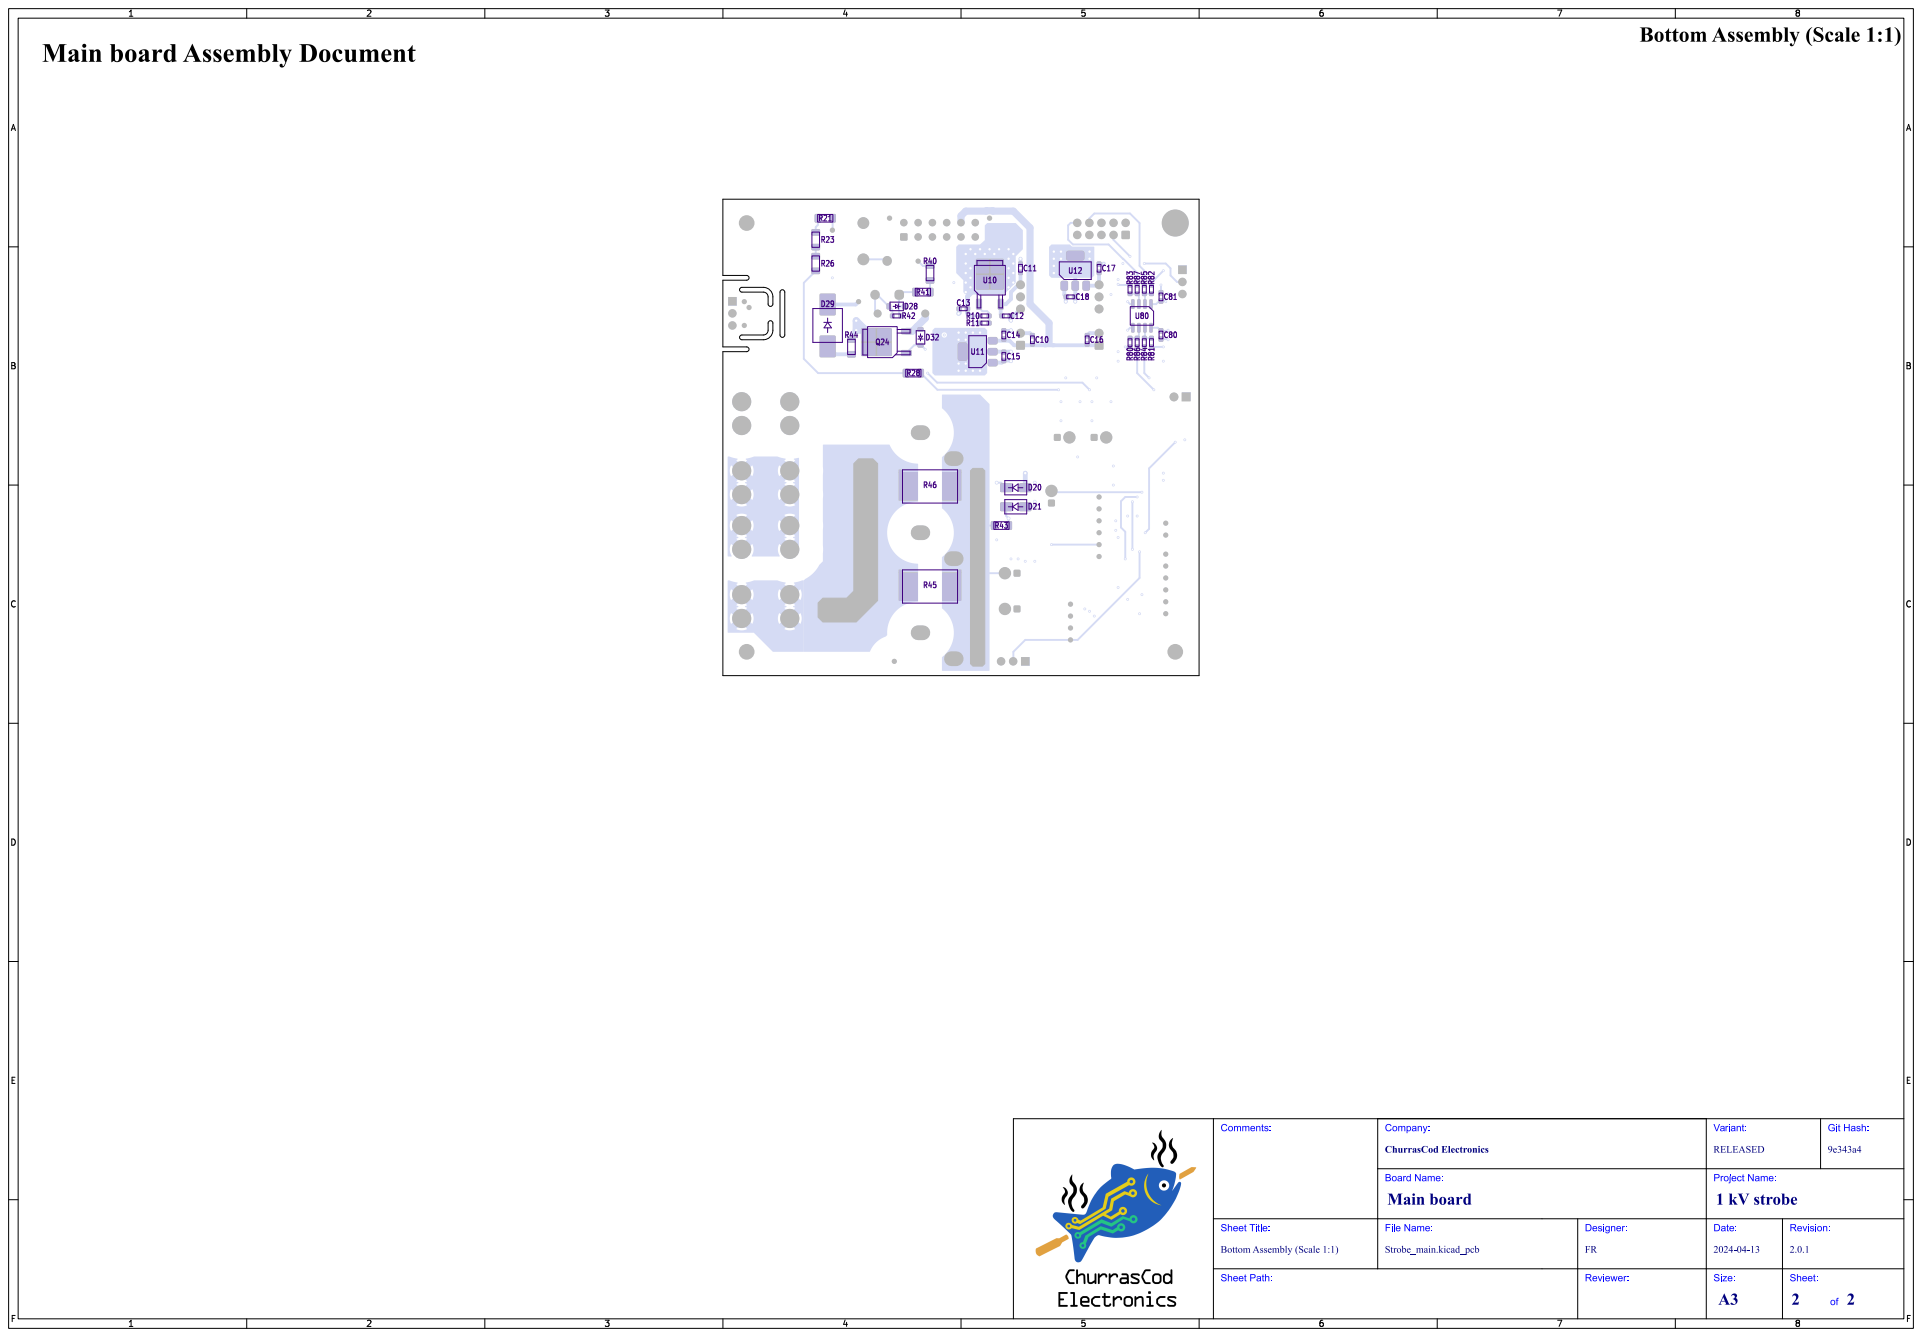
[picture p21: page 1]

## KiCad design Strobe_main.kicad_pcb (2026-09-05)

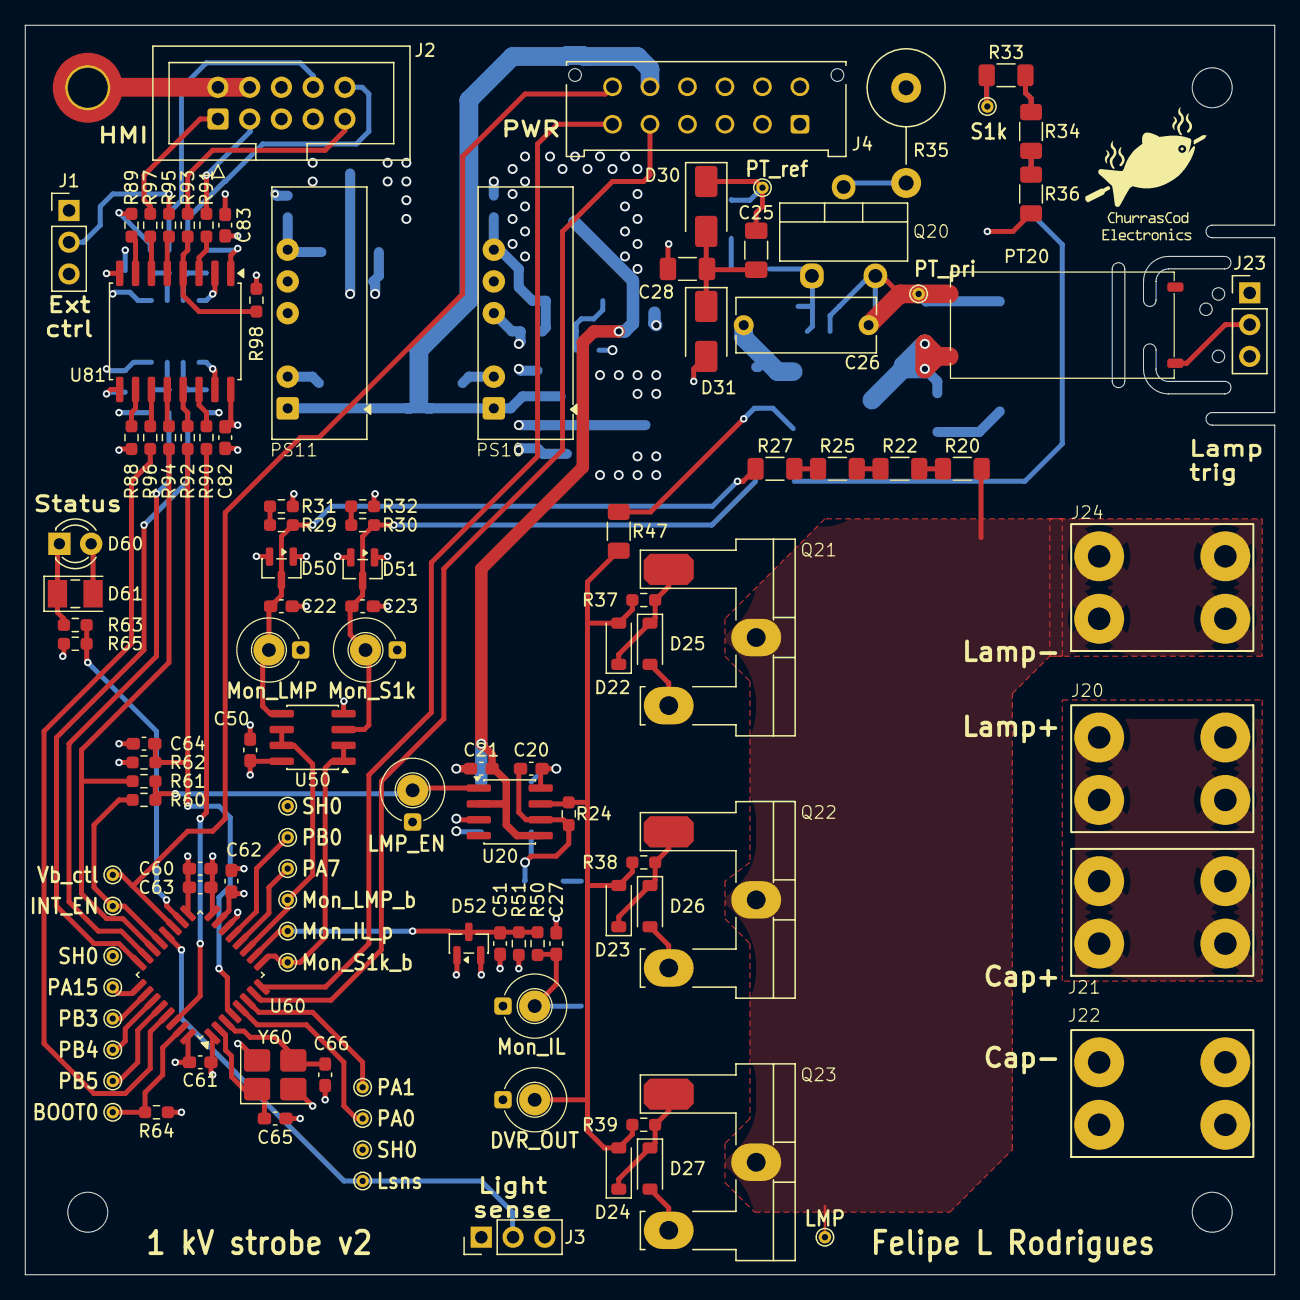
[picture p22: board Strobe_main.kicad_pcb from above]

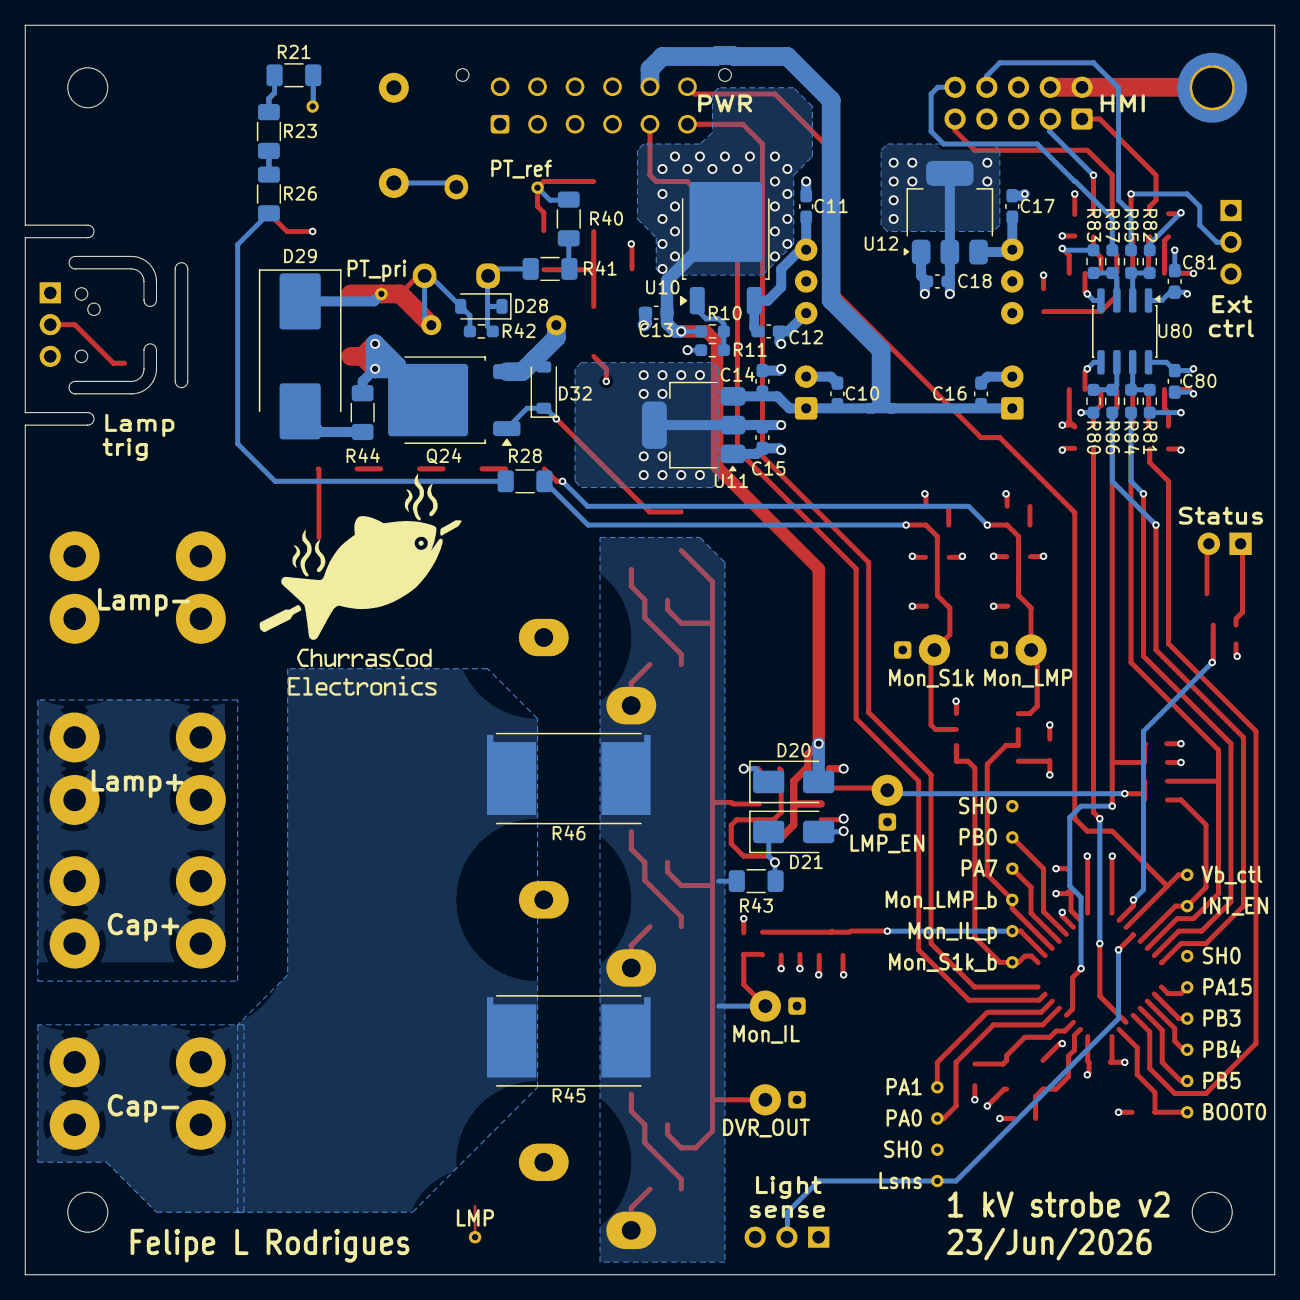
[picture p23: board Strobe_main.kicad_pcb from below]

Board: 4 copper layers, 100.0 x 100.0 mm, 165 parts (42 on the bottom side), 89 nets.

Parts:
C10, C11, C13, C14, C16, C17, C60: 1u; C_0603_1608Metric_Pad1.08x0.95mm_HandSolder
C12, C15, C18, C20, C21, C22, C23, C27, C50, C61, C62, C63, C64, C80, C81, C82, C83: 100n; C_0603_1608Metric_Pad1.08x0.95mm_HandSolder
C25, C28: 100n; C_1206_3216Metric_Pad1.33x1.80mm_HandSolder
C26: 47n; C_Rect_L11.0mm_W4.2mm_P10.00mm_MKT
C51: 4n7; C_0603_1608Metric_Pad1.08x0.95mm_HandSolder
C65, C66: 22p; C_0603_1608Metric_Pad1.08x0.95mm_HandSolder
D20, D21: B360; D_SMA
D22, D23, D24: 1N4148; D_SOD-123
D25, D26, D27, D28, D32: 20 V; D_SOD-123
D29: S15M; D_SMC_Handsoldering
D30, D31: 1SMA5953B; D_SMA
D50, D51, D52: BAV199; SOT-23
D60: LED; LED_D3.0mm
D61: LED; LED_PLCC-2_3x2mm_KA
H1, H3, H4: MountingHole; MountingHole_3.2mm_M3
H2: MountingHole_Pad; MountingHole_3.2mm_M3_DIN965_Pad_TopBottom
H20, H21, H22: MountingHole; Hole_1.0mm
J1, J3, J23: Header; PinHeader_1x03_P2.54mm_Vertical
J2: ZHOURI DC3; IDC-Header_2x05_P2.54mm_Vertical
J4: Molex 430451227; Molex_Micro-Fit_3.0_43045-1212_2x06_P3.00mm_Vertical
J20, J21, J22, J24: T44007
PS10: B0524S-2W; DCDC_converter_THT_BxxxxS-2W
PS11: B0505S-2W; DCDC_converter_THT_BxxxxS-2W
PT20: ZS1052-S_HT
Q20: MPF3N150; To-220_staggered_3
Q21, Q22, Q23: IXYH55N120; TO-247_mixed_pads_vert
Q24: MDT7N65; TO-252-2
R10: 470; R_0603_1608Metric_Pad0.98x0.95mm_HandSolder
R11: 6k8; R_0603_1608Metric_Pad0.98x0.95mm_HandSolder
R20, R21, R22, R23, R25, R26, R27, R28: 510k; R_1206_3216Metric_Pad1.30x1.75mm_HandSolder
R24: 15k; R_0603_1608Metric_Pad0.98x0.95mm_HandSolder
R29, R30, R31, R32: 3k3; R_0603_1608Metric_Pad0.98x0.95mm_HandSolder
R33, R34, R36: 330k; R_1206_3216Metric_Pad1.30x1.75mm_HandSolder
R35: 100k; R_Axial_DIN0617_L17.0mm_D6.0mm_P7.62mm_Vertical
R37, R38, R39: 91R; R_0603_1608Metric_Pad0.98x0.95mm_HandSolder
R40, R41: 110k; R_1206_3216Metric_Pad1.30x1.75mm_HandSolder
R42: 100k; R_0603_1608Metric_Pad0.98x0.95mm_HandSolder
R43: 22R; R_1206_3216Metric_Pad1.30x1.75mm_HandSolder
R44: 1R; R_1206_3216Metric_Pad1.30x1.75mm_HandSolder
R45, R46: 20m; R_Shunt_Vishay_WSR2_WSR3_KelvinConnection
R47: 10R; R_1206_3216Metric_Pad1.30x1.75mm_HandSolder
R50, R51: 220; R_0603_1608Metric_Pad0.98x0.95mm_HandSolder
R60, R61, R84, R85, R86, R87, R90, R91, R92, R93, R94, R95, R96, R97: 0R; R_0603_1608Metric_Pad0.98x0.95mm_HandSolder
R62, R64, R65, R88, R89, R98: 10k; R_0603_1608Metric_Pad0.98x0.95mm_HandSolder
R63: 1k; R_0603_1608Metric_Pad0.98x0.95mm_HandSolder
R80, R81, R82, R83: 4k7; R_0603_1608Metric_Pad0.98x0.95mm_HandSolder
TP20, TP21, TP22, TP23, TP28: Testpoint_osc_probe; Testpoint_osc_no_lead
TP24, TP25, TP26, TP27, TP60, TP61, TP62, TP63, TP64, TP65, TP66, TP67, TP68, TP69, TP70, TP71, TP72, TP73, TP74, TP75, TP76, TP77: TestPoint; TestPoint_THTPad_D1.0mm_Drill0.5mm
U10: LM217MDT; TO-252-2
U11, U12: NCP1117IST33T3G; SOT-223-3_TabPin2
U20: IRS2184; SOIC-8_3.9x4.9mm_P1.27mm
U50: TSV912IDT; SOIC-8_3.9x4.9mm_P1.27mm
U60: STM32G431K8Tx; LQFP-32_7x7mm_P0.8mm
U80: ISO1541; SOIC-8_3.9x4.9mm_P1.27mm
U81: ISO6741; SOIC-16W_7.5x10.3mm_P1.27mm
Y60: 20 MHz; Crystal_SMD_3225-4Pin_3.2x2.5mm_HandSoldering

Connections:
/Block Diagram/Ext_EN: J1.2, R95.2
/Block Diagram/GND: C17.2, C18.2, C81.2, C83.2, J1.1, J2.5, J2.7, PS11.4 (-Vout), R98.2, U12.1 (GND), U80.4 (GND1), U81.2 (GND1), U81.8 (GND1)
/Block Diagram/Lamp driver/DRV_OUT: D22.2 (A), D23.2 (A), D24.2 (A), R24.2, R37.1, R38.1, R39.1, R47.1, TP20.1 (Sig), U20.7 (HO)
/Block Diagram/Lamp driver/DRV_RET: C20.2, D21.1 (K), R24.1, R43.2, U20.6 (VS)
/Block Diagram/Lamp driver/G_L_D1: D22.1 (K), D25.1 (K), Q21.1 (G), R37.2
/Block Diagram/Lamp driver/G_L_D2: D23.1 (K), D26.1 (K), Q22.1 (G), R38.2
/Block Diagram/Lamp driver/G_L_D3: D24.1 (K), D27.1 (K), Q23.1 (G), R39.2
/Block Diagram/Lamp driver/G_TP_DRV: D32.1 (K), Q24.1 (G), R47.2
/Block Diagram/Lamp driver/G_TP_REF: D28.1 (K), Q20.1 (G), R41.2, R42.1
/Block Diagram/Lamp driver/LMP: J24.1, Q21.2 (C), Q22.2 (C), Q23.2 (C), R20.2, TP25.1
/Block Diagram/Lamp driver/LMP_EN: R60.2, R61.2, TP21.1 (Sig), U20.1 (IN)
/Block Diagram/Lamp driver/Mon_IL: C27.1, D25.2 (A), D26.2 (A), D27.2 (A), Q21.3 (E), Q22.3 (E), Q23.3 (E), R43.1, R45.1, R46.1, R50.1, TP28.1 (Sig)
/Block Diagram/Lamp driver/Mon_LMP: C22.1, D50.3 (K), R27.1, R29.2, TP22.1 (Sig), U50.5 (+)
/Block Diagram/Lamp driver/Mon_S1k: C23.1, D51.3 (K), R28.1, R30.2, TP23.1 (Sig), U50.3 (+)
/Block Diagram/Lamp driver/REF_M: C25.2, C28.1, D30.2 (A), D31.1 (K)
/Block Diagram/Lamp driver/TP_COM: PT20.1 (C), Q24.2 (D), R44.1
/Block Diagram/Lamp driver/TP_DRV_COL: Q20.2 (D), R35.2
/Block Diagram/Lamp driver/TP_INT: D29.2 (A), R44.2
/Block Diagram/Lamp driver/TP_PRI: C26.1, D28.2 (A), D29.1 (K), PT20.2, Q20.3 (S), R42.2, TP27.1
/Block Diagram/Lamp driver/TP_REF: C25.1, D30.1 (K), R36.1, R40.1, TP26.1
/Block Diagram/Lamp driver/TP_RM: R40.2, R41.1
/Block Diagram/Lamp driver/TRIG: J23.2, PT20.4 (S)
/Block Diagram/Lamp driver/VBS: C20.1, D20.1 (K), U20.8 (VB)
/Block Diagram/Light_sns: J3.2, TP71.1, U60.20 (PA10)
/Block Diagram/MCU/BOOT0: R64.1, TP73.1, U60.31 (PB8)
/Block Diagram/MCU/HV_EXT_EN: R61.1, R94.1, U60.22 (PA12)
/Block Diagram/MCU/HV_NRST: C64.1, R62.2, R92.1, U60.4 (PG10)
/Block Diagram/MCU/HV_RX: R90.1, U60.30 (PB7)
/Block Diagram/MCU/HV_SWDCLK: R86.1, U60.24 (PA14)
/Block Diagram/MCU/HV_SWDIO: R84.1, U60.23 (PA13)
/Block Diagram/MCU/HV_TX: R96.1, U60.29 (PB6)
/Block Diagram/MCU/INT_EN: R60.1, TP72.1, U60.21 (PA11)
/Block Diagram/MCU/Mon_IL_prot: C51.1, D52.3 (K), R50.2, R51.2, TP64.1, U60.10 (PA5)
/Block Diagram/MCU/Mon_LMP_buf: TP66.1, U50.6 (-), U50.7, U60.11 (PA6)
/Block Diagram/MCU/Mon_S1k_buf: TP62.1, U50.1, U50.2 (-), U60.9 (PA4)
/Block Diagram/MCU/ST_LED: R63.2, R65.1, U60.18 (PA8)
/Block Diagram/MCU/SUP_RX: J4.6, U60.8 (PA3)
/Block Diagram/MCU/SUP_TX: J4.5, U60.7 (PA2)
/Block Diagram/Optical isolation/LV_NRST: J2.9, R93.2
/Block Diagram/Optical isolation/LV_RX: J2.1, R97.2
/Block Diagram/Optical isolation/LV_SWDCLK: J2.10, R87.2
/Block Diagram/Optical isolation/LV_SWDIO: J2.8, R85.2
/Block Diagram/Optical isolation/LV_TX: J2.3, R91.2
/Block Diagram/Power supply/SH24: C11.1, C12.1, PS10.6 (+Vout), U10.3 (VI)
/Block Diagram/Power supply/SL5: C17.1, PS11.6 (+Vout), U12.3 (VI)
/Block Diagram/S1k: J4.7, J20.1, J21.1, R21.2, R33.1, R35.1, TP24.1
/Block Diagram/SH0: C10.2, C11.2, C12.2, C13.2, C14.2, C15.2, C16.2, C21.2, C22.2, C23.2, C26.2, C27.2, C28.2, C50.2, C51.2, C60.2, C61.2, C62.2, C63.2, C64.2, C65.2, C66.2, C80.2, C82.2, D21.2 (A), D31.2 (A), D32.2 (A), D50.1 (K), D51.1 (K), D52.1 (K), J3.3, J4.4, J4.10, J22.1, PS10.2 (-Vin), PS10.4 (-Vout), PS11.2 (-Vin), Q24.3 (S), R11.2, R31.1, R32.1, R45.2, R46.2, R51.1, R64.2, R65.2, TP20.2 (Ref), TP21.2 (Ref), TP22.2 (Ref), TP23.2 (Ref), TP28.2 (Ref), TP75.1, TP76.1, TP77.1, U11.1 (GND), U20.3 (COM), U50.4 (V-), U60.14 (VSSA), U60.16 (VSS), U60.32 (VSS), U80.5 (GND2), U81.9 (GND2), U81.15 (GND2), Y60.2 (G), Y60.4 (G)
/Block Diagram/SH3: C15.1, C50.1, C60.1, C61.1, C62.1, C63.1, C80.1, C82.1, D50.2 (A), D51.2 (A), D52.2 (A), D60.2 (A), D61.2 (A), J3.1, R62.1, R80.1, R81.1, R88.1, U11.2 (VO), U50.8 (V+), U60.1 (VDD), U60.15 (VDDA), U60.17 (VDD), U80.8 (VCC2), U81.16 (V_{CC2})
/Block Diagram/SH5: C10.1, C14.1, C16.1, J4.11, PS10.1 (+Vin), PS11.1 (+Vin), U11.3 (VI)
/Block Diagram/SH20: C13.1, C21.1, D20.2 (A), R10.1, U10.2 (VO), U20.2 (~SD), U20.5 (VCC)
/Block Diagram/SL3: C18.1, C81.1, C83.1, J1.3, J2.6, R82.1, R83.1, R89.1, U12.2 (VO), U80.1 (VCC1), U81.1 (V_{CC1})
/Block Diagram/Vbus_ctrl: J4.12, TP70.1, U60.19 (PA9)
Earth: H2.1, J2.2, J2.4
unnamed: D60.1 (K), D61.1 (K), R63.1
unnamed: R20.1, R22.2
unnamed: R21.1, R23.2
unnamed: R22.1, R25.2
unnamed: R23.1, R26.2
unnamed: R25.1, R27.2
unnamed: R26.1, R28.2
unnamed: R29.1, R31.2
unnamed: R30.1, R32.2
unnamed: R33.2, R34.1
unnamed: R34.2, R36.2
unnamed: R10.2, R11.1, U10.1 (ADJ)
unnamed: TP60.1, U60.5 (PA0)
unnamed: TP61.1, U60.6 (PA1)
unnamed: TP68.1, U60.12 (PA7)
unnamed: TP74.1, U60.25 (PA15)
unnamed: TP63.1, U60.13 (PB0)
unnamed: TP65.1, U60.26 (PB3)
unnamed: TP67.1, U60.27 (PB4)
unnamed: TP69.1, U60.28 (PB5)
unnamed: C65.1, U60.2 (PF0), Y60.1
unnamed: C66.1, U60.3 (PF1), Y60.3
unnamed: R83.2, R87.1, U80.3 (SCL1)
unnamed: R80.2, R86.2, U80.6 (SCL2)
unnamed: R82.2, R85.1, U80.2 (SDA1)
unnamed: R81.2, R84.2, U80.7 (SDA2)
unnamed: R89.2, U81.7 (EN1)
unnamed: R88.2, U81.10 (EN2)
unnamed: R91.1, U81.3 (INA)
unnamed: R93.1, R98.1, U81.4 (INB)
unnamed: R95.1, U81.5 (INC)
unnamed: R96.2, U81.11 (IND)
unnamed: R90.2, U81.14 (OUTA)
unnamed: R92.2, U81.13 (OUTB)
unnamed: R94.2, U81.12 (OUTC)
unnamed: R97.1, U81.6 (OUTD)

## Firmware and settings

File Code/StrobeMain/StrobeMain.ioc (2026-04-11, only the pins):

Mcu.UserName=STM32G431K8Tx
PA0.GPIO_Label=U_SH1000
PA0.Signal=ADC1_IN1
PA1.GPIO_Label=U_SH240
PA1.Signal=ADC1_IN2
PA11.GPIO_Label=LAMP_EN
PA11.Signal=GPIO_Output
PA12.GPIO_Label=TP516
PA12.Signal=GPIO_Output
PA13.Signal=SYS_JTMS-SWDIO
PA14.Signal=SYS_JTCK-SWCLK
PA15.Signal=GPIO_Output
PA2.GPIO_Label=I_SH240
PA2.Signal=ADC1_IN3
PA3.GPIO_Label=I_SH1000
PA3.Signal=ADC1_IN4
PA4.GPIO_Label=U_L
PA4.Signal=ADC2_IN17
PA5.GPIO_Label=I_P
PA5.Signal=ADC2_IN13
PA6.GPIO_Label=U_C
PA6.Signal=ADC2_IN3
PA7.GPIO_Label=TP511
PA7.Signal=GPIO_Output
PA8.GPIO_Label=ST_LED
PA8.Signal=GPIO_Output
PB0.GPIO_Label=TP506
PB0.Signal=GPIO_Output
PB3.GPIO_Label=TP508
PB3.Signal=GPIO_Output
PB4.GPIO_Label=TP510
PB4.Signal=GPIO_Output
PB5.GPIO_Label=TP512
PB5.Signal=GPIO_Output
PB6.GPIO_Label=HV_TX
PB6.Signal=USART1_TX
PB7.GPIO_Label=HV_RX
PB7.Signal=USART1_RX
PF0-OSC_IN.Signal=RCC_OSC_IN
PF1-OSC_OUT.Signal=RCC_OSC_OUT

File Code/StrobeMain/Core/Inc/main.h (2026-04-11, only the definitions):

#define U_SH1000_Pin LL_GPIO_PIN_0
#define U_SH1000_GPIO_Port GPIOA
#define U_SH240_Pin LL_GPIO_PIN_1
#define U_SH240_GPIO_Port GPIOA
#define I_SH240_Pin LL_GPIO_PIN_2
#define I_SH240_GPIO_Port GPIOA
#define I_SH1000_Pin LL_GPIO_PIN_3
#define I_SH1000_GPIO_Port GPIOA
#define U_L_Pin LL_GPIO_PIN_4
#define U_L_GPIO_Port GPIOA
#define I_P_Pin LL_GPIO_PIN_5
#define I_P_GPIO_Port GPIOA
#define U_C_Pin LL_GPIO_PIN_6
#define U_C_GPIO_Port GPIOA
#define TP511_Pin LL_GPIO_PIN_7
#define TP511_GPIO_Port GPIOA
#define TP506_Pin LL_GPIO_PIN_0
#define TP506_GPIO_Port GPIOB
#define ST_LED_Pin LL_GPIO_PIN_8
#define ST_LED_GPIO_Port GPIOA
#define LAMP_EN_Pin LL_GPIO_PIN_11
#define LAMP_EN_GPIO_Port GPIOA
#define TP516_Pin LL_GPIO_PIN_12
#define TP516_GPIO_Port GPIOA
#define TP508_Pin LL_GPIO_PIN_3
#define TP508_GPIO_Port GPIOB
#define TP510_Pin LL_GPIO_PIN_4
#define TP510_GPIO_Port GPIOB
#define TP512_Pin LL_GPIO_PIN_5
#define TP512_GPIO_Port GPIOB
#define HV_TX_Pin LL_GPIO_PIN_6
#define HV_TX_GPIO_Port GPIOB
#define HV_RX_Pin LL_GPIO_PIN_7
#define HV_RX_GPIO_Port GPIOB
#define NVIC_PRIORITYGROUP_0         ((uint32_t)0x00000007) /*!< 0 bit  for pre-emption priority,
#define NVIC_PRIORITYGROUP_1         ((uint32_t)0x00000006) /*!< 1 bit  for pre-emption priority,
#define NVIC_PRIORITYGROUP_2         ((uint32_t)0x00000005) /*!< 2 bits for pre-emption priority,
#define NVIC_PRIORITYGROUP_3         ((uint32_t)0x00000004) /*!< 3 bits for pre-emption priority,
#define NVIC_PRIORITYGROUP_4         ((uint32_t)0x00000003) /*!< 4 bits for pre-emption priority,

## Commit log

2026-02-18 Sch copy in progress
    [Block Diagram.kicad_sch, High_supply.kicad_sch, Lamp_drive.kicad_sch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]
2026-02-18 Update Outputs
    [Strobe_main-bom.csv]
2026-02-18 Deleting old sch files
    [Power - Sequencing.kicad_sch, Project Architecture.kicad_sch, Section A - Title A.kicad_sch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]
2026-02-19 Reworked sheet titles
    [Block Diagram.kicad_sch, HV_side_supply.kicad_sch, LV_side_supply.kicad_sch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]
2026-02-19 Reworked sheet titles and changelog
    [Block Diagram.kicad_sch]
2026-02-19 reverted to draft
    [Strobe_main.kicad_sch]
2026-02-19 Added PCB
    [Block Diagram.kicad_sch, HV_side_supply.kicad_sch, LV_side_supply.kicad_sch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]
2026-02-19 Added some libraries to project folder
    [Strobe_main.kicad_pcb]
2026-02-19 added more 3d models and paths
    [Strobe_main.kicad_pcb]
2026-02-19 added missing 3d step files
    [Strobe_main.kicad_pcb]
2026-02-19 Added z offset to DCDC modules
    [Strobe_main.kicad_pcb]
2026-02-20 Started update of mfg docs
    [Strobe_main.kicad_pcb]
2026-02-20 Updating mfg docs
    [Strobe_main.kicad_pcb]
2026-02-20 Updating sheet size on yaml
    [Strobe_main.kicad_sch]
2026-02-20 added 3d model for J501
    [Strobe_main.kicad_pcb]
2026-02-20 Updated fab layer
    [Strobe_main.kicad_pcb]
2026-02-20 added firmware
    [Strobe_main.kicad_sch]
2026-04-08 Setting up repo on another machine
    [Block Diagram.kicad_sch, HV_side_supply.kicad_sch, LV_side_supply.kicad_sch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]
2026-04-08 Trigger ci
    [Block Diagram.kicad_sch, HV_side_supply.kicad_sch, LV_side_supply.kicad_sch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]
2026-04-09 Readme updated
    [Block Diagram.kicad_sch, HV_side_supply.kicad_sch, LV_side_supply.kicad_sch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]
2026-04-10 updating BOM info
    [Block Diagram.kicad_sch, HV_side_supply.kicad_sch, LV_side_supply.kicad_sch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]
2026-04-11 mfg docs updated
    [Strobe_main.kicad_pcb]
2026-04-11 Checked. Preparing release
    [HV_side_supply.kicad_sch, LV_side_supply.kicad_sch, Lamp_driver.kicad_sch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]
2026-04-11 Update Outputs (release)
    [Strobe_main.kicad_pcb]
2026-05-28 Preparing release
    [Revision History.kicad_sch]
2026-06-02 Sch update in progress
    [Block Diagram.kicad_sch, Lamp_driver.kicad_sch, MCU.kicad_sch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]
2026-06-02 Sch update in progres
    [Block Diagram.kicad_sch, MCU.kicad_sch, Power_supply.kicad_sch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]
2026-06-03 Sch update complete, ERC OK
    [Block Diagram.kicad_sch, HV_side_supply.kicad_sch, LV_side_supply.kicad_sch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]
2026-06-05 Placement started
    [Block Diagram.kicad_sch, Strobe_main.kicad_pcb]
2026-06-06 Placement 50%
    [Lamp_driver.kicad_sch, MCU.kicad_sch, Power_supply.kicad_sch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]
2026-06-07 Updated pulse transofrmer circuit
    [Lamp_driver.kicad_sch, Strobe_main.kicad_pcb]
2026-06-08 Placement updates
    [Lamp_driver.kicad_sch, Strobe_main.kicad_pcb]
2026-06-09 New placement strategy
    [Block Diagram.kicad_sch, Lamp_driver.kicad_sch, Strobe_main_de1.kicad_pcb]
2026-06-09 TP placement candidate 90%
    [Block Diagram.kicad_sch, Lamp_driver.kicad_sch, Strobe_main.kicad_pcb]
2026-06-11 Updated some clearance rules
    [Lamp_driver.kicad_sch, Strobe_main.kicad_pcb]
2026-06-11 Placement complplete, feasibility routing complete
    [Block Diagram.kicad_sch, Lamp_driver.kicad_sch, MCU.kicad_sch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]
2026-06-12 MCU routed
    [Strobe_main.kicad_pcb]
2026-06-12 Routing complete, silk to do, vias to check, one footprint to update
    [Lamp_driver.kicad_sch, MCU.kicad_sch, Strobe_main.kicad_pcb]
2026-06-13 Reannotated, silk done, missing some 3D models
    [Block Diagram.kicad_sch, Lamp_driver.kicad_sch, MCU.kicad_sch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]
2026-06-14 3D models added
    [Lamp_driver.kicad_sch, Strobe_main.kicad_pcb]
2026-06-14 Copied libraries
    [Block Diagram.kicad_sch]
2026-06-14 Forcing CI
    [Strobe_main.kicad_pcb]
2026-06-14 Updated paths to 3D models
    [Strobe_main.kicad_pcb]
2026-06-14 Testing paths
    [Strobe_main.kicad_pcb]
2026-06-14 Testing path 2
    [Strobe_main.kicad_pcb]
2026-06-14 Paths fixed
    [Strobe_main.kicad_pcb]
2026-06-17 Addupdated edge cuts near trigger output
    [Strobe_main.kicad_pcb]
2026-06-18 Updating mfg layers
    [Lamp_driver.kicad_sch, Strobe_main.kicad_pcb]
2026-06-22 Changed to checked, updated fab pdf yaml
    [Block Diagram.kicad_sch, Lamp_driver.kicad_sch, MCU.kicad_sch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]
2026-06-23 Updated thermal reliefs and fiing holes positions
2026-06-23 Preparing release from dev2
    [Block Diagram.kicad_sch, Revision History.kicad_sch]
2026-09-05 Updated C22 and C23
    [Lamp_driver.kicad_sch, Revision History.kicad_sch, Strobe_main.kicad_sch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]
2026-09-05 rectifying fab script
    [Strobe_main.kicad_pcb]
2026-09-05 new attempt to fix fab script
    [Strobe_main.kicad_pcb]

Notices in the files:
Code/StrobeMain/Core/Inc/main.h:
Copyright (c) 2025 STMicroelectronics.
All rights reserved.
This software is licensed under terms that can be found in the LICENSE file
